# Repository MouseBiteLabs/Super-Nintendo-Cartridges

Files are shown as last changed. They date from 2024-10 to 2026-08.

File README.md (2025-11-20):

# Super Nintendo Game Cartridges

This is a repository listing all of my Super Nintendo Cartridge board variants. These *do not* include variants with special chips, such as SA-1 or the Super Game Boy boards. This repository is for the "standard" mapping types.

Use the following table (or navigate the above folders) for information on each specific baord type. <a href="https://github.com/MouseBiteLabs/Super-Nintendo-Cartridges/wiki">Please also review the wiki for more information.</a>

Note that the boards listed below are planned for development. No dates for upload are guaranteed.

## SNES Board Variants

| **Board Name** | **Board Number** | **Max ROM Size** | **Max RAM Size** | **Mappings Supported** | **Multicart Support?** | **Memory Family Used** |
|---|---|---|---|---|---|---|
| <a href="https://github.com/MouseBiteLabs/Super-Nintendo-Cartridges/tree/main/Advanced%20Flash">Advanced Flash</a> | SNES-8XJ4D-01A | 8 MB | 32 KB | LoROM, HiROM, ExLoROM, ExHiROM | Yes (2 games; 4MB ROM, 32KB RAM)  | Type A (M29F160) |
| <a href="https://github.com/MouseBiteLabs/Super-Nintendo-Cartridges/tree/main/LoROM%20Flash">LoROM Flash</a> | SNES-8XL8D-01A | 8 MB | 128 KB | LoROM, ExLoROM | Yes (2 games; 4MB ROM, 32KB RAM)  | Type A (M29F160) |
| <a href="https://github.com/MouseBiteLabs/Super-Nintendo-Cartridges/tree/main/HiROM%20Flash">HiROM Flash</a> | SNES-8XH8D-01A | 8 MB | 128 KB | HiROM, ExHiROM | Yes (2 games; 4MB ROM, 32KB RAM)  | Type A (M29F160) |
| <a href="https://github.com/MouseBiteLabs/Super-Nintendo-Cartridges/tree/main/Advanced%20UV">Advanced UV</a> | SNES-8XJ8D-01C | 8 MB | 128 KB | LoROM, HiROM, ExLoROM, ExHiROM | Yes (2 games; 4MB ROM, 32KB RAM)  | Type C (27C322) |
| <a href="https://github.com/MouseBiteLabs/Super-Nintendo-Cartridges/tree/main/Basic%20UV">Basic UV</a> | SNES-4NJ8D-01C | 4 MB | 128 KB | LoROM, HiROM | No | Type C (27C160) |
| <a href="https://github.com/MouseBiteLabs/Super-Nintendo-Cartridges/tree/main/SA-1">SA-1</a> | SNES-4SA8S-01C | 4 MB | 128 KB | N/A | No | Type C (27C322) |

## Naming Convention

| SNES | \- | 8 | X | J | 4 | D | \- | 01 | A |
| --- | -- | --- | --- | --- | --- | --- | -- | --- | --- |
| Super Nintendo Entertainment System | | Max ROM Size (MB) | Ex Mode Support | Mapper Type(s) | Max RAM Size | Multicart Support | | Revision | Memory Family |
| | | 1 | N = No | L = LoROM | 0 = None | S = Single game | | | A = New EEPROM (M29F160) |
| | | 2 | X = Yes | H = HiROM | 1 = 2 KB | D = Multicart (split max ROM space)  | | | B = NOS EEPROM (29F016, 29F032, 29F033) |
| | | 4 | | J = Both | 2 = 8 KB | M = Multicart (double max ROM space) | | | C = UV EPROMs (27C160, 27C322, etc) |
| | | 6 | SA = | SA1 | 4 = 32 KB | | | | |
| | | 8 | | | 8 = 128 KB | | | | |

## License

<br />This work is licensed under a <a rel="license" href="http://creativecommons.org/licenses/by-sa/4.0/">Creative Commons Attribution-ShareAlike 4.0 International License</a>. You are able to copy and redistribute the material in any medium or format, as well as remix, transform, or build upon the material for any purpose (even commercial) - but you **must** give appropriate credit, provide a link to the license, and indicate if any changes were made.

©MouseBiteLabs 2024

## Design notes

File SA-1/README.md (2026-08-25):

# Super Nintendo SA-1 Cartridge (SNES-4SA8S-01C)

# V1.1 IS UNTESTED

This is a SNES cartridge circuit board that houses the proprietary SA-1 processor that was used in a variety of more advanced SNES games. This board should be able to be used as a replacement for all released SA-1 games, as well as many (if not all) SA-1 homebrews or enhanced games. The ROM can be programmed to the popular 27C160 or 27C322 UV EPROM chips, or if you want to use more modern and new components, you can use <a href="https://github.com/MouseBiteLabs/ROM-Adapter-Boards/tree/main/29F160%20to%20UV%20EPROM">my 29F160 to UV EPROM adapter boards</a>. I have also included two options for battery management - a donor MM1026 chip from an original SA-1 cartridge (that has it), or if an MM1026 is not available to use you can use the modern TPS3613 battery management IC.

FRONT

BACK

The board can fit in SNES shells for games that used enhancement chips, as well as standard SNES games (with some minor cutting), and provides:
- Up to 4 MB of ROM space
- Up to 128 KB of RAM space

All gerbers and source files can be found in this repo, as again, this project is fully open source. Please read all instructions before attempting the project.

## V1.0 Error

If you have a v1.0 board, you can use this web applet by Bonzo to fix your ROM before programming it: https://eprom-pin-swapper.vercel.app/?preset=bmsa1

You will need to do this to any ROM going onto a v1.0 board before soldering in the chip.

## Important Things Before You Start

1) <a href="https://github.com/MouseBiteLabs/Super-Nintendo-Cartridges/wiki">Please review the wiki for more information about using the circuit boards, instructions for how to program them, and example builds.</a>
2) This project requires you remove the SA-1 chip from an original SA-1 SNES cartridge - <a href="https://en.wikipedia.org/wiki/List_of_Super_NES_enhancement_chips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">you can find a list of SA-1 games that you can use as a donor here (make sure you sort by chip type)</a>. This will require a hot air rework station or a hot plate. This will also require extensive soldering capabilities - do not attempt this project if you do not have sufficient soldering experience.
3) When soldering parts on, it's a good idea to put kapton tape or otherwise cover the bottom cartridge edge. You do not want to get solder on the cartridge contacts.
4) I am not responsible for any damage you do to your self or your property. Attempt this project at your own risk.
5) I do not guarantee design compatibility. You may encounter issues with certain games. There is also a chance I have made an error in the design or the BOM - if this is the case, I will do everything I can to address the problem as quickly as possible.
6) If you are using this board to make games other than for personal use, you must have permission from the originator to use and distribute any ROM images or other related material. You are responsible for making sure you adhere to any license requirements.

DO NOT use my circuit boards for profiting from stolen work - this especially includes homebrew content, ROM hacks, and using fan-made labels without permission from the originator. **Support ALL original creators!**

## Board Characteristics and Order Information

The zipped folder contains all the gerber files for this board. The following options **must** be chosen when ordering boards for yourself.

- Thickness: 1.2mm
- Surface Finish: ENIG
- Gold Fingers: Yes, 30° chamfer

You can use the zipped folder at any board fabricator you like (NOT YET AVAILABLE). You may also buy the board from PCBWay using this link (disclosure: I receive 10% of the sale value to go towards future PCB orders of my own):

<a href="https://www.pcbway.com/">PCB from PCBWay</a>

### Purchase from My Website

You can purchase this circuit board at my website, [https://mousebitelabs.store](https://mousebitelabs.store). Click the following image to be directed to the specific item listing:

<a href="https://mousebitelabs.store/products/super-nintendo-cartridge-circuit-board-sa-1">PCB from MouseBiteLabs</a>

### Purchase from Etsy

I also offer the board on Etsy, if you would rather purchase through there - click the banner to be redirected. (NOT YET LIVE)

<a href="https://mousebitelabs.etsy.com">PCB from Etsy</a> 

## Required Equipment

- You will need basic tools, like a soldering iron, hot plate, and/or hot air rework station.
- This board is **NOT** flashable with any cart flasher (until someone adds that capability) so you need a way to program the ROM chip(s) before soldering them on. There are a few ways I accomplish this:
  - Using the <a href="https://xgecu.myshopify.com/products/xgecu-new-t48-tl866-3gprogrammer-v12-01-support-28000-ics-for-spi-nor-nand-flash-emmc-bga153-162-169-100-221-tsop-sop-plcc">T48 programmer</a> with my <a href="https://github.com/MouseBiteLabs/27C322-TL866-Adapter">27C322 to TL866 Programming Adatper</a> board. The programming adapter is compatible with the T48, and it allows you to program the 42-pin EPROMs (27C160 and 27C322) with the 40-pin T48 programmer.
  OR
  - Using the <a href="https://www.mcumall.com/store/index.php?route=product/product&path=66&product_id=85">GQ4x4 programmer</a> with the ZIF adapter board that comes with it.
  OR
  - If you are using the 29F160 ROM adapter boards to place into the 27C322 footprint, you can program the 29F160 chips with the <a href="https://xgecu.myshopify.com/products/xgecu-new-t48-tl866-3gprogrammer-v12-01-support-28000-ics-for-spi-nor-nand-flash-emmc-bga153-162-169-100-221-tsop-sop-plcc">T48 programmer</a> and the <a href="https://xgecu.myshopify.com/products/100-original-xgecu-adp_f48_ex-1-tsop48-special-adapter-for-nor-flash-only-use-on-t48-tl866-3g-programmer">TSOP48 adapter</a>.
- You will need to do some shell cuts to get the board to fit if you're using a standard SNES cartridge shell (detailed later). I recommend using a file set - <a href="https://www.amazon.com/gp/product/B07R3R9461">I bought this one.</a> 

## How to Program

<a href="https://github.com/MouseBiteLabs/Super-Nintendo-Cartridges/wiki/Preparing-the-ROM">Please check out the wiki pages on how to prepare the ROM and program the cartridge.</a>

## Board Configurations

On this board, there are two sets of solder jumpers that need to be either bridged or not bridged. Furthermore, there are three two-way solder jumpers that are labeled SJx. Solder from the middle pad to the left or right pads as determined by the game you're making and parts you're using.

### JP1 - Internal RAM (IRAM) Configuration

This pad is bridged **by default**. If you wish to disconnect JP1, you must use a knife to cut the copper trace between the two pads of JP1. The only time this is applicable is for extremely specific SA-1 games that use the SA-1's internal RAM to save, instead of external RAM. There is only **one** instance of this that I was able to find - a Japan-only game called <a href="https://superfamicom.org/info/pachi-slot-monogatari-pal-kougyou-special">Pachi-Slot Monogatari: PAL Kougyou Special.</a> After severing JP1, you will need to connect a wire to the pad directly below JP1 to the battery bus (accessible on the positive pin of CB).



### JP2 - Battery Bypass Pads

If your game does not require the use of a backup battery because it doesn't save data, then you need to bridge the pads on JP2. You will notice that this is located underneath U4, which is the battery backup chip. Therefore you will not be able to bridge these pads if you are using U4. If you are instead using U5 for the battery management, then be sure **not** to bridge JP2.

### SJ1 - Region Selection

Solder the middle pad (SA-1 pin 127) to GND for NTSC or VCC for PAL. 

### SJ2 - SRAM Chip

If your game uses SRAM, and you are using the 6264 size of SRAM (like the AS6C6264), then solder to the left pad accordingly. If your game uses the 62256 or 1008 size SRAM, then solder to the right pad.

**NOTE:** If you are using a 6264 SRAM chip, you **must** populate R13 with a 10k ohm resistor (see BOM section below).

### SJ3 - UV EPROM Selection

This is pretty self explanatory. Solder according to the UV EPROM part number you are using (or faking with my ROM adapter board).

## Shell Cut Guide

The board shape takes into account both enhancement chip SNES games (like the ones that used the SA-1 chip) as well as the standard SNES shells for regular SNES games. The enhancement chip games add the two extra sets of 8 pins on either side of the cartridge edge, so if you're using a standard SNES shell, you'll need to cut spaces for those pins to stick through. <a href="https://github.com/MouseBiteLabs/Super-Game-Boy-Plus#standard-46-pin-snes-shell-cuts">Here are the example pictures from my Super Game Boy Plus guide on how to do this</a>. Simply mark with a sharpie on the shell where to cut, then use a file or some other tool to make those cuts to allow the extra pins to stick through.

370103546-1bbc2b1e-a284-4a2d-8b2a-e84a3a882a5d

370104005-20fd10d5-1b87-485e-89ae-0a075d0c2f13

## Extra Components

There are a handful of components on the board that never appear in any SA-1 game, and some that show up in a few but not all. A deeper analysis could provide more insight into the functions and rationale behind these added footprints, but that's not something I'm interested in performing myself. Generally, you should be ok to omit these parts. To indicate these, I bordered the components that are *usually* not required with a dashed line instead of solid lines. Those components are:

- R4, which is normally shorted on every cartridge (if you want to add a series resistor here, you must first cut the trace between the pads)
- FB1-FB8, which are ferrite beads for filtering high frequency noise, seen in a handful of cart types but likely not required (like R4, these are shorted by default)
- C13 and C14 *never* appear populated on any SA-1 board from what I can find on SNES Central

If you run into weird issues with your games, perhaps adding one/some of these components could aid in fixing them. Feel free to update me with any information you wish to share in this regard and I will update accordingly.

- C15, a 33pF capacitor, appears on boards released later in the life of the SNES, sometime around the end of 1996 as far as I can tell from board pictures on SNES Central. It is likely not *required* for operation, but perhaps it fixes some weird edge cases or graphical issues. In any case, I believe it's the same value as C12 (will confirm if I get the right board to measure it), so it doesn't hurt to include it in my opinion. But you technically shouldn't need it.

## Special Case Components

Two components have dashed boxes, but are required on the board only for specific scenarios:

- R12 will be populated *only if* you are making a game with RAM, **but not a back-up battery.** DO NOT populate R12 if you have either U4 or U5 populated.
- R13 will be populated *only if* you are using a 6264 SRAM chip, and if you are using anything larger this will remain unpopulated (this is a stand-in for some of the unmarked and masked off components near the battery on original boards).

## Extra Pads (Experimental Use)

I added a few pads to access unused pins if anyone wants to experiment with them.

- RA22 and RA23 go to SA-1 pins 80 and 81, respectively. These are extra ROM address pins. Using RA22 can increase the addressible ROM space to 8 MB, and RA23 can further expand it to 16 MB. This functionality is, as far as I know, theoretical. If someone knows of any homberew games that use this extra space, feel free to let me know.
- /ROMSEL is not used on this cartridge, but along with /WR, perhaps these could be wired up to a breakout board with ROM chips on them for programming through the cart edge using something like the <a href="https://github.com/sanni/cartreader">OSCR</a>. Again, this is theoretical and may not be possible - but the pads are there for whoever wants to experiment.
- The SRAM maxes out at 128KB, however one pin on the SA-1 (pin 104) that is unused has been reported to be an extra SRAM pin, which could theoretically expand the size of the SRAM to a maximum of 256KB. This extra address pin is connected to pin 1 on the SRAM package, which is an NC pin for 32-pin SRAM chips linked in the BOM section.

## Estimating Battery Life

To accurately estimate the battery life, measure the voltage across R1 using a multimeter in DC mV mode, touching the probes to the two test point pads on either side of R1 (on the back of the board). You should read something around 1 mV or less. If you are severely higher than 10 mV, like in the 100's of mV, then you have a problem on your board. (Did you *inappropriately* populate R12?)

Once you have a suitable voltage, find the milliamp-hour rating of your selected battery (preferrably from a datasheet). For example, a Renata CR2032 battery is rated for 225 mAh.

Now to estimate battery life, take the voltage measurement in mV and the battery rating in mAh, and plug it into this equation: 

Time (years) = Resistance of R1 (ohms) * Battery capacity (mAh) / Voltage (mV) / 8760

The factor of 8760 is for converting years to hours (24 hours in a day, 365 days in a year). The resistance of R1 is 1000 ohms. So for an example, if you measured 1 mV on R1 and are using a Renata CR2032, you would get 1000 * 225 / 1 / 8760 = **25.7 years.**

## Troubleshooting

<a href="https://github.com/MouseBiteLabs/Super-Nintendo-Cartridges/wiki/Troubleshooting-Tips">Please check out the wiki pages for troubleshooting tips.</a>

## Bill of Materials (BOM)

- Populate Group A for all carts. It will be the only group of components you need if you have no SRAM or battery on the board.
- Populate Group B to add battery back-up for save data retention.
- Populate Group C1 or C2 depending on the battery management IC you want to use. Only required if Group B is populated.
- Populate Group D to add RAM to the board (usually for save data retention).
- Populate Group E **ONLY IF** you have **NOT** populated Group B, Group C1, and Group C2 components.
- Populate Group F **ONLY IF** you are using 6264 SRAM from Group D - other SRAM types (62256 or 1008) **do not use** Group F components.

### Example Builds

Please see <a href="https://github.com/MouseBiteLabs/Super-Nintendo-Cartridges/wiki/SA%E2%80%901">the example page in the wiki</a> for a companion in keeping track of what parts are necessary for a given build. Equivalent PCB names from original SNES cartridges (SHVC-xxxx) are given when applicable.

### Group A - All Carts

| Reference | Value/Part Number | Package | Description | Source |
| --- | --- | --- | --- | --- |
| C1 | 22u | Radial 2.5mm spacing | Aluminum Electrolytic Capacitor | [https://mou.sr/4lzfiK1](https://mou.sr/4lzfiK1) |
| C2 | 0.01uF | 0603 | Capacitor (MLCC) | [https://mou.sr/3AsRwK1](https://mou.sr/3AsRwK1) |
| C4 | 0.01uF | 0603 | Capacitor (MLCC) | [https://mou.sr/3AsRwK1](https://mou.sr/3AsRwK1) |
| C6 | 0.1uF | 0603 | Capacitor (MLCC) | [https://mou.sr/3ENc15O](https://mou.sr/3ENc15O) |
| C7 | 0.01uF | 0603 | Capacitor (MLCC) | [https://mou.sr/3AsRwK1](https://mou.sr/3AsRwK1) |
| C8 | 0.01uF | 0603 | Capacitor (MLCC) | [https://mou.sr/3AsRwK1](https://mou.sr/3AsRwK1) |
| C9 | 0.01uF | 0603 | Capacitor (MLCC) | [https://mou.sr/3AsRwK1](https://mou.sr/3AsRwK1) |
| C10 | 0.01uF | 0603 | Capacitor (MLCC) | [https://mou.sr/3AsRwK1](https://mou.sr/3AsRwK1) |
| C12 | 33pF | 0603 | Capacitor (MLCC) | [https://mou.sr/4cYZLxw](https://mou.sr/4cYZLxw) |
| C15 | 33pF | 0603 | Capacitor (MLCC) | [https://mou.sr/4cYZLxw](https://mou.sr/4cYZLxw) |
| R2 | 510k | 0603 | Resistor | [https://mou.sr/3zi8ayj](https://mou.sr/3zi8ayj) |
| R3 | 1k | 0603 | Resistor | [https://mou.sr/3U0EvS4](https://mou.sr/3U0EvS4) |
| R5 | 1.5k | 0603 | Resistor | https://mou.sr/4aiZKUE |
| R6 | 220 | 0603 | Resistor | [https://mou.sr/3ARwrf3](https://mou.sr/3ARwrf3) |
| U1 | 27C322, 27C160 | DIP-42 | UV EPROM | AliExpress, eBay |
| U3 | SA-1 | QFP-128 | Co-processor | Donor cartridge |

### Group B - Adds Backup Battery

You will need to populate Group C1 or Group C2 in addition to Group B in order to add battery management to the board.

| Reference | Value/Part Number | Package | Description | Source |
| --- | --- | --- | --- | --- |
| B1 | CR2032 | CR2032 | Coin Cell Battery | [https://mou.sr/3Wj2m0G](https://mou.sr/3Wj2m0G) |
| R1 | 1k | 0603 | Resistor | [https://mou.sr/3U0EvS4](https://mou.sr/3U0EvS4) |

### Group C1 - Adds Battery Management IC (Donor Cart)

Use parts from Group C1 **OR** C2. Do not use both. Group C1 or C2 are required if a save battery is on the board.

| Reference | Value/Part Number | Package | Description | Source |
| --- | --- | --- | --- | --- |
| C11 | 0.01uF | 0603 | Capacitor (MLCC) | [https://mou.sr/3AsRwK1](https://mou.sr/3AsRwK1) |
| U4 | MM1026 | SOIC-8W | Battery Management | Donor cartridge |

### Group C2 - Adds Battery Management IC (New Parts)

Use parts from Group C1 **OR** C2. Do not use both. Group C1 or C2 are required if a save battery is on the board.

| Reference | Value/Part Number | Package | Description | Source |
| --- | --- | --- | --- | --- |
| C16 | 0.01uF | 0603 | Capacitor (MLCC) | [https://mou.sr/3AsRwK1](https://mou.sr/3AsRwK1) |
| R9 | 130k | 0603 | Resistor | [https://mou.sr/3MjXliy](https://mou.sr/3MjXliy) |
| R10 | 49.9k | 0603 | Resistor | [https://mou.sr/3BBcDgp](https://mou.sr/3BBcDgp) |
| U5 | TPS3613 | MSOP-10 | Battery Management | [https://mou.sr/45Ir2kh](https://mou.sr/45Ir2kh) |

### Group D - Adds SRAM

Select U2 according to the size of RAM your game requires - 6264 (8KB), 62256 (32KB), or 1008 (128KB).

| Reference | Value/Part Number | Package | Description | Source |
| --- | --- | --- | --- | --- |
| CB | 22u | Radial 2.5mm spacing | Aluminum Electrolytic Capacitor | [https://mou.sr/4lzfiK1](https://mou.sr/4lzfiK1) |
| C5 | 0.01uF | 0603 | Capacitor (MLCC) | [https://mou.sr/3AsRwK1](https://mou.sr/3AsRwK1) |
| U2 | AS6C6264/62256/1008 | SOP-28/SOP-32 | SRAM | https://mou.sr/4qIDtZh |

### Group E - For Using SRAM as Work RAM (no battery backup)

Only populate Group E **IF** your game does not have Group B or Group C components. **DO NOT POPULATE IF YOU HAVE A SAVE BATTERY ON THE BOARD.**

| Reference | Value/Part Number | Package | Description | Source |
| --- | --- | --- | --- | --- |
| R12 | 10k | 0603 | Resistor | [https://mou.sr/3riR7IH](https://mou.sr/3riR7IH) |

### Group F - Only If Using 6264 SRAM

Only populate Group F **IF** you are using 6264 series SRAM.

| Reference | Value/Part Number | Package | Description | Source |
| --- | --- | --- | --- | --- |
| R13 | 10k | 0603 | Resistor | [https://mou.sr/3riR7IH](https://mou.sr/3riR7IH) |

## Revision History

### v1.0 - Initial Release

## Acknowledgements

- Special thanks to Bonzo for providing an SA-1 board that I used for board scans and component measurements to develop the majority of this board!
- Huge, endless thanks to the following people for their hard work and resources:
  - <a href="https://problemkaputt.de/fullsnes.htm#snescartsa1games">nocash's SNES resources</a> were the single most helpful resource for this project.
  - <a href="https://github.com/VitorVilela7/SNES-SA-1-doc">VitorVilela's GitHub page</a> helped for filling out information about some of the pins, their connections, and component values.
  - <a href="https://snescentral.com/pcblisting.php">SNES Central's PCB archives</a> provided pictures of all the other major SA-1 game PCBs I did not have myself.
  - <a href="https://snescentral.com/pcblisting.php">This thread detailing Arthrimus/Markfrizb's SA-1 boards</a> helped for cross-referencing component values.
- Continual thanks to all in the nesdev community for their resources, design tips, and support throughout the past half-decade. This design was one of my original ones that was improved through their help and feedback when I was first starting out.

## License

<br />This work is licensed under a <a rel="license" href="http://creativecommons.org/licenses/by-sa/4.0/">Creative Commons Attribution-ShareAlike 4.0 International License</a>. You are able to copy and redistribute the material in any medium or format, as well as remix, transform, or build upon the material for any purpose (even commercial) - but you **must** give appropriate credit, provide a link to the license, and indicate if any changes were made.

©MouseBiteLabs 2025

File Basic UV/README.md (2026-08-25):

# Super Nintendo Basic UV Cartridge (SNES-4NJ8D-01C) 

# Order at your own risk -- v1.1 is untested

This is an updated design of my old <a href="https://mousebitelabs.com/2019/08/12/how-to-make-a-snes-reproduction-cartridge-quick-guide/">SNES Basic cartridge boards</a>, which can use the original mask ROM chips from SNES carts, or the older 27C160 UV EPROM chips. You can even use my <a href="https://github.com/MouseBiteLabs/ROM-Adapter-Boards/tree/main/29F160%20to%20UV%20EPROM">29F160 to 27C160 adapter boards</a>, which use brand new 29F160 flash chips if you don't want to deal with old parts. 

Functionally, this design is the same as the older one, but under the hood I have ported the project over from Eagle to KiCad, and heavily cleaned up the schematic and some of the trace routings. I also added support for the MAD-1 chip from a donor board, unlocking a lot of potential for replacing old or damaged games. This version is also fully open source.





This cartridge covers a large portion of the SNES library, capable of any standard cartridge **but not those with co-processors, such as SA-1 or SuperFX.** You can backup games onto it with the following settings:
- HiROM and LoROM memory maps
- Up to 4 MB of ROM space
- Up to 128 KB of RAM space

All gerbers and source files can be found in this repo, as again, this project is fully open source. Please read all instructions before attempting the project.

## Important Things Before You Start

1) <a href="https://github.com/MouseBiteLabs/Super-Nintendo-Cartridges/wiki">Please review the wiki for more information about using the circuit boards, instructions for how to program them, and example builds.</a>
2) When soldering parts on, it's a good idea to put kapton tape or otherwise cover the bottom cartridge edge. You do not want to get solder on the cartridge contacts.
3) I am not responsible for any damage you do to your self or your property. Attempt this project at your own risk.
4) I do not guarantee design compatibility. You may encounter issues with certain games. There is also a chance I have made an error in the design or the BOM - if this is the case, I will do everything I can to address the problem as quickly as possible.
5) If you are using this board to make games other than for personal use, you must have permission from the originator to use and distribute any ROM images or other related material. You are responsible for making sure you adhere to any license requirements.

DO NOT use my circuit boards for profiting from stolen work - this especially includes homebrew content, ROM hacks, and using fan-made labels without permission from the originator. **Support ALL original creators!**

## Board Characteristics and Order Information

The zipped folder contains all the gerber files for this board. The following options **must** be chosen when ordering boards for yourself.

- Thickness: 1.2mm
- Surface Finish: ENIG
- Gold Fingers: Yes, 30° chamfer

You can use the zipped folder at any board fabricator you like. You may also buy the board from PCBWay using this link (disclosure: I receive 10% of the sale value to go towards future PCB orders of my own):

<a href="https://www.pcbway.com/project/shareproject/Super_Nintendo_Basic_UV_Cartridge_9dc9d5f4.html">PCB from PCBWay</a>

### Purchase from My Website

You can purchase this circuit board at my website, [https://mousebitelabs.store](https://mousebitelabs.store). Click the following image to be directed to the specific item listing:

<a href="https://mousebitelabs.store/products/super-nintendo-cartridge-circuit-board-basic-uv">PCB from MouseBiteLabs</a>

### Purchase from Etsy

I also offer the board on Etsy, if you would rather purchase through there - click the banner to be redirected.

<a href="https://mousebitelabs.etsy.com/listing/785820265">PCB from Etsy</a> 

## Required Equipment

- You will need basic tools, like a soldering iron.
- If you are using this board with any OEM parts, like the CIC or MAD-1 or even a full replacement cartridge, you will... need that cartridge.
- If you are not using an original ROM chip, you need a way to program the new ROM chip. There are a few ways I have programmed them in the past:
  - You can use the <a href="https://xgecu.myshopify.com/products/xgecu-new-t48-tl866-3gprogrammer-v12-01-support-28000-ics-for-spi-nor-nand-flash-emmc-bga153-162-169-100-221-tsop-sop-plcc">T48 programmer</a> to program 27C801 or equivalent 1MB UV EPROMs for U3.
  - Using the T48 programmer with my <a href="https://github.com/MouseBiteLabs/27C322-TL866-Adapter">27C322 to TL866 Programming Adatper</a> board allows you to program 27C160 UV EPROMs.
  - The <a href="https://www.mcumall.com/store/index.php?route=product/product&path=66&product_id=85">GQ4x4 programmer</a> (and the ZIF adapter board that comes with it) can also be used to program UV EPROMs.
  - The T48 programmer with the <a href="https://xgecu.myshopify.com/products/100-original-xgecu-adp_f48_ex-1-tsop48-special-adapter-for-nor-flash-only-use-on-t48-tl866-3g-programmer">TSOP48 adapter</a> can be used to program 29F160 chips on my <a href="https://github.com/MouseBiteLabs/ROM-Adapter-Boards/tree/main/29F160%20to%20UV%20EPROM">29F160 to 27C160 adapter boards</a> placed in the U4 socket, or to program 29F016 chips on my <a href="https://github.com/MouseBiteLabs/ROM-Adapter-Boards/tree/main/SNES%20to%20TSOP">29F016 to SNES adapter boards</a> placed in the U3 socket.
  - If you are using the <a href="https://github.com/MouseBiteLabs/ROM-Adapter-Boards/tree/main/29F160%20to%20UV%20EPROM">29F160 to 27C160 adapter board</a>, and you install it into U4 along with the pin to connect /WE between the adapter and the cartridge, you can use the <a href="https://github.com/sanni/cartreader">OSCR</a> to load the game and save data onto the catridge, after the cartridge is assembled.
- This cartridge uses the PIC12F629 with the <a href="https://sd2snes.de/blog/cool-stuff/supercic">SuperCIC code</a> to fake out the lockout chip. You will need a way to program these PIC chips. I use the T48 to do so, but you can also use something like the <a href="https://www.microchip.com/en-us/development-tool/pg164130">PICkit 3.</a> Note that if you have region modded your SNES, you won't need the lockout chips in the cartridges.

## How to Program

<a href="https://github.com/MouseBiteLabs/Super-Nintendo-Cartridges/wiki/Preparing-the-ROM">Please check out the wiki pages on how to prepare the ROM and program the cartridge.</a>

### Important note for 27C801

If you are using a UV EPROM in the U3 socket (likely the 27C801), then the ROM file you load onto the chip must be swapbinned. This is covered in the wiki link above.

## Board Configurations

This board is highly customizable. You *do not* need every single part on this board to make a game. The game you want to make is mainly dependent on the memory mapping (LoROM/HiROM), the ROM size, and the RAM size. Depending on your needs, you only need to solder on certain components, which you can find below in the BOM section. You will also need to configure the game with the various solder jumpers on the back of the board.

<a href="https://github.com/MouseBiteLabs/Super-Nintendo-Cartridges/wiki/Basic-UV">**I highly recommend checking out the various examples of board configurations on the wiki.**</a>

### Components Required

I've split up the requisite parts into a few different "Groups" which you can find a comprehensive list for in the BOM section a few sections down from this one.

- **Every board needs Group A components.** You can make games that have no RAM and are up to 4 MB large with this configuration.
- If you need battery-backed RAM, **add Group B components.** This will add up to 128 KB of RAM space. You will then need to add either...
  - **Group C components** if you are using the 74HCT139 decoder chip (which does not require a donor cartridge),
 
  OR
  
  - **Group D components** if you are using the MAD-1 mapper (which requires a donor cartridge).

Along with these groups, please also follow the configurations detailed in the following sections.

### The Lockout Chip

There are two sockets and two capacitors labeled "U2" and "C2," respectively. Only populate ONE set of these. Do not populate both. The 16-pin socket is for the original CIC chip from a donor cartridge, and the 8-pin socket is for the SuperCIC clone chip using the PIC12F629 that you have to program yourself. If your SNES is modded to be region-unlocked, then you don't need either of these chips.



### Hi/Lo Socket Selection

If your game is the LoROM mapping type, solder U3 or U4 in the bottom set of sockets (labeled "LO" on the left side) and, if necessary, U6L or U8L. If your game is of the HiROM mapping type, solder U3 or U4 in the top set of sockets (labeled "HI" on the left side) and, if necessary, U6H or U8H.



### Mapper Bypass Solder Jumper

This is the only set of solder jumper pads on the front of the board. If your game does not use SRAM, then you must solder these pads together. **Do not solder these pads if your game uses SRAM.**



### LoRom/HiROM Solder Jumpers

For these 3-segment pads, use a solder bridge on the middle pad to either side depending on the option you need. There are a handful of them across the board, and not all of them are necessary for you to set - though, importantly, if you want to take the guesswork out of it, **you can configure all of them without any ill side effects** to make it simpler.

1) The one Lo/Hi jumper on the bottom left of the board, behind U3, only need to be set if you have a ROM in the U3 socket.
2) The two Lo/Hi jumpers on the right side, behind U6L and U6H (the MAD-1s), only need to be set if you are using U8L or U8L (the 74HCT139s)
3) The four Lo/Hi jumpers at the top of the board only need to be set if you are using SRAM on the board
4) The one Lo/Hi jumper in the middle of the board behind U4 only needs to be set if you are using the <a href="https://github.com/MouseBiteLabs/ROM-Adapter-Boards/tree/main/29F160%20to%20UV%20EPROM">29F160 to 27C160 adapter boards</a> in the U4 socket



### SRAM Size

The set of pads at the top left underneath the SRAM chip configure the size of the SRAM that the SNES will see. All pads must be configured if you are using SRAM, and each set of 2 should be soldered in the same direction. The example picture below shows a game configured for 256 Kbit of SRAM. **It is important to note these numbers represent the SRAM in BITS, not BYTES. To figure out the BYTES of SRAM, take the numbers here and divide by 8.**



### U4 Configuration Pads

These two sets of 3-way jumpers only need to be set if you have something populated in U4. Solder the middle pads to the left if you are using a 27C160 UV EPROM, or solder the middle pads to the right if you are using my <a href="https://github.com/MouseBiteLabs/ROM-Adapter-Boards/tree/main/29F160%20to%20UV%20EPROM">29F160 to 27C160 adapter boards</a>.

(Remember: the LoROM/HiROM pads to the right of these do not need to be set if you are using the 27C160.)



## Estimating Battery Life

To accurately estimate the battery life, measure the voltage across R1 using a multimeter in DC mV mode, touching the probes to the two test point pads on either side of R1. You should read something around 1 mV or less. If you are severely higher than 10 mV, like in the 100's of mV, then you have a problem on your board.

Once you have a suitable voltage, find the milliamp-hour rating of your selected battery (preferrably from a datasheet). For example, a Renata CR2032 battery is rated for 225 mAh.

Now to estimate battery life, take the voltage measurement in mV and the battery rating in mAh, and plug it into this equation: 

Time (years) = Resistance of R1 (ohms) * Battery capacity (mAh) / Voltage (mV) / 8760

The factor of 8760 is for converting years to hours (24 hours in a day, 365 days in a year). The resistance of R1 is 1000 ohms. So for an example, if you measured 1 mV on R1 and are using a Renata CR2032, you would get 1000 * 225 / 1 / 8760 = **25.7 years.**

## Troubleshooting

<a href="https://github.com/MouseBiteLabs/Super-Nintendo-Cartridges/wiki/Troubleshooting-Tips">Please check out the wiki pages for troubleshooting tips.</a>

## Bill of Materials (BOM)

The component groups required for the build you want to make are detailed above.

### Group A - Up to 4 MB ROM, No RAM

In the following table, choose **one** of the options for U2.

| Reference | Value/Part Number | Package | Description | Source |
| --- | --- | --- | --- | --- |
| C1 | 22u | Radial 2.5mm spacing | Aluminum Electrolytic Capacitor | [https://mou.sr/4lzfiK1](https://mou.sr/4lzfiK1) |
| C2 | 0.1u | Radial 2.5mm spacing | Ceramic Capacitor | [https://mou.sr/481ILov](https://mou.sr/481ILov) |
| U2 | CIC | DIP-16 | Region Lockout Chip | Donor cartridge |
| U2 | PIC12F629 | DIP-8 | PIC Microcontroller | [https://mou.sr/3XuEZzO](https://mou.sr/3XuEZzO) |
| U2 | PIC12F629 | SOIC-8 | PIC Microcontroller | [https://mou.sr/4dSUh90](https://mou.sr/4dSUh90) |

In the following table, choose **one** of the following options for U3 or U4. If you use a part in U3, then populate C3. If you use a part in U4, populate C4.

| Reference | Value/Part Number | Package | Description | Source |
| --- | --- | --- | --- | --- |
| C3 | 0.1u | Radial 2.5mm spacing | Ceramic Capacitor | [https://mou.sr/481ILov](https://mou.sr/481ILov) |
| C4 | 0.1u | Radial 2.5mm spacing | Ceramic Capacitor | [https://mou.sr/481ILov](https://mou.sr/481ILov) |
| U3 | Mask ROM | DIP-32/DIP-36 | Original SNES Mask ROM | Donor Cartridge |
| U3 | 27C801 | DIP-32 | UV EPROM | AliExpress, eBay |
| U3 | SNES-to-TSOP PCB | DIP-36 | Adapter board for 29F016 | [https://github.com/MouseBiteLabs/ROM-Adapter-Boards/tree/main/SNES%20to%20TSOP](https://github.com/MouseBiteLabs/ROM-Adapter-Boards/tree/main/SNES%20to%20TSOP) |
| U4 | 27C160 | DIP-42 | UV EPROM | AliExpress, eBay |
| U4 | 29F160 to UV EPROM PCB | DIP-42 | Adapter board for 29F160 | [https://github.com/MouseBiteLabs/ROM-Adapter-Boards/tree/main/29F160%20to%20UV%20EPROM](https://github.com/MouseBiteLabs/ROM-Adapter-Boards/tree/main/29F160%20to%20UV%20EPROM) |

### Group B - adds 32 KB of RAM

| Reference | Value/Part Number | Package | Description | Source |
| --- | --- | --- | --- | --- |
| B1 | CR2032 | CR2032 | Coin Cell Battery | [https://mou.sr/3Wj2m0G](https://mou.sr/3Wj2m0G) |
| CB | 22u | Radial 2.5mm spacing | Aluminum Electrolytic Capacitor | [https://mou.sr/4lzfiK1](https://mou.sr/4lzfiK1) |
| C5 | 0.1u | Radial 2.5mm spacing | Ceramic Capacitor | [https://mou.sr/481ILov](https://mou.sr/481ILov) |
| R1 | 1k | Axial | Resistor | [https://mou.sr/4hYkrZr](https://mou.sr/4hYkrZr) |
| U5 | AS6C62256 | DIP-28 | SRAM | [https://mou.sr/3HlZ0mh](https://mou.sr/3HlZ0mh) |

### Group B (Optional) - adds 128 KB of RAM (instead of 32 KB)

Replace U5 in Group B above with the part detailed here, and add the other three components. **I personally recommend sticking to the AS6C62256 SRAM chip unless you absolutely need more RAM space.**

| Reference | Value/Part Number | Package | Description | Source |
| --- | --- | --- | --- | --- |
| Q2 | 2N3904 | TO-92-3 | NPN BJT | [https://mou.sr/3HlkU91](https://mou.sr/3HlkU91) |
| R6 | 100k | Axial | Resistor | [https://mou.sr/3Ib4SgO](https://mou.sr/3Ib4SgO) |
| R7 | 10k | Axial | Resistor | [https://mou.sr/42AN0WU](https://mou.sr/42AN0WU) |
| U5 | AS6C1008 | DIP-32  | SRAM | [https://mou.sr/3hNkGxg](https://mou.sr/3hNkGxg) |

### Group C - adds supporting circuitry for battery backed RAM (no donor cart)

| Reference | Value/Part Number | Package | Description | Source |
| --- | --- | --- | --- | --- |
| C8 | 0.1u | Radial 2.5mm spacing | Ceramic Capacitor | [https://mou.sr/481ILov](https://mou.sr/481ILov) |
| D1 | BAT85 | DO-35-2 | Schottky Diode | [https://mou.sr/49GVT4m](https://mou.sr/49GVT4m) |
| D2 | BAT85 | DO-35-2 | Schottky Diode | [https://mou.sr/49GVT4m](https://mou.sr/49GVT4m) |
| D3 | BAT85 | DO-35-2 | Schottky Diode | [https://mou.sr/49GVT4m](https://mou.sr/49GVT4m) |
| Q1 | 2N3904 | TO-92-3 / SOT-23-3 | NPN BJT | THT: https://mou.sr/3HlkU91, SMT: https://mou.sr/3C8piaZ |
| R2 | 100k | Axial | Resistor | [https://mou.sr/3Ib4SgO](https://mou.sr/3Ib4SgO) |
| R3 | 10k | Axial | Resistor | [https://mou.sr/42AN0WU](https://mou.sr/42AN0WU) |
| R4 | 1k | Axial | Resistor | [https://mou.sr/4hYkrZr](https://mou.sr/4hYkrZr) |
| R5 | 10k | Axial | Resistor | [https://mou.sr/42AN0WU](https://mou.sr/42AN0WU) |
| U8 | 74HCT139 | DIP-16 | Decoder | [https://mou.sr/441VXuJ](https://mou.sr/441VXuJ) |

### Group D - adds supporting circuitry for battery backed RAM (donor cart)

| Reference | Value/Part Number | Package | Description | Source |
| --- | --- | --- | --- | --- |
| C6 | 0.1u | Radial 2.5mm spacing | Ceramic Capacitor | [https://mou.sr/481ILov](https://mou.sr/481ILov) |
| U6 | MAD-1 | DIP-16 | Memory Address Decoder | Donor Cartridge |

## Restrictions for v1.0

If you have a v1.0 board, you have the following restrictions:

- Only a replacement CIC chip with the PIC12F629 can be used
- MAD-1 is not supported (the wiring is wrong)
- If you are using a 27C160 EPROM in U4, you must bend up pin 32 and separately wire it to a GND point (like pin 31 on the EPROM)

## Revision History

### v1.1 - Release

- Fix OEM CIC wiring
- Fix MAD-1 wiring
- Add jumpers and extra pins for 29F160 Adapter board support

### v1.0 - Prototype

- Release of the KiCad-ported version of my original SNES Basic cart design
- Removed the "SRAM Enable" pads and made the SRAM always enabled
- Added MAD-1 support to the board

## Acknowledgements

- Continual thanks to all in the nesdev community for their resources, design tips, and support throughout the past half-decade. This design was one of my original ones that was improved through their help and feedback when I was first starting out.

## License

<br />This work is licensed under a <a rel="license" href="http://creativecommons.org/licenses/by-sa/4.0/">Creative Commons Attribution-ShareAlike 4.0 International License</a>. You are able to copy and redistribute the material in any medium or format, as well as remix, transform, or build upon the material for any purpose (even commercial) - but you **must** give appropriate credit, provide a link to the license, and indicate if any changes were made.

©MouseBiteLabs 2025

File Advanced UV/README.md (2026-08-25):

# Super Nintendo Advanced UV Cartridge (SNES-8XJ8D-01C)

This is an updated design of my old <a href="https://mousebitelabs.com/2020/07/08/multi-function-snes-reproduction-board-guide/">SNES Advanced cartridge boards</a>, which utilize older UV EPROM chips 27C160 and/or 27C322. Functionally, this design is the same as the older one, but under the hood I have ported the project over from Eagle to KiCad, and heavily cleaned up the schematic and some of the trace routings. This version is also fully open source.





This cartridge covers over 95% of the entire SNES library, capable of any standard cartridge **but not those with co-processors, such as SA-1 or SuperFX.** You can backup games onto it with the following settings:
- All memory maps supported: LoROM, HiROM, ExLoROM, and ExHiROM
- Can be programmed to operate as a multicart, changing games by pressing the SNES reset button
- Up to 8 MB of ROM space for a single game or 4 MB of ROM space for two games
- Up to 128 KB of RAM space for a single game or two separate banks of 64 KB RAM space for two games

All gerbers and source files can be found in this repo, as again, this project is fully open source. Please read all instructions before attempting the project.

## Tutorial Video

This video is older, but still applies to this board.

Video Tutorial (https://www.youtube.com/watch?v=PpTQDjmsrEo "How to Make a SNES Cartridge")

## Important Things Before You Start

1) <a href="https://github.com/MouseBiteLabs/Super-Nintendo-Cartridges/wiki">Please review the wiki for more information about using the circuit boards, instructions for how to program them, and example builds.</a>
2) When soldering parts on, it's a good idea to put kapton tape or otherwise cover the bottom cartridge edge. You do not want to get solder on the cartridge contacts.
3) I am not responsible for any damage you do to your self or your property. Attempt this project at your own risk.
4) I do not guarantee design compatibility. You may encounter issues with certain games. There is also a chance I have made an error in the design or the BOM - if this is the case, I will do everything I can to address the problem as quickly as possible.
5) If you are using this board to make games other than for personal use, you must have permission from the originator to use and distribute any ROM images or other related material. You are responsible for making sure you adhere to any license requirements.

DO NOT use my circuit boards for profiting from stolen work - this especially includes homebrew content, ROM hacks, and using fan-made labels without permission from the originator. **Support ALL original creators!**

## Board Characteristics and Order Information

The zipped folder contains all the gerber files for this board. The following options **must** be chosen when ordering boards for yourself.

- Thickness: 1.2mm
- Surface Finish: ENIG
- Gold Fingers: Yes, 30° chamfer

You can use the zipped folder at any board fabricator you like. You may also buy the board from PCBWay using this link (disclosure: I receive 10% of the sale value to go towards future PCB orders of my own):

<a href="https://www.pcbway.com/project/shareproject/Super_Nintendo_Advanced_UV_Cartridge_bbc4cabf.html">PCB from PCBWay</a>

### Purchase from My Website

You can purchase this circuit board at my website, [https://mousebitelabs.store](https://mousebitelabs.store). Click the following image to be directed to the specific item listing:

<a href="https://mousebitelabs.store/products/super-nintendo-cartridge-circuit-board-advanced-uv">PCB from MouseBiteLabs</a>

### Purchase from Etsy

I also offer the board on Etsy, if you would rather purchase through there - click the banner to be redirected.

<a href="https://mousebitelabs.etsy.com/listing/836162227">PCB from Etsy</a> 

## Required Equipment

- You will need basic tools, like a soldering iron.
- You need a way to program the ROM chip(s). There are two ways I have programmed them in the past:
  - Using the <a href="https://xgecu.myshopify.com/products/xgecu-new-t48-tl866-3gprogrammer-v12-01-support-28000-ics-for-spi-nor-nand-flash-emmc-bga153-162-169-100-221-tsop-sop-plcc">T48 programmer</a> with my <a href="https://github.com/MouseBiteLabs/27C322-TL866-Adapter">27C322 to TL866 Programming Adatper</a> board. The programming adapter is compatible with the T48, and it allows you to program the 42-pin EPROMs (27C160 and 27C322) with the 40-pin T48 programmer.
  OR
  - Using the <a href="https://www.mcumall.com/store/index.php?route=product/product&path=66&product_id=85">GQ4x4 programmer</a> with the ZIF adapter board that comes with it.
- This cartridge uses the PIC12F629 with the <a href="https://sd2snes.de/blog/cool-stuff/supercic">SuperCIC code</a> to fake out the lockout chip. You will need a way to program these PIC chips. I use the T48 to do so, but you can also use something like the <a href="https://www.microchip.com/en-us/development-tool/pg164130">PICkit 3.</a> Note that if you have region modded your SNES, you won't need the lockout chips in the cartridges.

## How to Program

<a href="https://github.com/MouseBiteLabs/Super-Nintendo-Cartridges/wiki/Preparing-the-ROM">Please check out the wiki pages on how to prepare the ROM and program the cartridge.</a>

## Board Configurations

This board is highly customizable. You *do not* need every single part on this board to make a game. The game you want to make is mainly dependent on the memory mapping (LoROM, HiROM, etc), the ROM size, and the RAM size. Depending on your needs, you only need to solder on certain components, which you can find below in the BOM section. You will also need to configure the game with the various solder jumpers on the back of the board.

<a href="https://github.com/MouseBiteLabs/Super-Nintendo-Cartridges/wiki/Advanced-UV">**I highly recommend checking out the various examples of board configurations on the wiki.**</a>

### Components Required

I've split up the requisite parts into a few different "Groups" which you can find a comprehensive list for in the BOM section a few sections down from this one.

- **Every board needs Group A components.** You can make LoRom or HiROM games that have no RAM and are up to 4 MB large with this configuration.
- If you need RAM space, **add Group B components.** This will add up to 128 KB of RAM space.
- If your game is larger than 4 MB, it will use the ExLoROM or ExHiROM memory mapping. **Add Group C components for this.**
- For multicarts, you can make a board with two games on it up to 4 MB each. You will need Group C components, **as well as Group D components.**

#### Socket Configurations

If your game is the LoROM or ExLoROM mapping type, solder U3 (and U4 if necessary) in the bottom set of sockets (labeled "LO" on the left side). If your game is of the HiROM or ExHiROM mapping type, solder U3 (and U4 if necessary) in the top set of sockets (labeled "HI" on the left side). Furthermore, if you are making a LoROM or ExLoROM game that has SRAM, then populate the U8L socket. If you are making a HiROM or ExHiROM game that has SRAM, then populate the U8H socket. Note that you can populate both U8L and U8H without issue, if you want.

If you are making a multicart, both games must be of the *same* mapping type. You cannot make one HiROM and one LoROM game in a multicart.

Keep in mind that the 27C160 can hold up to 2 MB of ROM data, and the 27C322 can hold up to 4 MB. You can use either of those chips in ROM slots 1 and 2, but if you are going to make an ExLoROM or ExHiROM game, ROM1 needs to be a 27C322. ROM2 in this case *can* be a 27C160, but only if the ROM is 6 MB total in size.

### Solder Jumpers

There are two types of solder jumper pads on the board - the 2-segment and 3-segment. For the 2-segment pads, if they need to be connected, simply bridge the two with solder. For the 3-segment pads, use a solder bridge on the middle pad to either side depending on the option you need.

#### U8 Bypass

This is the only set of pads on the front of the board. If your game does not use SRAM, then you must solder these pads together. **Do not solder these pads if your game uses SRAM.**

#### U3/U4 Configuration

On the reverse side of U3 and U4 are three sets of pads used to set what kind of EPROM you are using, and in the case of the 27C322, what mapping type you are using.



Keep in mind that if you are using both ROM1 and ROM2, both EPROMs *must* be in the same mapping type sockets - either both LoROM or both HiROM. You cannot mix the two mapping types between EPROMs. You can however use one 27C322 in ROM1 and a 27C160 in ROM2 for EX-mode games, or 27C160 in ROM1 as well if making a multicart.

#### LoROM/HiROM

These are all 3-segment pads. They only need to be configured on the back if you are making a game that contains SRAM.

#### Single/Multi

The pads on the bottom right of the back of the board are mandatory for every game. Solder the middle pad to the top for single game configuration, or to the bottom for multicart configuration. The pads on the top middle of the back of the board only need to be configured if your cartridge uses SRAM.

#### SRAM Size

The set of pads at the top left underneath the SRAM chip configure the size of the SRAM that the SNES will see. All pads must be configured if you are using SRAM, and each set of 2 should be soldered in the same direction. The example picture below shows a game configured for 256 Kbit of SRAM. **It is important to note these numbers represent the SRAM in BITS, not BYTES. To figure out the BYTES of SRAM, take the numbers here and divide by 8.**



Note: If you want to set the RAM size to zero, but still have a RAM chip installed, then simply unsolder the right-most HIROM/LOROM solder pads on the backside of the board.



### Multicart Configuration

If you are setting you cartridge up for a multicart, you must bend out pin 2 (AS6C1008) or pin 1 (AS6C62256) on the SRAM chip and solder it to the outside hole.



## Estimating Battery Life

To accurately estimate the battery life, measure the voltage across R1 using a multimeter in DC mV mode, touching the probes to the two test point pads on either side of R1. You should read something around 1 mV or less. If you are severely higher than 10 mV, like in the 100's of mV, then you have a problem on your board.

Once you have a suitable voltage, find the milliamp-hour rating of your selected battery (preferrably from a datasheet). For example, a Renata CR2032 battery is rated for 225 mAh.

Now to estimate battery life, take the voltage measurement in mV and the battery rating in mAh, and plug it into this equation: 

Time (years) = Resistance of R1 (ohms) * Battery capacity (mAh) / Voltage (mV) / 8760

The factor of 8760 is for converting years to hours (24 hours in a day, 365 days in a year). The resistance of R1 is 1000 ohms. So for an example, if you measured 1 mV on R1 and are using a Renata CR2032, you would get 1000 * 225 / 1 / 8760 = **25.7 years.**

## Troubleshooting

<a href="https://github.com/MouseBiteLabs/Super-Nintendo-Cartridges/wiki/Troubleshooting-Tips">Please check out the wiki pages for troubleshooting tips.</a>

## Bill of Materials (BOM)

The component groups required for the build you want to make are detailed above.

### Mouser Shopping Cart

The following cart has *the maximum amount* of parts you would potentially need on a single board (essentially, a multicart), plus a few extras of the passive components due to price breaks. Importantly, though, this does not include the UV EPROM chips (27C160 and 27C322) because those are only available as old stock from places like AliExpress and/or eBay.

https://www.mouser.com/ProjectManager/ProjectDetail.aspx?AccessID=686eaad9eb

### Group A - 4 MB ROM, No RAM

| Reference | Value/Part Number | Package | Description | Source |
| --- | --- | --- | --- | --- |
| C1 | 22u | Radial 2.5mm spacing | Aluminum Electrolytic Capacitor | [https://mou.sr/4lzfiK1](https://mou.sr/4lzfiK1) |
| C2 | 0.1u | Radial 2.5mm spacing | Ceramic Capacitor | [https://mou.sr/481ILov](https://mou.sr/481ILov) |
| C3 | 0.1u | Radial 2.5mm spacing | Ceramic Capacitor | [https://mou.sr/481ILov](https://mou.sr/481ILov) |
| C6 | 0.1u | Radial 2.5mm spacing | Ceramic Capacitor | [https://mou.sr/481ILov](https://mou.sr/481ILov) |
| C7 | 0.1u | Radial 2.5mm spacing | Ceramic Capacitor | [https://mou.sr/481ILov](https://mou.sr/481ILov) |
| C9 | 0.1u | Radial 2.5mm spacing | Ceramic Capacitor | [https://mou.sr/481ILov](https://mou.sr/481ILov) |
| U2A | PIC12F629 | DIP-8 | PIC Microcontroller | [https://mou.sr/3XuEZzO](https://mou.sr/3XuEZzO) |
| U2B | PIC12F629 | SOIC-8 | PIC Microcontroller | [https://mou.sr/4dSUh90](https://mou.sr/4dSUh90) |
| U3 | 27C322, 27C160 | DIP-42 | UV EPROM | AliExpress, eBay |
| U6 | 74HCT257 | DIP-16 | Multiplexer | [https://mou.sr/3EvChVI](https://mou.sr/3EvChVI) |
| U7 | 74HCT257 | DIP-16 | Multiplexer | [https://mou.sr/3EvChVI](https://mou.sr/3EvChVI) |
| U9 | 74HCT139 | DIP-16 | Decoder | [https://mou.sr/441VXuJ](https://mou.sr/441VXuJ) |

### Group B - adds 32 KB of RAM

| Reference | Value/Part Number | Package | Description | Source |
| --- | --- | --- | --- | --- |
| B1 | CR2032 | CR2032 | Coin Cell Battery | [https://mou.sr/3Wj2m0G](https://mou.sr/3Wj2m0G) |
| CB | 22u | Radial 2.5mm spacing | Aluminum Electrolytic Capacitor | [https://mou.sr/4lzfiK1](https://mou.sr/4lzfiK1) |
| C5 | 0.1u | Radial 2.5mm spacing | Ceramic Capacitor | [https://mou.sr/481ILov](https://mou.sr/481ILov) |
| C8 | 0.1u | Radial 2.5mm spacing | Ceramic Capacitor | [https://mou.sr/481ILov](https://mou.sr/481ILov) |
| D1 | BAT85 | DO-35-2 | Schottky Diode | [https://mou.sr/49GVT4m](https://mou.sr/49GVT4m) |
| D2 | BAT85 | DO-35-2 | Schottky Diode | [https://mou.sr/49GVT4m](https://mou.sr/49GVT4m) |
| D3 | BAT85 | DO-35-2 | Schottky Diode | [https://mou.sr/49GVT4m](https://mou.sr/49GVT4m) |
| Q1 | 2N3904 | TO-92-3 / SOT-23-3 | NPN BJT | THT: [https://mou.sr/3HlkU91](https://mou.sr/3HlkU91), SMT: [https://mou.sr/3C8piaZ](https://mou.sr/3C8piaZ) |
| R1 | 1k | Axial | Resistor | [https://mou.sr/4hYkrZr](https://mou.sr/4hYkrZr) |
| R2 | 100k | Axial | Resistor | [https://mou.sr/3Ib4SgO](https://mou.sr/3Ib4SgO) |
| R3 | 10k | Axial | Resistor | [https://mou.sr/42AN0WU](https://mou.sr/42AN0WU) |
| R4 | 1k | Axial | Resistor | [https://mou.sr/4hYkrZr](https://mou.sr/4hYkrZr) |
| R5 | 10k | Axial | Resistor | [https://mou.sr/42AN0WU](https://mou.sr/42AN0WU) |
| U5 | AS6C62256 | DIP-28 | SRAM | [https://mou.sr/3HlZ0mh](https://mou.sr/3HlZ0mh) |
| U8 | 74HCT139 | DIP-16 | Decoder | [https://mou.sr/441VXuJ](https://mou.sr/441VXuJ) |

### Group B (Optional) - adds 128 KB of RAM (instead of 32 KB)

Replace U5 in Group B above with the part detailed here, and add the other three components. **I personally recommend sticking to the AS6C62256 SRAM chip unless you absolutely need more RAM space.**

| Reference | Value/Part Number | Package | Description | Source |
| --- | --- | --- | --- | --- |
| Q2 | 2N3904 | TO-92-3 | NPN BJT | [https://mou.sr/3HlkU91](https://mou.sr/3HlkU91) |
| R6 | 100k | Axial | Resistor | [https://mou.sr/3Ib4SgO](https://mou.sr/3Ib4SgO) |
| R7 | 10k | Axial | Resistor | [https://mou.sr/42AN0WU](https://mou.sr/42AN0WU) |
| U5 | AS6C1008 | DIP-32  | SRAM | [https://mou.sr/3hNkGxg](https://mou.sr/3hNkGxg) |

### Group C - Adds 4 MB ROM for ExLoROM/ExHiROM or multicarts

| Reference | Value/Part Number | Package | Description | Source |
| --- | --- | --- | --- | --- |
| C4 | 0.1u | Radial 2.5mm spacing | Ceramic Capacitor | [https://mou.sr/481ILov](https://mou.sr/481ILov) |
| U4 | 27C322, 27C160 | DIP-42 | UV EPROM | AliExpress, eBay |

### Group D - Enables multicart mode

| Reference | Value/Part Number | Package | Description | Source |
| --- | --- | --- | --- | --- |
| C10 | 0.1u | Radial 2.5mm spacing | Ceramic Capacitor | [https://mou.sr/481ILov](https://mou.sr/481ILov) |
| U10 | 74HCT74 | DIP-14 | Flip-flop | [https://mou.sr/3YEiVo8](https://mou.sr/3YEiVo8) |

## Revision History

### v1.0 - Re-release

- Release of the KiCad-ported version of my original SNES Advanced cart design
- Removed the "SRAM Enable" pads and made the SRAM always enabled
- HOTFIX: changed QR code, added open source hardware logo

## Acknowledgements

- Continual thanks to all in the nesdev community for their resources, design tips, and support throughout the past half-decade. This design was one of my original ones that was improved through their help and feedback when I was first starting out.

## License

<br />This work is licensed under a <a rel="license" href="http://creativecommons.org/licenses/by-sa/4.0/">Creative Commons Attribution-ShareAlike 4.0 International License</a>. You are able to copy and redistribute the material in any medium or format, as well as remix, transform, or build upon the material for any purpose (even commercial) - but you **must** give appropriate credit, provide a link to the license, and indicate if any changes were made.

©MouseBiteLabs 2025

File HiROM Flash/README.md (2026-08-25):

# Super Nintendo Advanced Flash Cartridge - HiROM (SHVC-8XH8D-01A)

# Order at your own risk -- v1.2 is untested, but likely works (v1.1 tests are complete)

This is a new and improved Super Nintendo cartridge circuit board design that is capable of being flashed via the <a href="https://github.com/sanni/cartreader">Open Source Cart Reader (OSCR) by sanni</a>. Alternatively, you can also flash the ROM chips before soldering them to the board through the use of a programmer like the <a href="https://xgecu.myshopify.com/products/xgecu-new-t48-tl866-3gprogrammer-v12-01-support-28000-ics-for-spi-nor-nand-flash-emmc-bga153-162-169-100-221-tsop-sop-plcc">T48 programmer</a> with the <a href="https://xgecu.myshopify.com/products/100-original-xgecu-adp_f48_ex-1-tsop48-special-adapter-for-nor-flash-only-use-on-t48-tl866-3g-programmer">TSOP48 adapter</a>. This cartridge is made entirely from **brand new off the shelf components.** No donors are required, and you don't need to rely on AliExpress or eBay for parts!

This is the **HiROM-only variant** of the <a href="https://github.com/MouseBiteLabs/Super-Nintendo-Cartridges">Advanced Flash cartridge</a>.



This cartridge is capable of any standard cartridge with the HiROM or ExHiROM mapping **but not those with co-processors, such as SA-1 or SuperFX.** You can backup games onto it with the following settings:
- Can be programmed to operate as a multicart, changing games by pressing the SNES reset button (this includes the ability to make two games of the same memory map, or one of each)
- Up to 8 MB of ROM space for a single game or 4 MB of ROM space for two games
- Up to 128 KB of RAM space for a single game or two separate banks of 32 KB RAM space for two games
- All these settings can be changed via DIP switch for easy on-the-fly modifications without soldering

All gerbers and source files can be found in this repo, as this project is fully open source. Please read all instructions before attempting the project.

## Important Things Before You Start

1) <a href="https://github.com/MouseBiteLabs/Super-Nintendo-Cartridges/wiki">Please review the wiki for more information about using the circuit boards, instructions for how to program them, and example builds.</a>
2) When soldering parts on, it's a good idea to put kapton tape or otherwise cover the bottom cartridge edge. You do not want to get solder on the cartridge contacts.
3) I am not responsible for any damage you do to your self or your property. Attempt this project at your own risk.
4) I do not guarantee design compatibility. You may encounter issues with certain games. There is also a chance I have made an error in the design or the BOM - if this is the case, I will do everything I can to address the problem as quickly as possible.
5) If you are using this board to make games other than for personal use, you must have permission from the originator to use and distribute any ROM images or other related material. You are responsible for making sure you adhere to any license requirements.

DO NOT use my circuit boards for profiting from stolen work - this especially includes homebrew content, ROM hacks, and using fan-made labels without permission from the originator. **Support ALL original creators!**

## Board Characteristics and Order Information

The zipped folder contains all the gerber files for this board. The following options **must** be chosen when ordering boards for yourself.

- Thickness: 1.2mm
- Surface Finish: ENIG
- Gold Fingers: Yes, 30° chamfer

You can use the zipped folder at any board fabricator you like. You may also buy the board from PCBWay using this link (disclosure: I receive 10% of the sale value to go towards future PCB orders of my own):

<a href="https://www.pcbway.com/project/shareproject/Super_Nintendo_Advanced_Flash_Cartridge_HiROM_9ef7e81f.html">PCB from PCBWay</a>

### Purchase from My Website

You can purchase this circuit board at my website, [https://mousebitelabs.store](https://mousebitelabs.store). Click the following image to be directed to the specific item listing:

<a href="https://mousebitelabs.store/products/super-nintendo-cartridge-circuit-board-advanced-flash">PCB from MouseBiteLabs</a>

### Purchase from Etsy

I also offer the board on Etsy, if you would rather purchase through there - click the banner to be redirected.

<a href="https://mousebitelabs.etsy.com/listing/1799456140">PCB from Etsy</a> 

### Purchase from insideGadgets

And finally, insideGadgets sells these boards fully populated!



## Required Equipment

- You will need basic tools, like a soldering iron, hot plate, and/or hot air rework station.
- You need a way to program the ROM chip(s).
  - This can be done with the <a href="https://github.com/sanni/cartreader">OSCR</a> to load the game and save data onto the catridge, after the cartridge is assembled.
  - Another option is to use insideGadgets' <a href="https://shop.insidegadgets.com/product/snesxflasher/">SNES programmer</a> made specifically for my cartridges. <a href="https://shop.insidegadgets.com/product/snes-advanced-flash-cartridge/">You can even purchase assembled boards from them!</a>
  - Alternatively, the <a href="https://xgecu.myshopify.com/products/xgecu-new-t48-tl866-3gprogrammer-v12-01-support-28000-ics-for-spi-nor-nand-flash-emmc-bga153-162-169-100-221-tsop-sop-plcc">T48 programmer</a> with the <a href="https://xgecu.myshopify.com/products/100-original-xgecu-adp_f48_ex-1-tsop48-special-adapter-for-nor-flash-only-use-on-t48-tl866-3g-programmer">TSOP48 adapter</a> can program the ROM chip(s). The downside to this is that if you screw up the programming, you'll have to desolder the chips and program them again.
- This cartridge uses the PIC12F629 with the <a href="https://sd2snes.de/blog/cool-stuff/supercic">SuperCIC code</a> to fake out the lockout chip. You will need a way to program these PIC chips. I use the T48 to do so, but you can also use something like the <a href="https://www.microchip.com/en-us/development-tool/pg164130">PICkit 3.</a> Note that if you have region modded your SNES, you won't need the lockout chips in the cartridges.

## How to Program

<a href="https://github.com/MouseBiteLabs/Super-Nintendo-Cartridges/wiki/Preparing-the-ROM">Please check out the wiki pages on how to prepare the ROM and program the cartridge.</a>

## Board Configurations

You *do not* need every single part on this board to make a game. The game you want to make is mainly dependent on the ROM size and the RAM size. Depending on your needs, you only need to solder on certain components, which you can find below in the BOM section.

- **Every board needs Group A components.** You can make HiROM games that have no RAM and are up to 4 MB large with this configuration. (If your game is only 2 MB, you do not need to include U9 and C9)
- If you need RAM space, **add Group B components.** This will add 32 KB of RAM space. (Multicarts will need the AS6C1008 chip for the RAM)
- If your game is larger than 4 MB, it will use the ExHiROM memory mapping. **Add Group C components for this.**
- For multicarts, you can make a board with two games on it up to 4 MB each. You will need Group C components, **as well as Group D components.** (If one of the two games you want to program is only 2 MB, you do not need to include U9 and C9 for Game 1, and/or U12 and C12 for Game 2.)
- Finally, if you *really* need the extra RAM space for the odd game that uses 128 KB of RAM, solder **Group E components**.

## Switches

For SW2 through SW6, you can either use the DIP switch as indicated in the BOM below (in the "Optional" sections), or you can jumper the pads underneath the switch to turn the switch "ON". In this example, positions 1 and 2 are "ON"; 3 and 4 are "OFF":



### Switch 2 - SRAM Size

This sets the RAM size for the game, assuming you have the RAM chip installed. The maximum addressable space for single cartridges is 128 KB (necessitates SW6 if you need more than 32 KB), and for multicarts it's 32 KB per game. You *will* need the 128 KB chip (AS6C1008) for multicarts (but not SW6). Some games will care that you have the correct RAM size, or else they will activate piracy protection, so you should try to match the settings your game calls for. Note that DIP positions 1/2, and 3/4 should be changed together simultaneously:

- For 2 KB of RAM, set all switches OFF.
- For 8 KB of RAM, set positions 1 and 2 ON, and 3 and 4 OFF.
- For 32 KB of RAM, set all positions ON.

*Note: If you have a v1.0 board, please read the section below, as the instructions are slightly different to set the RAM size correctly.*

### Switch 6 - SRAM Size (for single games with RAM larger than 32 KB)

SW6 is pretty self-explanatory, and only usable for non-multicarts. It's only required if you want to switch between games with more than 32 KB of RAM and ones that don't. The number of games that use RAM larger than 32 KB is pretty small so you probably won't need this part.

### Switch 3 - Ex Mode

Switch this ON for the ExHiROM mapping, or OFF for regular HiROM. (The ExHiROM mode on this board includes both the "true" ExHiROM mapping as well as HiROM games that just have more than 4 MB of ROM space.)

### Switch 4 and 5 - Multicart Configurations

These two sets of switches control the multicart features on the board. Here is how to use the switches to program the two games:

- Put SW4A (MULTICART) to "YES"
- Set SW4B (MULTI MODE) to "PRG" (for programming)
- Program the first game by putting SW5 in "GAME 1" position; program the second by putting SW5 in "GAME 2" position
- After both games are programmed, set SW4B to "PLAY"

Note that if you put SW4A to "NO", you will keep the game in a single-game mode, and the game that boots up will be determined by the position of SW5.

## Fix for v1.0

There's a minor issue with v1.0 of the board. **This does not affect versions after v1.0.** 

For setting the SRAM size using SW2, you must do the following:

- For 2 KB of RAM, set all switches OFF.
- For 8 KB of RAM, set positions 1 and 2 ON, and 3 and 4 OFF. **REMOVE R8 AND R9 FROM THE BOARD.**
- For 32 KB of RAM, set all positions ON. **REMOVE R8, R9, R10, AND R11 FROM THE BOARD.**

SW6 cannot be used on this board, so games are restricted to 32 KB of RAM maximum.

If you *do not* remove the resistors as defined above, your save battery life will be severely impacted.

### Multicarts for v1.0

You *cannot* make multicarts on v1.0.

## Fix for v1.1

You only need to do this if you are planning to use multicart mode. All you have to do is solder a wire from the top of R5 to the top of SW5.



## Estimating Battery Life

To accurately estimate the battery life, you must first solder the battery in, and then either program your game in the OSCR or power it on in a Super Nintendo.

After that, measure the voltage across R1 using a multimeter in DC mV mode, touching the probes to the two test point pads on either side of R1 (or, the + and - pads on the back of the board below my smiling face). You should read something around 10 mV or less. If you are severely higher than 10 mV, like in the 100's of mV, then you have a problem on your board.



Once you have a suitable voltage, find the milliamp-hour rating of your selected battery (preferrably from a datasheet). For example, a Renata CR2032 battery is rated for 225 mAh.

Now to estimate battery life, take the voltage measurement in mV and the battery rating in mAh, and plug it into this equation: 

Time (years) = Resistance of R1 (ohms) * Battery capacity (mAh) / Voltage (mV) / 8760

The factor of 8760 is for converting years to hours (24 hours in a day, 365 days in a year). The resistance of R1 is 10000 ohms. So for an example, if you measured 10 mV on R1 and are using a Renata CR2032, you would get 10000 * 225 / 10 / 8760 = **25.7 years.**

## Troubleshooting

<a href="https://github.com/MouseBiteLabs/Super-Nintendo-Cartridges/wiki/Troubleshooting-Tips">Please check out the wiki pages for troubleshooting tips.</a>

## Bill of Materials (BOM)

The component groups required for the build you want to make are detailed above. Note that the "optional" groups mostly only contain the switches, as you can manually set the switch position with a 0-ohm resistor (or, lack of a resistor). Remember, shorting the pads means the switch is ON, and keeping the pads depopulated means the switch is OFF.

### Mouser Shopping Cart

The following cart has *the maximum amount* of parts you would potentially need on a single board (essentially, a multicart), plus a few extras of the passive components due to price breaks. This also includes **four M29F160 chips and both the AS6C62256 and AS6C1008.** You can remove the chips you don't need from the shopping cart before ordering, according to the component group assignments below.

https://www.mouser.com/ProjectManager/ProjectDetail.aspx?AccessID=b7de252bab

### Group A - 4 MB ROM, No RAM

Note: If your game is only 2 MB, you do not need U9 and C9.

| Reference | Value/Part Number | Package | Description | Source |
| --- | --- | --- | --- | --- |
| C1 | 0.1u | 0603 | Capacitor (MLCC) | [https://mou.sr/3ENc15O](https://mou.sr/3ENc15O) |
| C7 | 0.1u | 0603 | Capacitor (MLCC) | [https://mou.sr/3ENc15O](https://mou.sr/3ENc15O) |
| C8 | 0.1u | 0603 | Capacitor (MLCC) | [https://mou.sr/3ENc15O](https://mou.sr/3ENc15O) |
| C9 | 0.1u | 0603 | Capacitor (MLCC) | [https://mou.sr/3ENc15O](https://mou.sr/3ENc15O) |
| CC | 22u | 1206 | Capacitor (MLCC) | [https://mou.sr/4e4zShm](https://mou.sr/4e4zShm) |
| R4 | 100k | 0603 | Resistor | [https://mou.sr/49bgMnu](https://mou.sr/49bgMnu) |
| R5 | 100k | 0603 | Resistor | [https://mou.sr/49bgMnu](https://mou.sr/49bgMnu) |
| U1 | PIC12F629 | DIP-8, SOIC-8 | Lockout Chip | [https://mou.sr/3XuEZzO](https://mou.sr/3XuEZzO) |
| U7 | 74HCT139 | TSSOP-16 | Decoder | [https://mou.sr/4eqzppn](https://mou.sr/4eqzppn) |
| U8 | M29F160 | TSOP-48 | Flash EEPROM | [https://mou.sr/3MNWQ0b](https://mou.sr/3MNWQ0b) |
| U9 | M29F160 | TSOP-48 | Flash EEPROM | [https://mou.sr/3MNWQ0b](https://mou.sr/3MNWQ0b) |

### Group A (Optional) - Programming header

Note: J1 is a space that allows you to program the PIC using the standard ISP pinout while the chip is on-board. It is not a required component. If you wish to use it, you will need to pick out a component yourself to use here, as there are different ways to go about using it.

| Reference | Value/Part Number | Package | Description | Source |
| --- | --- | --- | --- | --- |
| J1 | \-- | 2x3 pins, 2.54mm spacing | Header (see note)  | N/A |

### Group B - adds 32 KB of RAM

Note 1: If you are making a multicart, you must use the AS6C1008 for U10. 

Note 2: If you are using an AS6C62256, you can omit R14 and R15.

| Reference | Value/Part Number | Package | Description | Source |
| --- | --- | --- | --- | --- |
| B1 | CR2032 | CR2032 | Coin Cell Battery  | [https://mou.sr/3Wj2m0G](https://mou.sr/3Wj2m0G) |
| C5 | 0.1u | 0603 | Capacitor (MLCC) | [https://mou.sr/3ENc15O](https://mou.sr/3ENc15O) |
| C10 | 0.1u | 0603 | Capacitor (MLCC) | [https://mou.sr/3ENc15O](https://mou.sr/3ENc15O) |
| C11 | 0.1u | 0603 | Capacitor (MLCC) | [https://mou.sr/3ENc15O](https://mou.sr/3ENc15O) |
| CB | 22u | 1206 | Capacitor (MLCC) | [https://mou.sr/4e4zShm](https://mou.sr/4e4zShm) |
| Q1 | 2N7002 | SOT-23 | N-channel MOSFET | [https://mou.sr/3rgfh6J](https://mou.sr/3rgfh6J) |
| R1 | 10k | 0603 | Resistor | [https://mou.sr/3riR7IH](https://mou.sr/3riR7IH) |
| R6 | 130k | 0603 | Resistor | [https://mou.sr/3MjXliy](https://mou.sr/3MjXliy) |
| R7 | 49.9k | 0603 | Resistor | [https://mou.sr/3BBcDgp](https://mou.sr/3BBcDgp) |
| R8 | 100k | 0603 | Resistor | [https://mou.sr/49bgMnu](https://mou.sr/49bgMnu) |
| R9 | 100k | 0603 | Resistor | [https://mou.sr/49bgMnu](https://mou.sr/49bgMnu) |
| R10 | 100k | 0603 | Resistor | [https://mou.sr/49bgMnu](https://mou.sr/49bgMnu) |
| R11 | 100k | 0603 | Resistor | [https://mou.sr/49bgMnu](https://mou.sr/49bgMnu) |
| R14 | 100k | 0603 | Resistor | [https://mou.sr/49bgMnu](https://mou.sr/49bgMnu) |
| R15 | 100k | 0603 | Resistor | [https://mou.sr/49bgMnu](https://mou.sr/49bgMnu) |
| U5 | 74HCT139 | TSSOP-16 | Decoder | [https://mou.sr/4eqzppn](https://mou.sr/4eqzppn) |
| U10 | AS6C62256, AS6C1008 | SOP-28, SOP-32 | SRAM | [https://mou.sr/3ZxG6jd](https://mou.sr/3ZxG6jd) |
| U11 | TPS3613 | MSOP-10 | Battery Management | [https://mou.sr/45Ir2kh](https://mou.sr/45Ir2kh) |

### Group B (Optional) - RAM size switch/jumpers

| Reference | Value/Part Number | Package | Description | Source |
| --- | --- | --- | --- | --- |
| RS2A | 0 ohm | 0603 | Resistor (Jumper)  | [https://mou.sr/4e1ABQg](https://mou.sr/4e1ABQg) |
| RS2B | 0 ohm | 0603 | Resistor (Jumper)  | [https://mou.sr/4e1ABQg](https://mou.sr/4e1ABQg) |
| RS2C | 0 ohm | 0603 | Resistor (Jumper)  | [https://mou.sr/4e1ABQg](https://mou.sr/4e1ABQg) |
| RS2D | 0 ohm | 0603 | Resistor (Jumper)  | [https://mou.sr/4e1ABQg](https://mou.sr/4e1ABQg) |
| SW2 | DS04-254-2-04BK-SMT | 4-position DIP | DIP Switch (4-pos) | [https://mou.sr/3MPsI4o](https://mou.sr/3MPsI4o) |

### Group C - Adds 4 MB ROM for ExHiROM

Note: If your Ex-mode game is 6 MB large, you don't need U13 and C13.

| Reference | Value/Part Number | Package | Description | Source |
| --- | --- | --- | --- | --- |
| C12 | 0.1u | 0603 | Capacitor (MLCC) | [https://mou.sr/3ENc15O](https://mou.sr/3ENc15O) |
| C13 | 0.1u | 0603 | Capacitor (MLCC) | [https://mou.sr/3ENc15O](https://mou.sr/3ENc15O) |
| U12 | M29F160 | TSOP-48 | Flash EEPROM | [https://mou.sr/3MNWQ0b](https://mou.sr/3MNWQ0b) |
| U13 | M29F160 | TSOP-48 | Flash EEPROM | [https://mou.sr/3MNWQ0b](https://mou.sr/3MNWQ0b) |

### Group C (Optional) - Ex Mode switch/jumper

| Reference | Value/Part Number | Package | Description | Source |
| --- | --- | --- | --- | --- |
| RS3 | 0 ohm | 0603 | Resistor (Jumper)  | [https://mou.sr/4e1ABQg](https://mou.sr/4e1ABQg) |
| SW3 | DS04-254-2-01BK-SMT | 1-position DIP | DIP Switch (1-pos) | [https://mou.sr/3MK4Lvz](https://mou.sr/3MK4Lvz) |

### Group D - Enables multicart mode

Note: If your game(s) are 2 MB, you do not need U9 and C9 (for Game 1) and/or U12 and C12 (for Game 2).

| Reference | Value/Part Number | Package | Description | Source |
| --- | --- | --- | --- | --- |
| C14 | 0.1u | 0603 | Capacitor (MLCC) | [https://mou.sr/3ENc15O](https://mou.sr/3ENc15O) |
| R13 | 10k | 0603 | Resistor | [https://mou.sr/3riR7IH](https://mou.sr/3riR7IH) |
| U14 | 74HCT74 | TSSOP-14  | Flip-Flop | [https://mou.sr/4eroZpu](https://mou.sr/4eroZpu) |

### Group D (Optional) - Multicart mode switches/jumpers

| Reference | Value/Part Number | Package | Description | Source |
| --- | --- | --- | --- | --- |
| RS4A | 0 ohm | 0603 | Resistor (Jumper)  | [https://mou.sr/4e1ABQg](https://mou.sr/4e1ABQg) |
| RS4B | 0 ohm | 0603 | Resistor (Jumper)  | [https://mou.sr/4e1ABQg](https://mou.sr/4e1ABQg) |
| RS5 | 0 ohm | 0603 | Resistor (Jumper)  | [https://mou.sr/4e1ABQg](https://mou.sr/4e1ABQg) |
| SW4 | DS04-254-2-02BK-SMT | 2-position DIP | DIP Switch (2-pos) | [https://mou.sr/3B7BqZr](https://mou.sr/3B7BqZr) |
| SW5 | DS04-254-2-01BK-SMT | 1-position DIP | DIP Switch (1-pos) | [https://mou.sr/3MK4Lvz](https://mou.sr/3MK4Lvz) |

### Group E (Optional) - Increases RAM to 128 KB

| Reference | Value/Part Number | Package | Description | Source |
| --- | --- | --- | --- | --- |
| RS6A | 0 ohm | 0603 | Resistor (Jumper)  | [https://mou.sr/4e1ABQg](https://mou.sr/4e1ABQg) |
| RS6B | 0 ohm | 0603 | Resistor (Jumper)  | [https://mou.sr/4e1ABQg](https://mou.sr/4e1ABQg) |
| SW6 | DS04-254-2-02BK-SMT | 2-position DIP | DIP Switch (2-pos) | [https://mou.sr/3B7BqZr](https://mou.sr/3B7BqZr) |

## Revision History

### v1.2 - Release

- Fix board number on top right corner
- Fix multicart net to ROM selection
- Remove "1" from single DIP switches for clarity

### v1.1 - Beta

- Fixed C9 and C12 positions on PCB
- Added resistors under all switches as alternative
- Changed R8 through R11 and R14 to pull-down resistors
- Added Q1 to ensure RAM start-up at correct time
- Simplified multicart circuit to reduce battery current draw, lower the BOM count/cost and simplify the design
- Change board outline to differentiate board from other similar boards

### v1.0 - Alpha

- Prototype version

## Acknowledgements

- Extremely huge thanks to sanni for firstly creating the OSCR, and secondly for adding programming support for the cartridges.
- Continual thanks to all in the nesdev community for their resources, design tips, and support throughout the past half-decade.

## License

<br />This work is licensed under a <a rel="license" href="http://creativecommons.org/licenses/by-sa/4.0/">Creative Commons Attribution-ShareAlike 4.0 International License</a>. You are able to copy and redistribute the material in any medium or format, as well as remix, transform, or build upon the material for any purpose (even commercial) - but you **must** give appropriate credit, provide a link to the license, and indicate if any changes were made.

©MouseBiteLabs 2024

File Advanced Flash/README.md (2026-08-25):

# Super Nintendo Advanced Flash Cartridge (SNES-8XJ4D-01A)

# Order at your own risk -- v1.2 is technically untested, but previous version is fully tested

This is a new and improved Super Nintendo cartridge circuit board design that is capable of being flashed via the <a href="https://github.com/sanni/cartreader">Open Source Cart Reader (OSCR) by sanni</a>. Alternatively, you can also flash the ROM chips before soldering them to the board through the use of a programmer like the <a href="https://xgecu.myshopify.com/products/xgecu-new-t48-tl866-3gprogrammer-v12-01-support-28000-ics-for-spi-nor-nand-flash-emmc-bga153-162-169-100-221-tsop-sop-plcc">T48 programmer</a> with the <a href="https://xgecu.myshopify.com/products/100-original-xgecu-adp_f48_ex-1-tsop48-special-adapter-for-nor-flash-only-use-on-t48-tl866-3g-programmer">TSOP48 adapter</a>. This cartridge is made entirely from **brand new off the shelf components.** No donors are required, and you don't need to rely on AliExpress or eBay for parts!



This cartridge covers over 95% of the entire SNES library, capable of any standard cartridge **but not those with co-processors, such as SA-1 or SuperFX.** You can backup games onto it with the following settings:
- All memory maps supported: LoROM, HiROM, ExLoROM, and ExHiROM
- Can be programmed to operate as a multicart, changing games by pressing the SNES reset button (this includes the ability to make two games of the same memory map, or one of each)
- Up to 8 MB of ROM space for a single game or 4 MB of ROM space for two games
- Up to 32 KB of RAM space for a single game or two separate banks of 32 KB RAM space for two games
- All these settings can be changed via DIP switch for easy on-the-fly modifications without soldering

All gerbers and source files can be found in this repo, as this project is fully open source. Please read all instructions before attempting the project.

## Important Things Before You Start

1) <a href="https://github.com/MouseBiteLabs/Super-Nintendo-Cartridges/wiki">Please review the wiki for more information about using the circuit boards, instructions for how to program them, and example builds.</a>
2) When soldering parts on, it's a good idea to put kapton tape or otherwise cover the bottom cartridge edge. You do not want to get solder on the cartridge contacts.
3) I am not responsible for any damage you do to your self or your property. Attempt this project at your own risk.
4) I do not guarantee design compatibility. You may encounter issues with certain games. There is also a chance I have made an error in the design or the BOM - if this is the case, I will do everything I can to address the problem as quickly as possible.
5) If you are using this board to make games other than for personal use, you must have permission from the originator to use and distribute any ROM images or other related material. You are responsible for making sure you adhere to any license requirements.

DO NOT use my circuit boards for profiting from stolen work - this especially includes homebrew content, ROM hacks, and using fan-made labels without permission from the originator. **Support ALL original creators!**

## Board Characteristics and Order Information

The zipped folder contains all the gerber files for this board. The following options **must** be chosen when ordering boards for yourself.

- Thickness: 1.2mm
- Surface Finish: ENIG
- Gold Fingers: Yes, 30° chamfer

You can use the zipped folder at any board fabricator you like. You may also buy the board from PCBWay using this link (disclosure: I receive 10% of the sale value to go towards future PCB orders of my own):

<a href="https://www.pcbway.com/project/shareproject/Super_Nintendo_Advanced_Flash_Cartridge_7757ec59.html">PCB from PCBWay</a>

### Purchase from My Website

You can purchase this circuit board at my website, [https://mousebitelabs.store](https://mousebitelabs.store). Click the following image to be directed to the specific item listing:

<a href="https://mousebitelabs.store/products/super-nintendo-cartridge-circuit-board-advanced-flash">PCB from MouseBiteLabs</a>

### Purchase from Etsy

I also offer the board on Etsy, if you would rather purchase through there - click the banner to be redirected.

<a href="https://mousebitelabs.etsy.com/listing/1799456140">PCB from Etsy</a> 

### Purchase from insideGadgets

And finally, insideGadgets sells these boards fully populated!



## Required Equipment

- You will need basic tools, like a soldering iron, hot plate, and/or hot air rework station.
- You need a way to program the ROM chip(s).
  - This can be done with the <a href="https://github.com/sanni/cartreader">OSCR</a> to load the game and save data onto the catridge, after the cartridge is assembled.
  - Another option is to use insideGadgets' <a href="https://shop.insidegadgets.com/product/snesxflasher/">SNES programmer</a> made specifically for my cartridges. <a href="https://shop.insidegadgets.com/product/snes-advanced-flash-cartridge/">You can even purchase assembled boards from them!</a>
  - Alternatively, the <a href="https://xgecu.myshopify.com/products/xgecu-new-t48-tl866-3gprogrammer-v12-01-support-28000-ics-for-spi-nor-nand-flash-emmc-bga153-162-169-100-221-tsop-sop-plcc">T48 programmer</a> with the <a href="https://xgecu.myshopify.com/products/100-original-xgecu-adp_f48_ex-1-tsop48-special-adapter-for-nor-flash-only-use-on-t48-tl866-3g-programmer">TSOP48 adapter</a> can program the ROM chip(s). The downside to this is that if you screw up the programming, you'll have to desolder the chips and program them again.
- This cartridge uses the PIC12F629 with the <a href="https://sd2snes.de/blog/cool-stuff/supercic">SuperCIC code</a> to fake out the lockout chip. You will need a way to program these PIC chips. I use the T48 to do so, but you can also use something like the <a href="https://www.microchip.com/en-us/development-tool/pg164130">PICkit 3.</a> Note that if you have region modded your SNES, you won't need the lockout chips in the cartridges.

## How to Program

<a href="https://github.com/MouseBiteLabs/Super-Nintendo-Cartridges/wiki/Preparing-the-ROM">Please check out the wiki pages on how to prepare the ROM and program the cartridge.</a>

## Board Configurations

You *do not* need every single part on this board to make a game. The game you want to make is mainly dependent on the memory mapping (LoROM, HiROM, etc), the ROM size, and the RAM size. Depending on your needs, you only need to solder on certain components, which you can find below in the BOM section.

- **Every board needs Group A components.** You can make LoRom or HiROM games that have no RAM and are up to 4 MB large with this configuration. (If your game is only 2 MB, you do not need to include U9 and C9)
- If you need RAM space, **add Group B components.** This will add 32 KB of RAM space. (Multicarts will need the AS6C1008 chip for the RAM)
- If your game is larger than 4 MB, it will use the ExLoROM or ExHiROM memory mapping. **Add Group C components for this.**
- For multicarts, you can make a board with two games on it up to 4 MB each. You will need Group C components, **as well as Group D components.** (If one of the two games you want to program is only 2 MB, you do not need to include U9 and C9 for Game 1, and/or U12 and C12 for Game 2.)

## Switches

For SW1 through SW5, you can either use the DIP switch as indicated in the BOM below (in the "Optional" sections), or you can jumper the pads underneath the switch to turn the switch "ON". In this example, positions 1 and 2 are "ON"; 3 and 4 are "OFF":



### Switch 1 - Memory Mapping

This is the LoROM/HiROM switch. Turn it on to enter LoROM mode, or turn it off for HiROM mode, depending on the game you program.

### Switch 2 - SRAM Size

This sets the RAM size for the game, assuming you have the RAM chip installed. The maximum allocated RAM space *per game* on this board is only 32 KB, even if you put a 128 KB RAM chip (you will need the 128 KB chip for multicarts). Some games will care that you have the correct RAM size, or else they will activate piracy protection, so you should try to match the settings your game calls for. Note that DIP positions 1/2, and 3/4 should be changed together simultaneously:

- For 2 KB of RAM, set all switches OFF.
- For 8 KB of RAM, set positions 1 and 2 ON, and 3 and 4 OFF.
- For 32 KB of RAM, set all positions ON.

*Note: If you have a v1.1 board, please read the section below, as the instructions are slightly different to set the RAM size correctly.*

### Switch 3 - Ex Mode

Switch this ON to change the setting on SW1 to ExLoROM/ExHiROM. Switch it OFF to keep SW1 as a LoROM/HiROM switch.

### Switch 4 and 5 - Multicart Configurations

These two sets of switches control the multicart features on the board. You can make two LoROM games, two HiROM games, or one LoROM game and one HiROM game if you set the "Map Swap" switch to "YES". Here is how to use the switches to program the two games:

- Set SW4B (MULTI MODE) to "PRG" (for programming)
- Put SW4A (MAP SWAP) in the mode you want to use:
  - YES = Game 1 is LoROM, Game 2 is HiROM
  - NO = Game 1 and Game 2 are both LoROM or HiROM depending on SW1 position
  - If you are programming two of the same memory map types, put SW1 into the desired memory map mode (SW1 position does not matter if you are using the map swap feature)
- Program the first game by putting SW5 in "GAME 1" position; program the second by putting SW5 in "GAME 2" position
  - If you are going to use the map swap feature, make sure game 1 is the LoROM game and game 2 is the HiROM game!
- After both games are programmed, set SW4B to "PLAY"

Note that if you keep SW4B in "PRG" mode, the game that boots up will be determined by the position of SW5.

## Fix for v1.1

There's a minor issue with v1.1 of the board. **This does not affect versions after v1.1.** 

For setting the SRAM size using SW2, you must do the following:

- For 2 KB of RAM, set all switches OFF.
- For 8 KB of RAM, set positions 1 and 2 ON, and 3 and 4 OFF. **REMOVE R8 AND R9 FROM THE BOARD.**
- For 32 KB of RAM, set all positions ON. **REMOVE R8, R9, R10, AND R11 FROM THE BOARD.**

If you *do not* remove the resistors as defined above, your save battery life will be severely impacted. 

### Multicarts for v1.1

You *cannot* make multicarts on v1.1.

## Estimating Battery Life

To accurately estimate the battery life, you must first solder the battery in, and then either program your game in the OSCR or power it on in a Super Nintendo.

After that, measure the voltage across R1 using a multimeter in DC mV mode, touching the probes to the two test point pads on either side of R1 (or, the + and - pads on the back of the board below my smiling face). You should read something around 10 mV or less. If you are severely higher than 10 mV, like in the 100's of mV, then you have a problem on your board.



Once you have a suitable voltage, find the milliamp-hour rating of your selected battery (preferrably from a datasheet). For example, a Renata CR2032 battery is rated for 225 mAh.

Now to estimate battery life, take the voltage measurement in mV and the battery rating in mAh, and plug it into this equation: 

Time (years) = Resistance of R1 (ohms) * Battery capacity (mAh) / Voltage (mV) / 8760

The factor of 8760 is for converting years to hours (24 hours in a day, 365 days in a year). The resistance of R1 is 10000 ohms. So for an example, if you measured 10 mV on R1 and are using a Renata CR2032, you would get 10000 * 225 / 10 / 8760 = **25.7 years.**

## Troubleshooting

<a href="https://github.com/MouseBiteLabs/Super-Nintendo-Cartridges/wiki/Troubleshooting-Tips">Please check out the wiki pages for troubleshooting tips.</a>

## Bill of Materials (BOM)

The component groups required for the build you want to make are detailed above. Note that the "optional" groups mostly only contain the switches, as you can manually set the switch position with a 0-ohm resistor (or, lack of a resistor). Remember, shorting the pads means the switch is ON, and keeping the pads depopulated means the switch is OFF.

### Mouser Shopping Cart

The following cart has *the maximum amount* of parts you would potentially need on a single board (essentially, a multicart), plus a few extras of the passive components due to price breaks. This also includes **four M29F160 chips and both the AS6C62256 and AS6C1008.** You can remove the chips you don't need from the shopping cart before ordering, according to the component group assignments below.

https://www.mouser.com/ProjectManager/ProjectDetail.aspx?AccessID=1bc68cfc83

### Group A - 4 MB ROM, No RAM

Note: If your game is only 2 MB, you do not need U9 and C9.

| Reference | Value/Part Number | Package | Description | Source |
| --- | --- | --- | --- | --- |
| C1 | 0.1u | 0603 | Capacitor (MLCC) | [https://mou.sr/3ENc15O](https://mou.sr/3ENc15O) |
| C2 | 0.1u | 0603 | Capacitor (MLCC) | [https://mou.sr/3ENc15O](https://mou.sr/3ENc15O) |
| C3 | 0.1u | 0603 | Capacitor (MLCC) | [https://mou.sr/3ENc15O](https://mou.sr/3ENc15O) |
| C4 | 0.1u | 0603 | Capacitor (MLCC) | [https://mou.sr/3ENc15O](https://mou.sr/3ENc15O) |
| C7 | 0.1u | 0603 | Capacitor (MLCC) | [https://mou.sr/3ENc15O](https://mou.sr/3ENc15O) |
| C8 | 0.1u | 0603 | Capacitor (MLCC) | [https://mou.sr/3ENc15O](https://mou.sr/3ENc15O) |
| C9 | 0.1u | 0603 | Capacitor (MLCC) | [https://mou.sr/3ENc15O](https://mou.sr/3ENc15O) |
| CC | 22u | 1206 | Capacitor (MLCC) | [https://mou.sr/4e4zShm](https://mou.sr/4e4zShm) |
| R2 | 100k | 0603 | Resistor | [https://mou.sr/49bgMnu](https://mou.sr/49bgMnu) |
| R3 | 10k | 0603 | Resistor | [https://mou.sr/3riR7IH](https://mou.sr/3riR7IH) |
| R4 | 100k | 0603 | Resistor | [https://mou.sr/49bgMnu](https://mou.sr/49bgMnu) |
| R5 | 10k | 0603 | Resistor | [https://mou.sr/3riR7IH](https://mou.sr/3riR7IH) |
| U1 | PIC12F629 | DIP-8, SOIC-8 | Lockout Chip | [https://mou.sr/3XuEZzO](https://mou.sr/3XuEZzO) |
| U2 | SN74CBT3257CPWR | TSSOP-16 | Multiplexer | [https://mou.sr/3MKJwd1](https://mou.sr/3MKJwd1) |
| U3 | SN74CBT3257CPWR | TSSOP-16 | Multiplexer | [https://mou.sr/3MKJwd1](https://mou.sr/3MKJwd1) |
| U4 | SN74CBT3257CPWR | TSSOP-16 | Multiplexer | [https://mou.sr/3MKJwd1](https://mou.sr/3MKJwd1) |
| U7 | 74HCT139 | TSSOP-16 | Decoder | [https://mou.sr/4eqzppn](https://mou.sr/4eqzppn) |
| U8 | M29F160 | TSOP-48 | Flash EEPROM | [https://mou.sr/3MNWQ0b](https://mou.sr/3MNWQ0b) |
| U9 | M29F160 | TSOP-48 | Flash EEPROM | [https://mou.sr/3MNWQ0b](https://mou.sr/3MNWQ0b) |

### Group A (Optional) - Programming header, Lo/Hi switch/jumper

Note: J1 is a space that allows you to program the PIC using the standard ISP pinout while the chip is on-board. It is not a required component. If you wish to use it, you will need to pick out a component yourself to use here, as there are different ways to go about using it.

| Reference | Value/Part Number | Package | Description | Source |
| --- | --- | --- | --- | --- |
| J1 | \-- | 2x3 pins, 2.54mm spacing | Header (see note)  | N/A |
| RS1 | 0 ohm | 0603 | Resistor (Jumper)  | [https://mou.sr/4e1ABQg](https://mou.sr/4e1ABQg) |
| SW1 | DS04-254-2-01BK-SMT | 1-position DIP | DIP Switch (1-pos) | [https://mou.sr/3MK4Lvz](https://mou.sr/3MK4Lvz) |

### Group B - adds 32 KB of RAM

Note: If you are making a multicart, you must use the AS6C1008 for U10.

| Reference | Value/Part Number | Package | Description | Source |
| --- | --- | --- | --- | --- |
| B1 | CR2032 | CR2032 | Coin Cell Battery  | [https://mou.sr/3Wj2m0G](https://mou.sr/3Wj2m0G) |
| C5 | 0.1u | 0603 | Capacitor (MLCC) | [https://mou.sr/3ENc15O](https://mou.sr/3ENc15O) |
| C6 | 0.1u | 0603 | Capacitor (MLCC) | [https://mou.sr/3ENc15O](https://mou.sr/3ENc15O) |
| C10 | 0.1u | 0603 | Capacitor (MLCC) | [https://mou.sr/3ENc15O](https://mou.sr/3ENc15O) |
| C11 | 0.1u | 0603 | Capacitor (MLCC) | [https://mou.sr/3ENc15O](https://mou.sr/3ENc15O) |
| CB | 22u | 1206 | Capacitor (MLCC) | [https://mou.sr/4e4zShm](https://mou.sr/4e4zShm) |
| Q1 | 2N7002 | SOT-23 | N-channel MOSFET | [https://mou.sr/3rgfh6J](https://mou.sr/3rgfh6J) |
| R1 | 10k | 0603 | Resistor | [https://mou.sr/3riR7IH](https://mou.sr/3riR7IH) |
| R6 | 130k | 0603 | Resistor | [https://mou.sr/3MjXliy](https://mou.sr/3MjXliy) |
| R7 | 49.9k | 0603 | Resistor | [https://mou.sr/3BBcDgp](https://mou.sr/3BBcDgp) |
| R8 | 100k | 0603 | Resistor | [https://mou.sr/49bgMnu](https://mou.sr/49bgMnu) |
| R9 | 100k | 0603 | Resistor | [https://mou.sr/49bgMnu](https://mou.sr/49bgMnu) |
| R10 | 100k | 0603 | Resistor | [https://mou.sr/49bgMnu](https://mou.sr/49bgMnu) |
| R11 | 100k | 0603 | Resistor | [https://mou.sr/49bgMnu](https://mou.sr/49bgMnu) |
| U5 | 74HCT139 | TSSOP-16 | Decoder | [https://mou.sr/4eqzppn](https://mou.sr/4eqzppn) |
| U6 | 74HCT139 | TSSOP-16 | Decoder | [https://mou.sr/4eqzppn](https://mou.sr/4eqzppn) |
| U10 | AS6C62256, AS6C1008 | SOP-28, SOP-32 | SRAM | [https://mou.sr/3ZxG6jd](https://mou.sr/3ZxG6jd) |
| U11 | TPS3613 | MSOP-10 | Battery Management | [https://mou.sr/45Ir2kh](https://mou.sr/45Ir2kh) |

### Group B (Optional) - RAM size switch/jumpers

| Reference | Value/Part Number | Package | Description | Source |
| --- | --- | --- | --- | --- |
| RS2A | 0 ohm | 0603 | Resistor (Jumper)  | [https://mou.sr/4e1ABQg](https://mou.sr/4e1ABQg) |
| RS2B | 0 ohm | 0603 | Resistor (Jumper)  | [https://mou.sr/4e1ABQg](https://mou.sr/4e1ABQg) |
| RS2C | 0 ohm | 0603 | Resistor (Jumper)  | [https://mou.sr/4e1ABQg](https://mou.sr/4e1ABQg) |
| RS2D | 0 ohm | 0603 | Resistor (Jumper)  | [https://mou.sr/4e1ABQg](https://mou.sr/4e1ABQg) |
| SW2 | DS04-254-2-04BK-SMT | 4-position DIP | DIP Switch (4-pos) | [https://mou.sr/3MPsI4o](https://mou.sr/3MPsI4o) |

### Group C - Adds 4 MB ROM for ExLoROM and ExHiROM

Note: If your Ex-mode game is 6 MB large, you don't need U13 and C13.

| Reference | Value/Part Number | Package | Description | Source |
| --- | --- | --- | --- | --- |
| C12 | 0.1u | 0603 | Capacitor (MLCC) | [https://mou.sr/3ENc15O](https://mou.sr/3ENc15O) |
| C13 | 0.1u | 0603 | Capacitor (MLCC) | [https://mou.sr/3ENc15O](https://mou.sr/3ENc15O) |
| U12 | M29F160 | TSOP-48 | Flash EEPROM | [https://mou.sr/3MNWQ0b](https://mou.sr/3MNWQ0b) |
| U13 | M29F160 | TSOP-48 | Flash EEPROM | [https://mou.sr/3MNWQ0b](https://mou.sr/3MNWQ0b) |

### Group C (Optional) - Ex Mode switch/jumper

| Reference | Value/Part Number | Package | Description | Source |
| --- | --- | --- | --- | --- |
| RS3 | 0 ohm | 0603 | Resistor (Jumper)  | [https://mou.sr/4e1ABQg](https://mou.sr/4e1ABQg) |
| SW3 | DS04-254-2-01BK-SMT | 1-position DIP | DIP Switch (1-pos) | [https://mou.sr/3MK4Lvz](https://mou.sr/3MK4Lvz) |

### Group D - Enables multicart mode

Note: If your game(s) are 2 MB, you do not need U9 and C9 (for Game 1) and/or U12 and C12 (for Game 2).

| Reference | Value/Part Number | Package | Description | Source |
| --- | --- | --- | --- | --- |
| C14 | 0.1u | 0603 | Capacitor (MLCC) | [https://mou.sr/3ENc15O](https://mou.sr/3ENc15O) |
| R13 | 1k | 0603 | Resistor | [https://mou.sr/3U0EvS4](https://mou.sr/3U0EvS4) |
| U14 | 74HCT74 | TSSOP-14  | Flip-Flop | [https://mou.sr/4eroZpu](https://mou.sr/4eroZpu) |

### Group D (Optional) - Multicart mode switches/jumpers

| Reference | Value/Part Number | Package | Description | Source |
| --- | --- | --- | --- | --- |
| RS4A | 0 ohm | 0603 | Resistor (Jumper)  | [https://mou.sr/4e1ABQg](https://mou.sr/4e1ABQg) |
| RS4B | 0 ohm | 0603 | Resistor (Jumper)  | [https://mou.sr/4e1ABQg](https://mou.sr/4e1ABQg) |
| RS5 | 0 ohm | 0603 | Resistor (Jumper)  | [https://mou.sr/4e1ABQg](https://mou.sr/4e1ABQg) |
| SW4 | DS04-254-2-02BK-SMT | 2-position DIP | DIP Switch (2-pos) | [https://mou.sr/3B7BqZr](https://mou.sr/3B7BqZr) |
| SW5 | DS04-254-2-01BK-SMT | 1-position DIP | DIP Switch (1-pos) | [https://mou.sr/3MK4Lvz](https://mou.sr/3MK4Lvz) |

## Revision History

### v1.2 - Release

- Fixed C9 and C12 positions on PCB
- Added resistors under all switches as alternative
- Changed R8 through R11 to pull-down resistors
- Added Q1 to ensure RAM start-up at correct time
- Simplified multicart circuit to reduce battery current draw, lower the BOM count/cost and simplify the design
- Remove "1" from single DIP switches for clarity

### v1.1 - Beta

- Change reference designators CC1 to CC, CB1 to CB
- Make silkscreen thicker, pin 1 indicators bigger, add boxes around passives
- Round the cart edge for easier insertion, add cart edge pin numbers
- Add pin 1 indicators to switches and U1; move U2-U7 reference designators
- Change Prog/Play to more descriptive language
- Add pads for resistors instead of switches

### v1.0 - Alpha

- Prototype version

## Acknowledgements

- Extremely huge thanks to sanni for firstly creating the OSCR, and secondly for adding programming support for the cartridges.
- Continual thanks to all in the nesdev community for their resources, design tips, and support throughout the past half-decade.

## License

<br />This work is licensed under a <a rel="license" href="http://creativecommons.org/licenses/by-sa/4.0/">Creative Commons Attribution-ShareAlike 4.0 International License</a>. You are able to copy and redistribute the material in any medium or format, as well as remix, transform, or build upon the material for any purpose (even commercial) - but you **must** give appropriate credit, provide a link to the license, and indicate if any changes were made.

©MouseBiteLabs 2024

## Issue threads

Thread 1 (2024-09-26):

Voltage range for 74CBTLV3257

gnaghi, 2024-09-26:
The datasheet of the 74CBTLV3257 defines the working voltage range from 2.3 V to 3.6 V.
But the SNES outputs +5V to the cartridge bus.
Would level shifter be useful ?

MouseBiteLabs, 2024-09-26:
I specify the 5V tolerant parts in the BOM, where do you see the LV version?

https://www.mouser.com/ProductDetail/595-SN74CBT3257CPWR

Also I forgot I uploaded files last week - I've found an issue and I need to rev the board, so if you downloaded the files that were there up until just now, I would recommend waiting until the new ones are uploaded :)

MouseBiteLabs, 2024-09-26:
I have a bad habit of picking symbols without looking at the exact part numbers, and saving that part for when I'm putting together the BOM. Usually people don't check the schematic for the part numbers. But I guess I should be consistent - I'll fix this for when I upload the new version. Thanks!

Closed 2024-09-26.

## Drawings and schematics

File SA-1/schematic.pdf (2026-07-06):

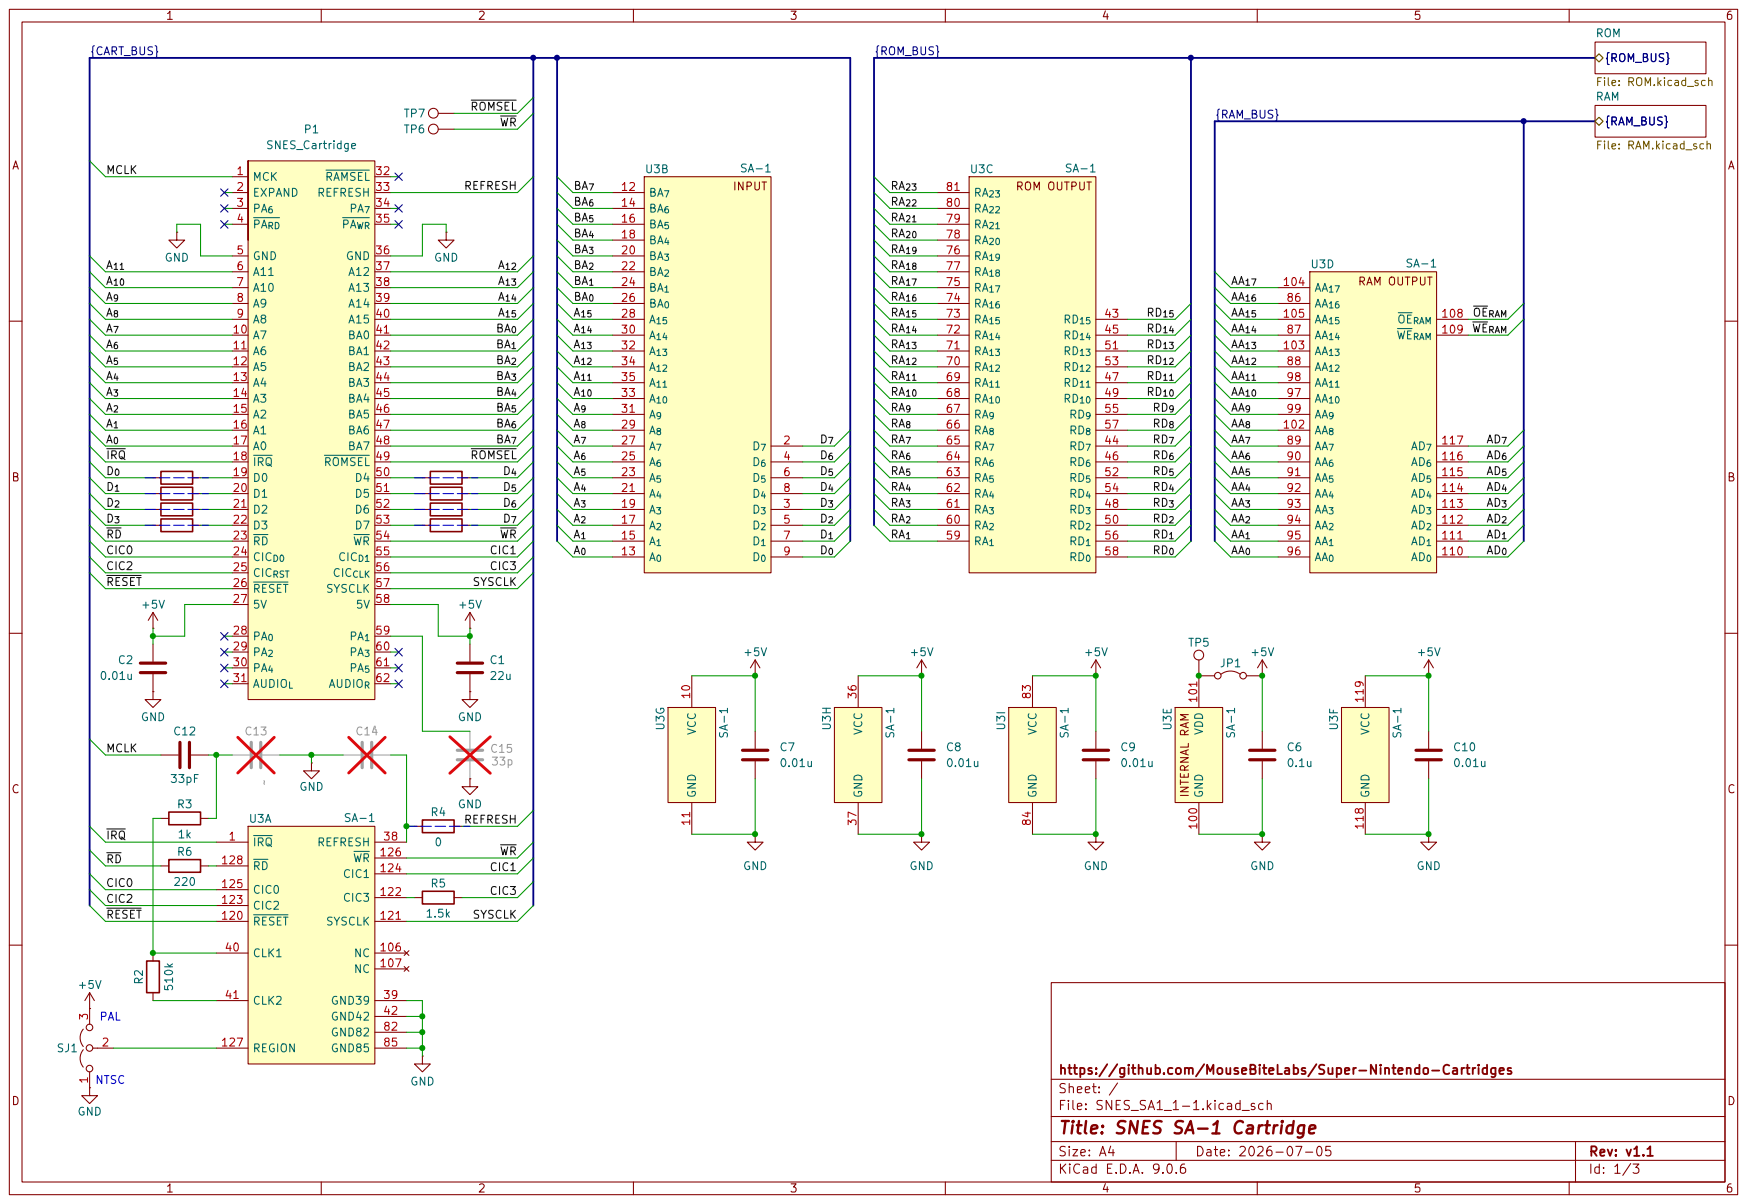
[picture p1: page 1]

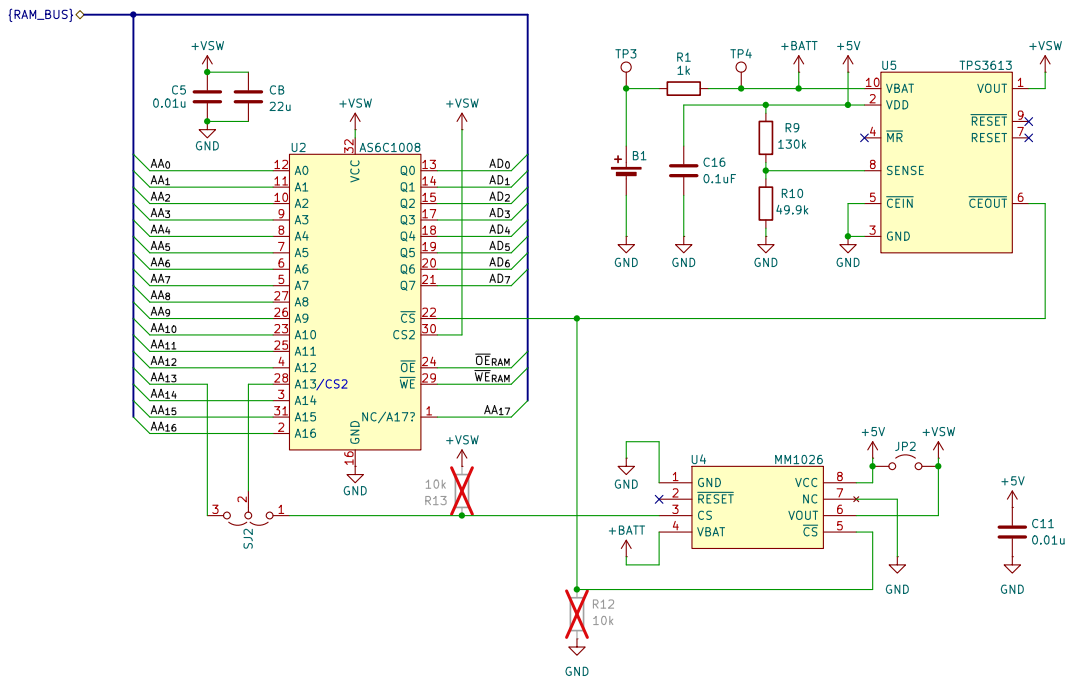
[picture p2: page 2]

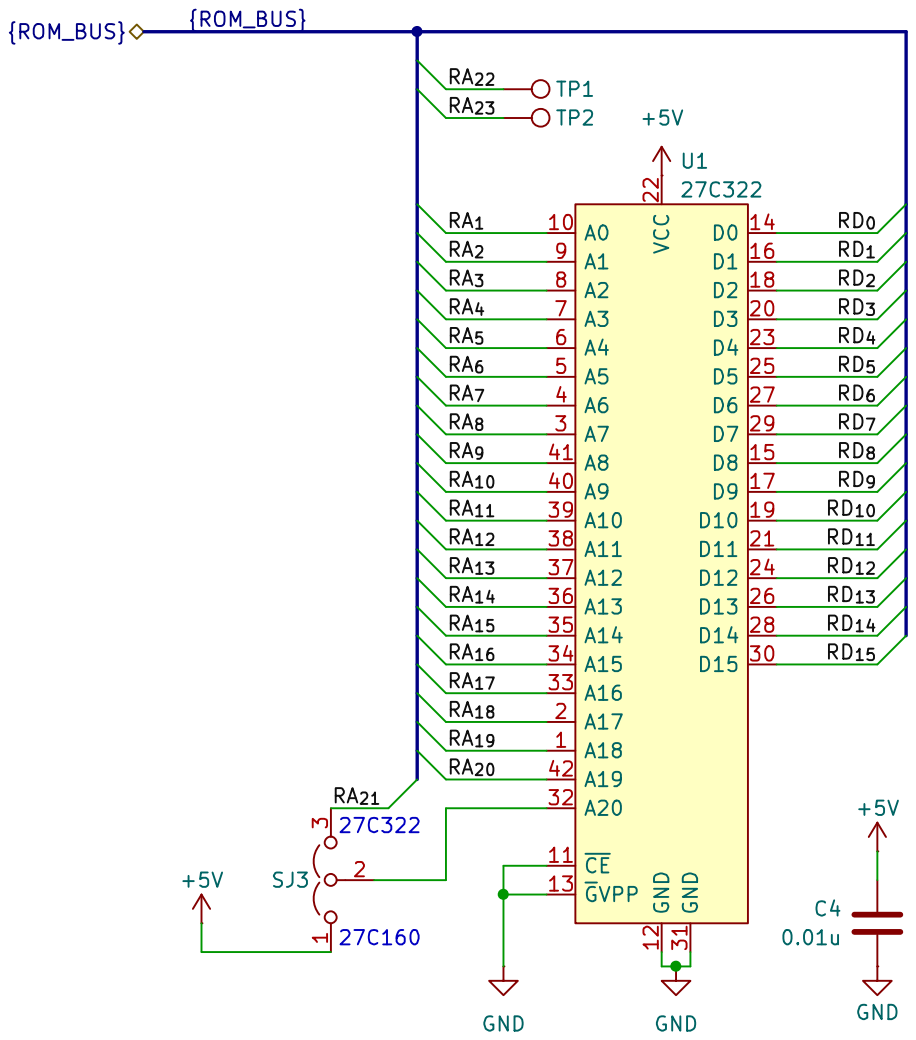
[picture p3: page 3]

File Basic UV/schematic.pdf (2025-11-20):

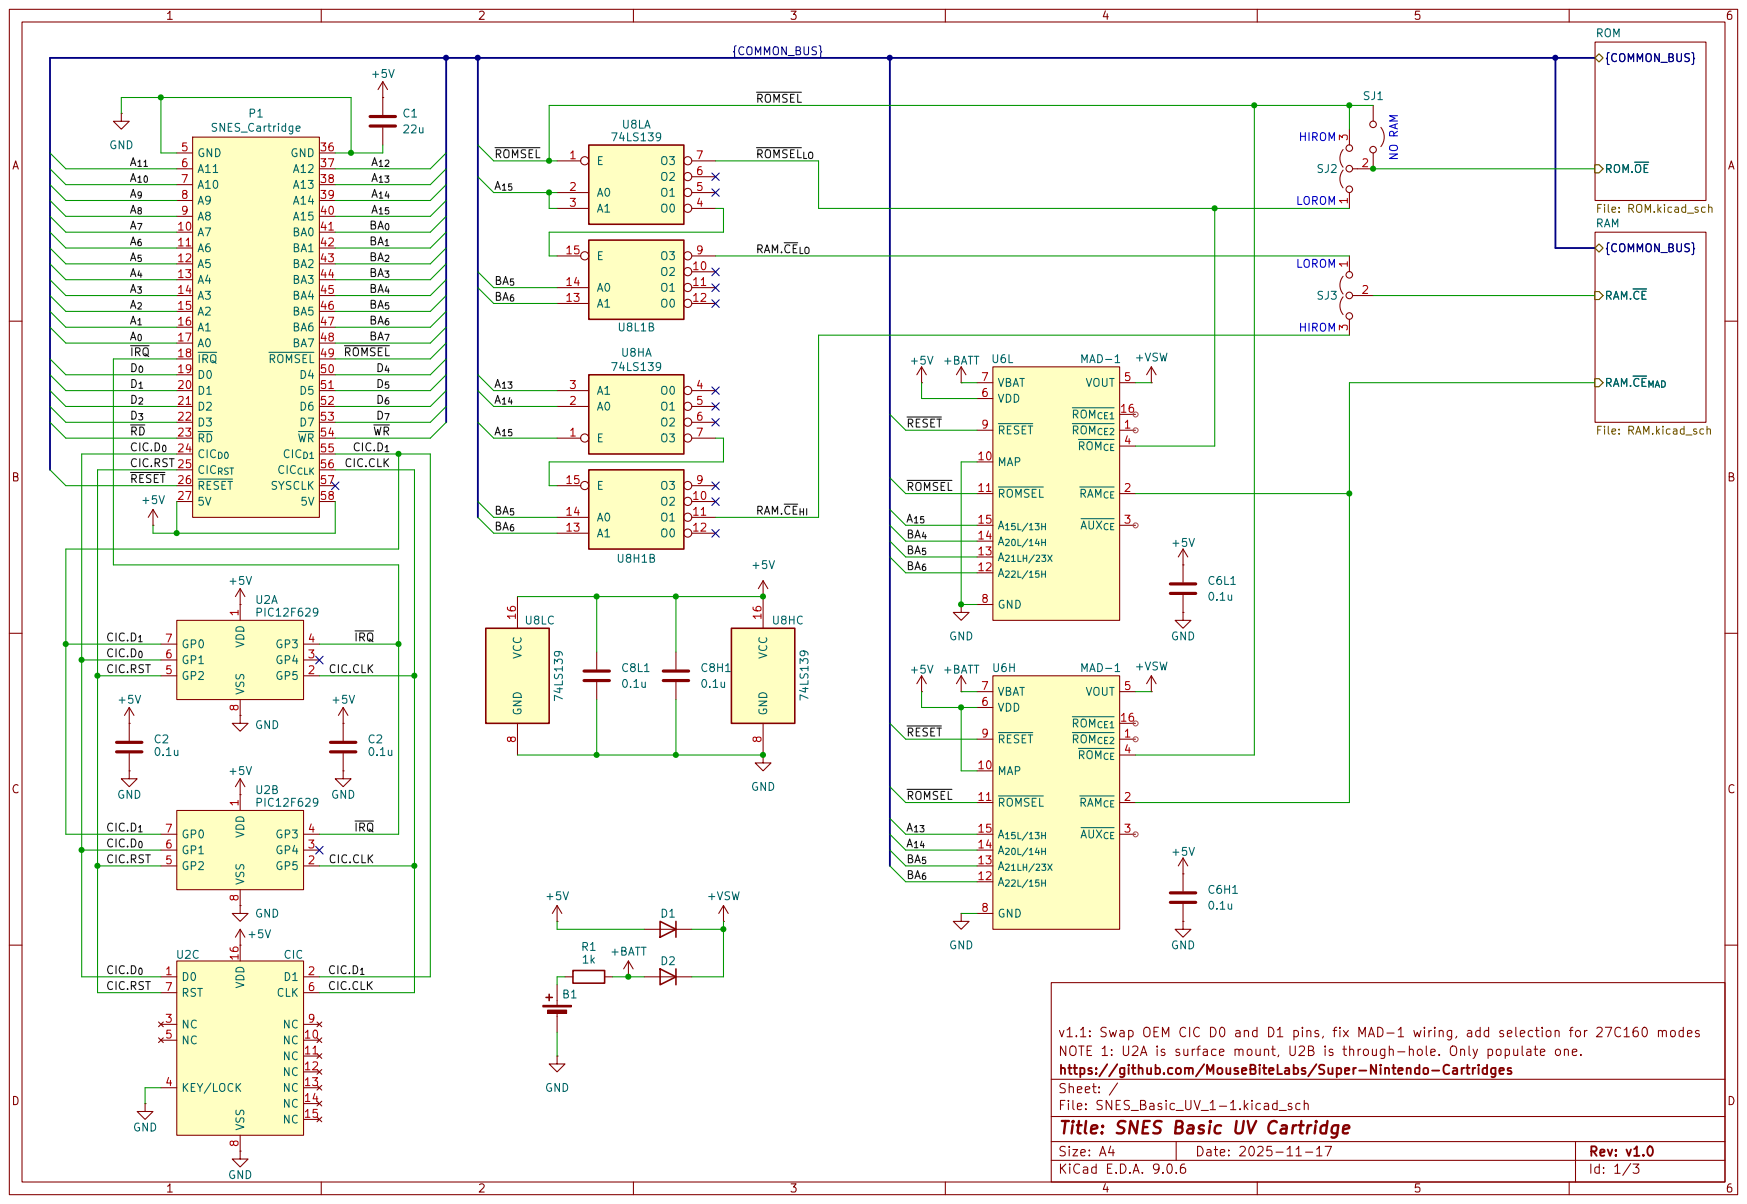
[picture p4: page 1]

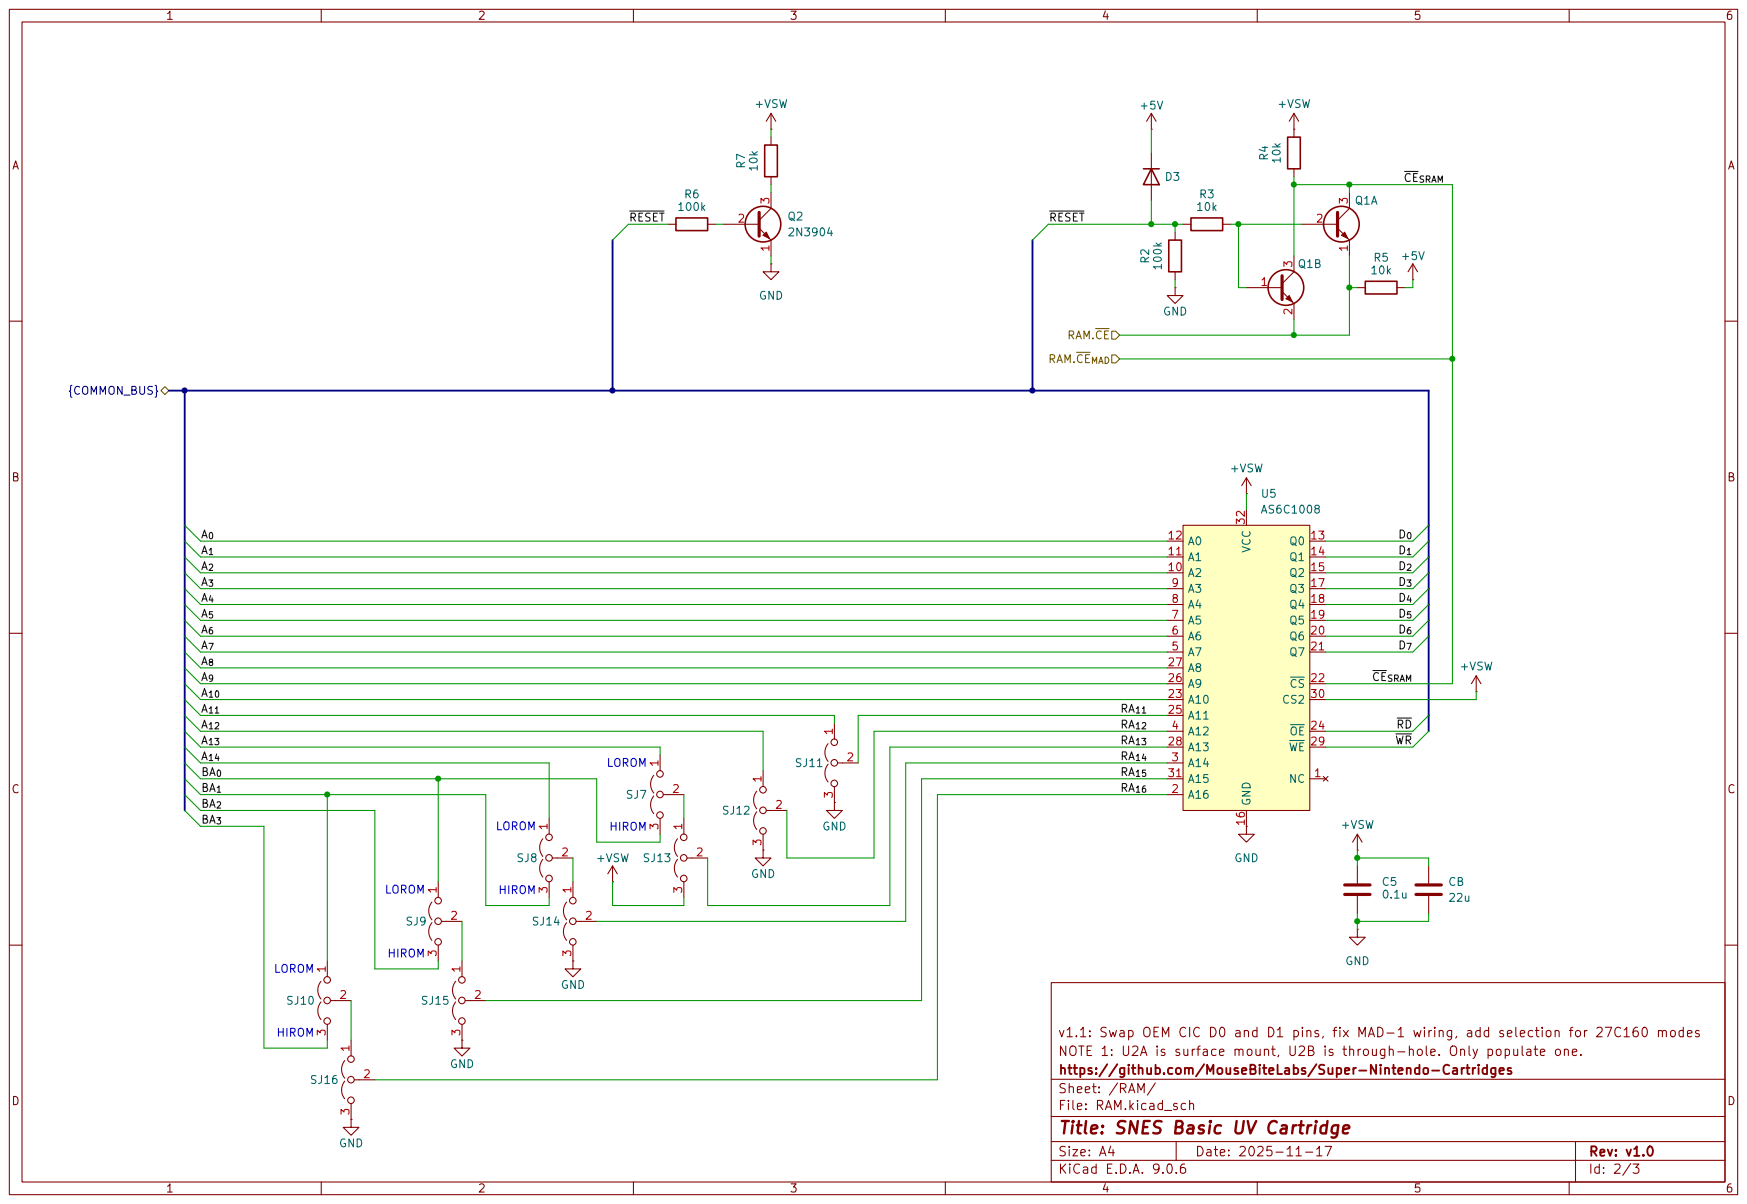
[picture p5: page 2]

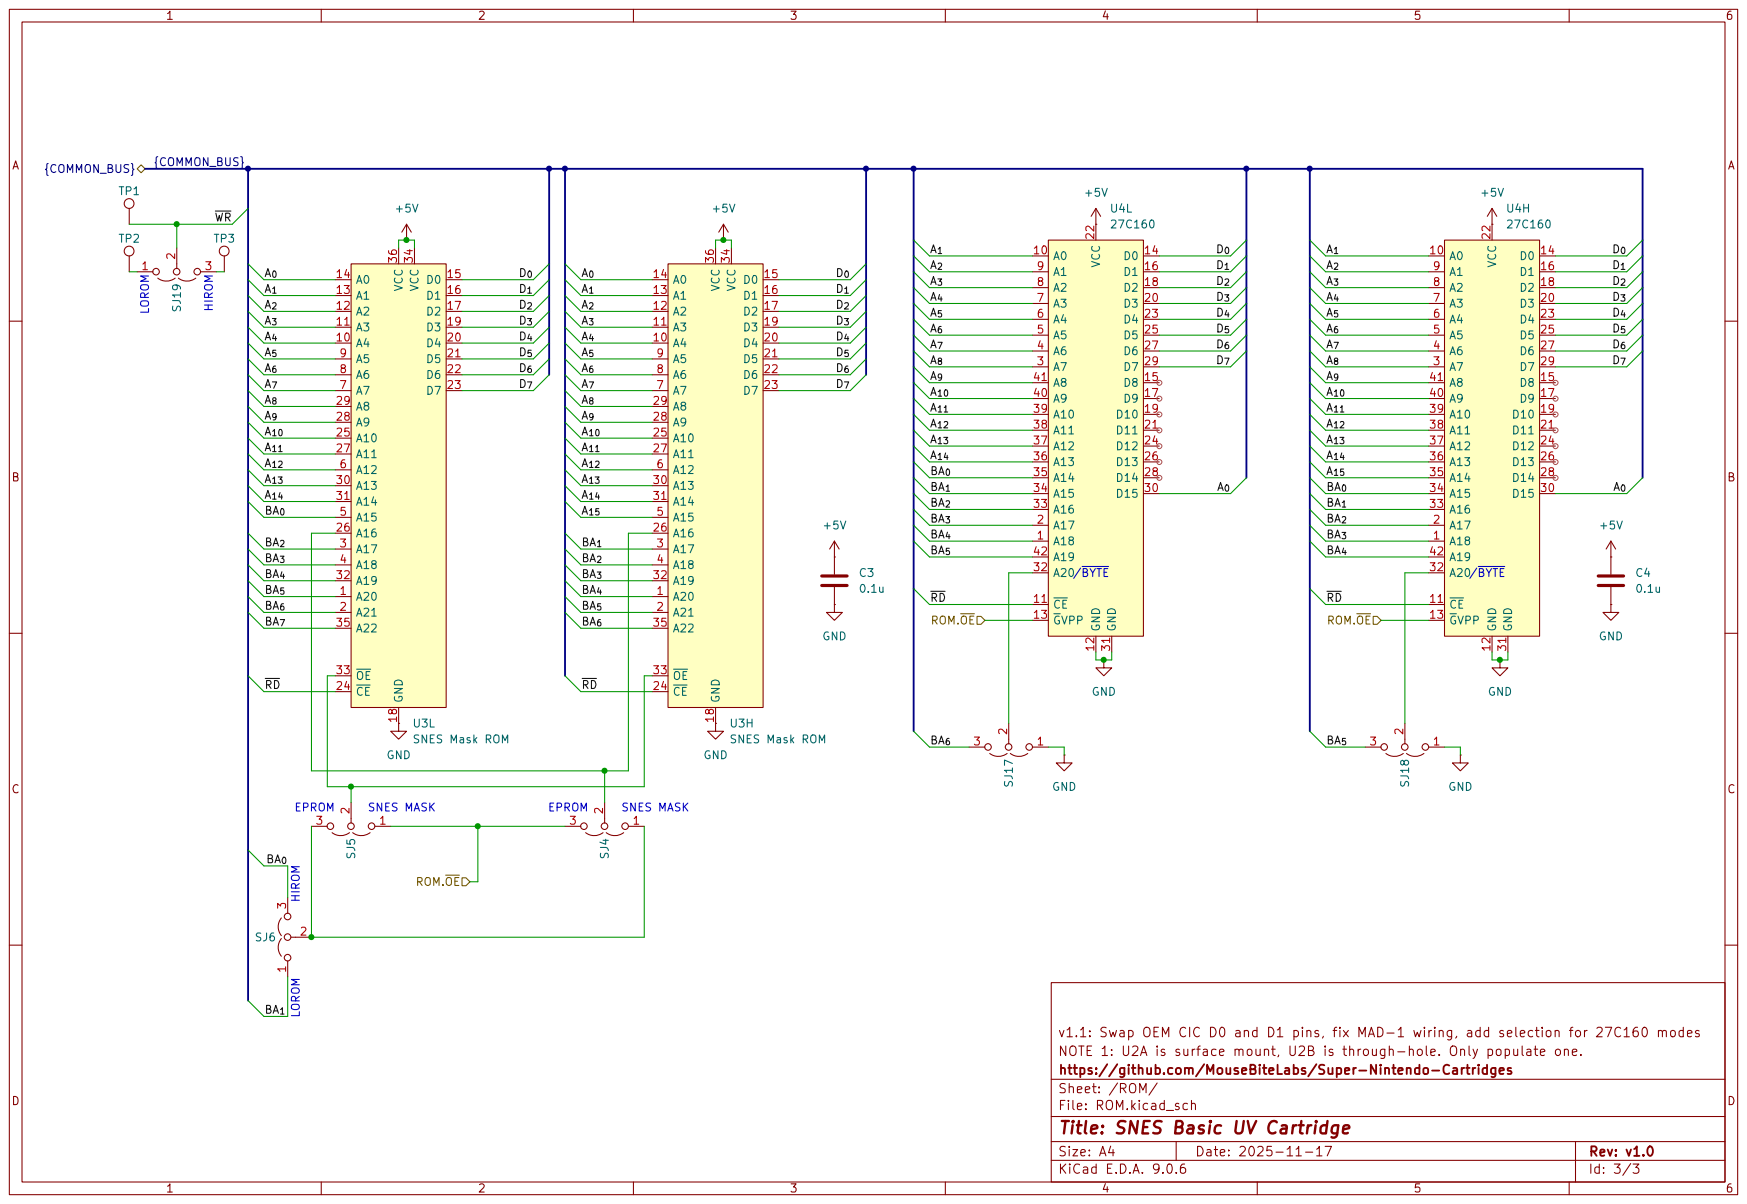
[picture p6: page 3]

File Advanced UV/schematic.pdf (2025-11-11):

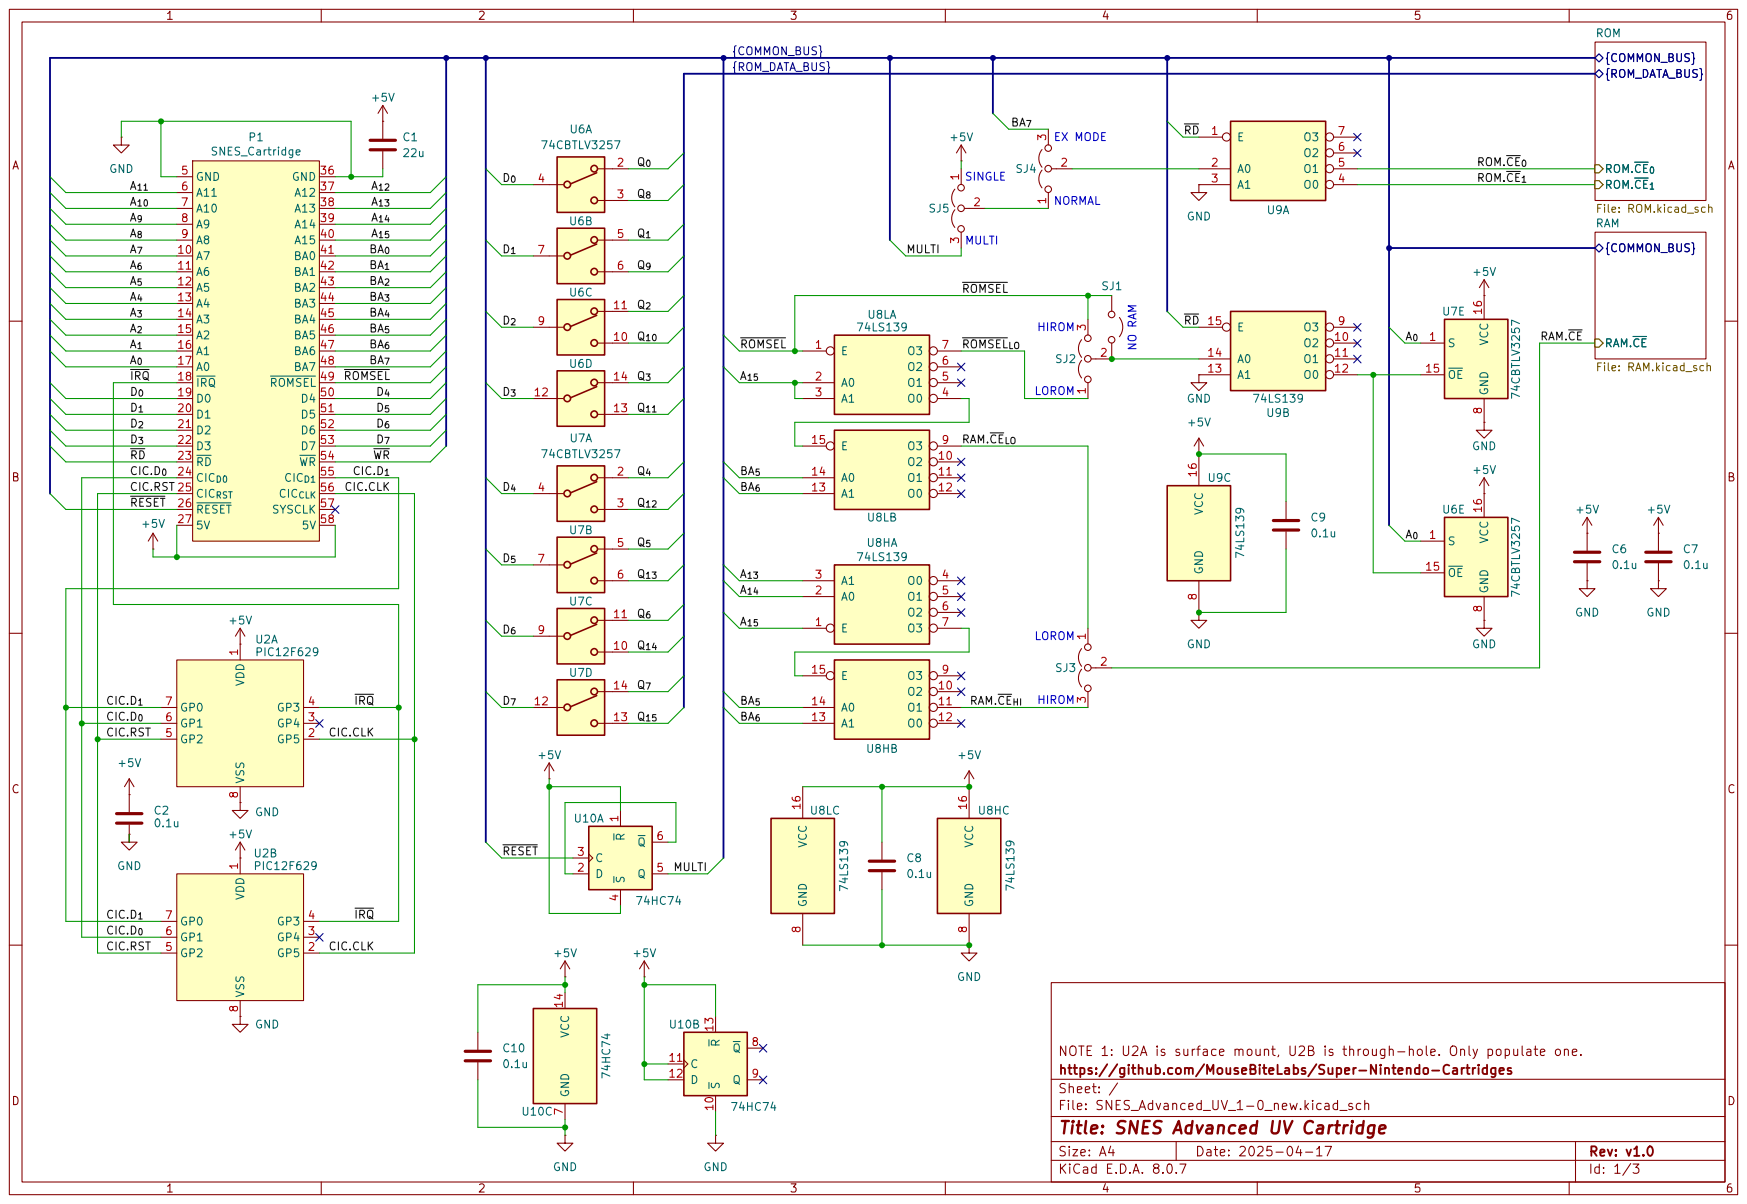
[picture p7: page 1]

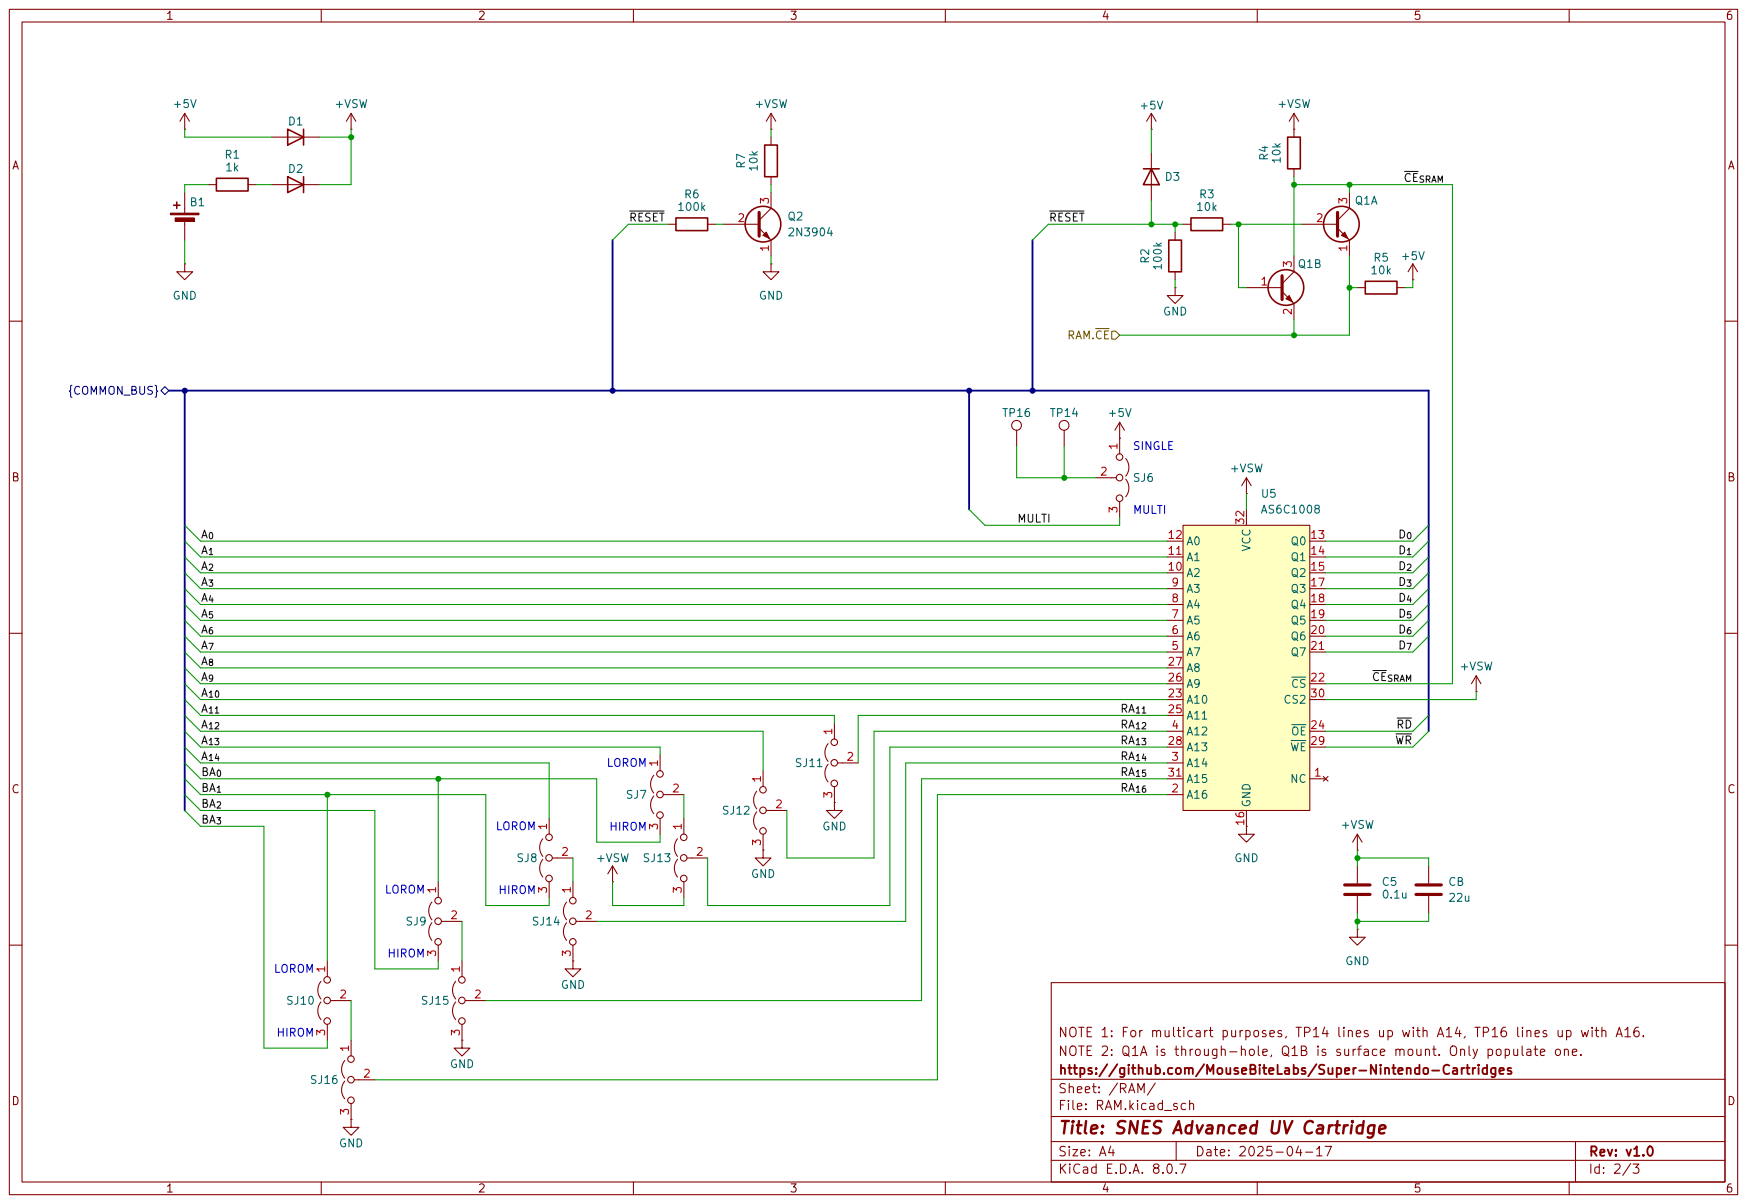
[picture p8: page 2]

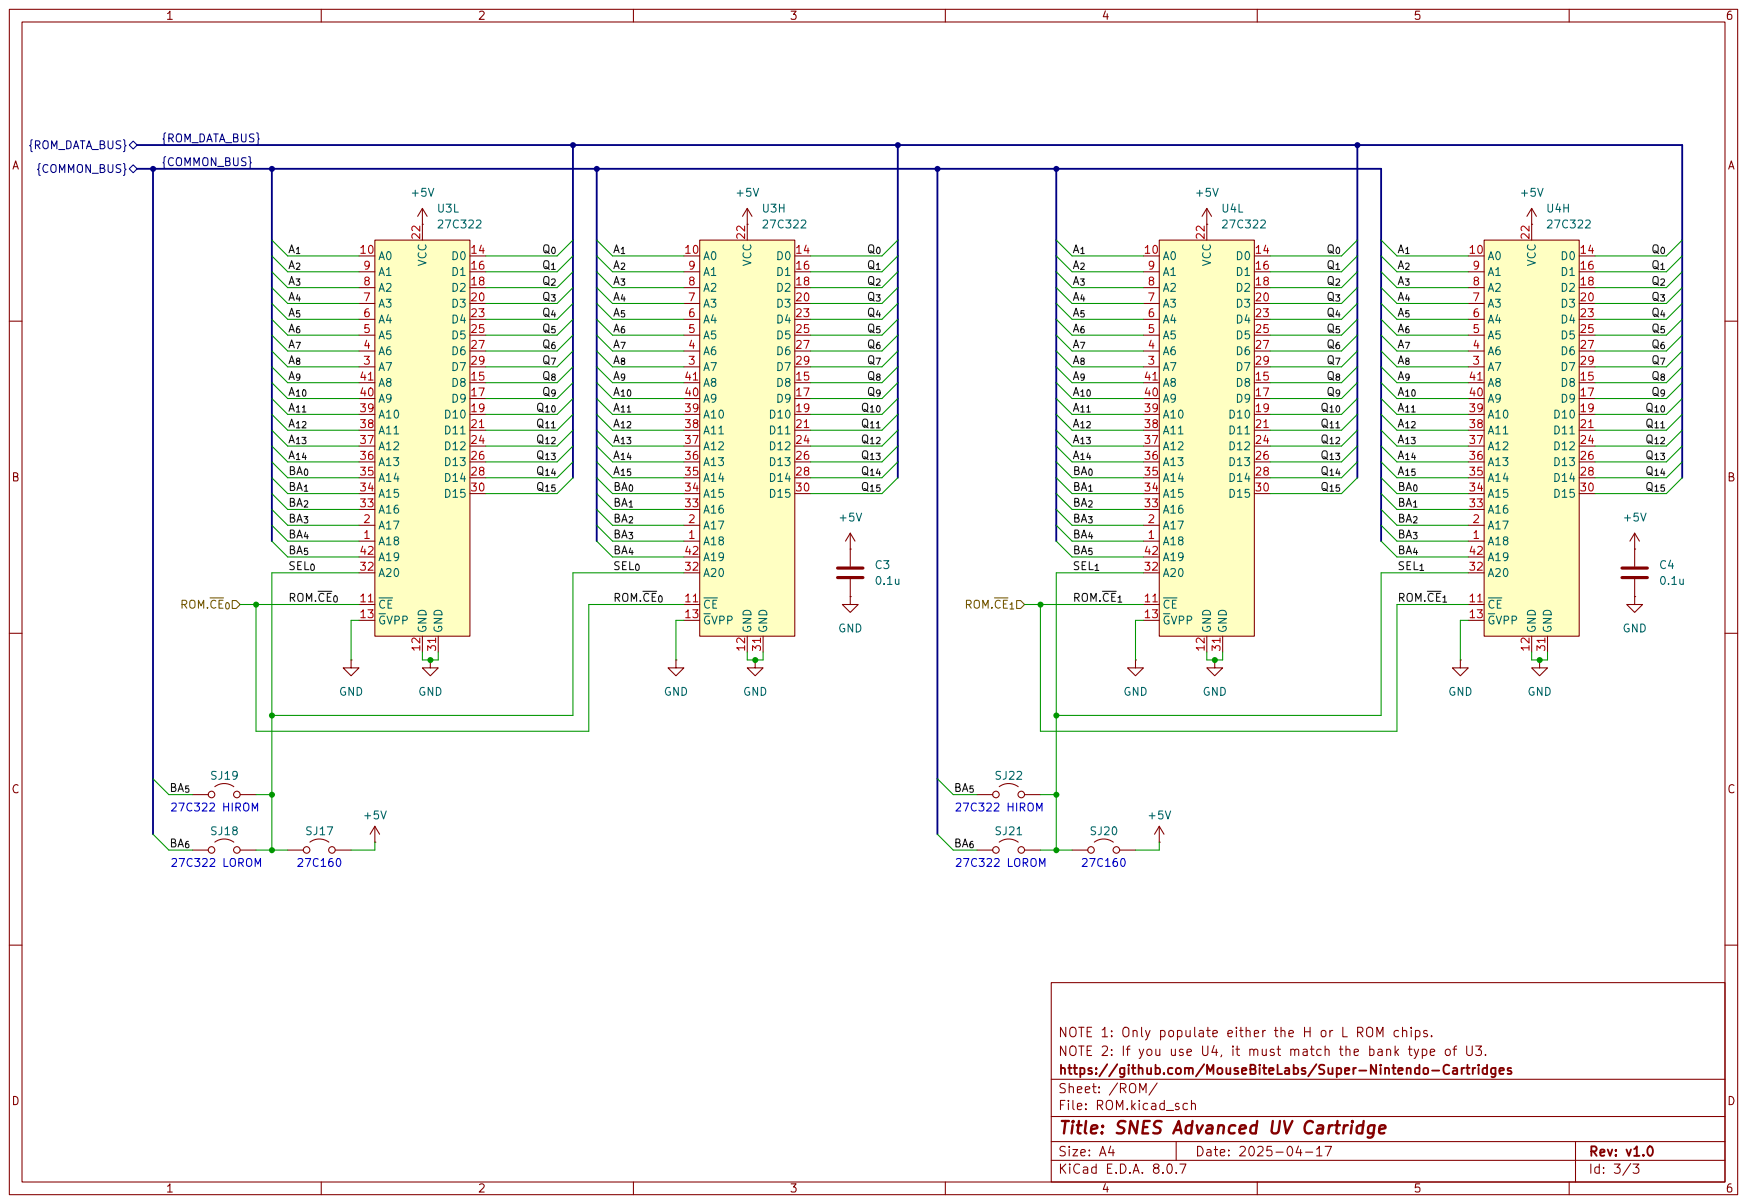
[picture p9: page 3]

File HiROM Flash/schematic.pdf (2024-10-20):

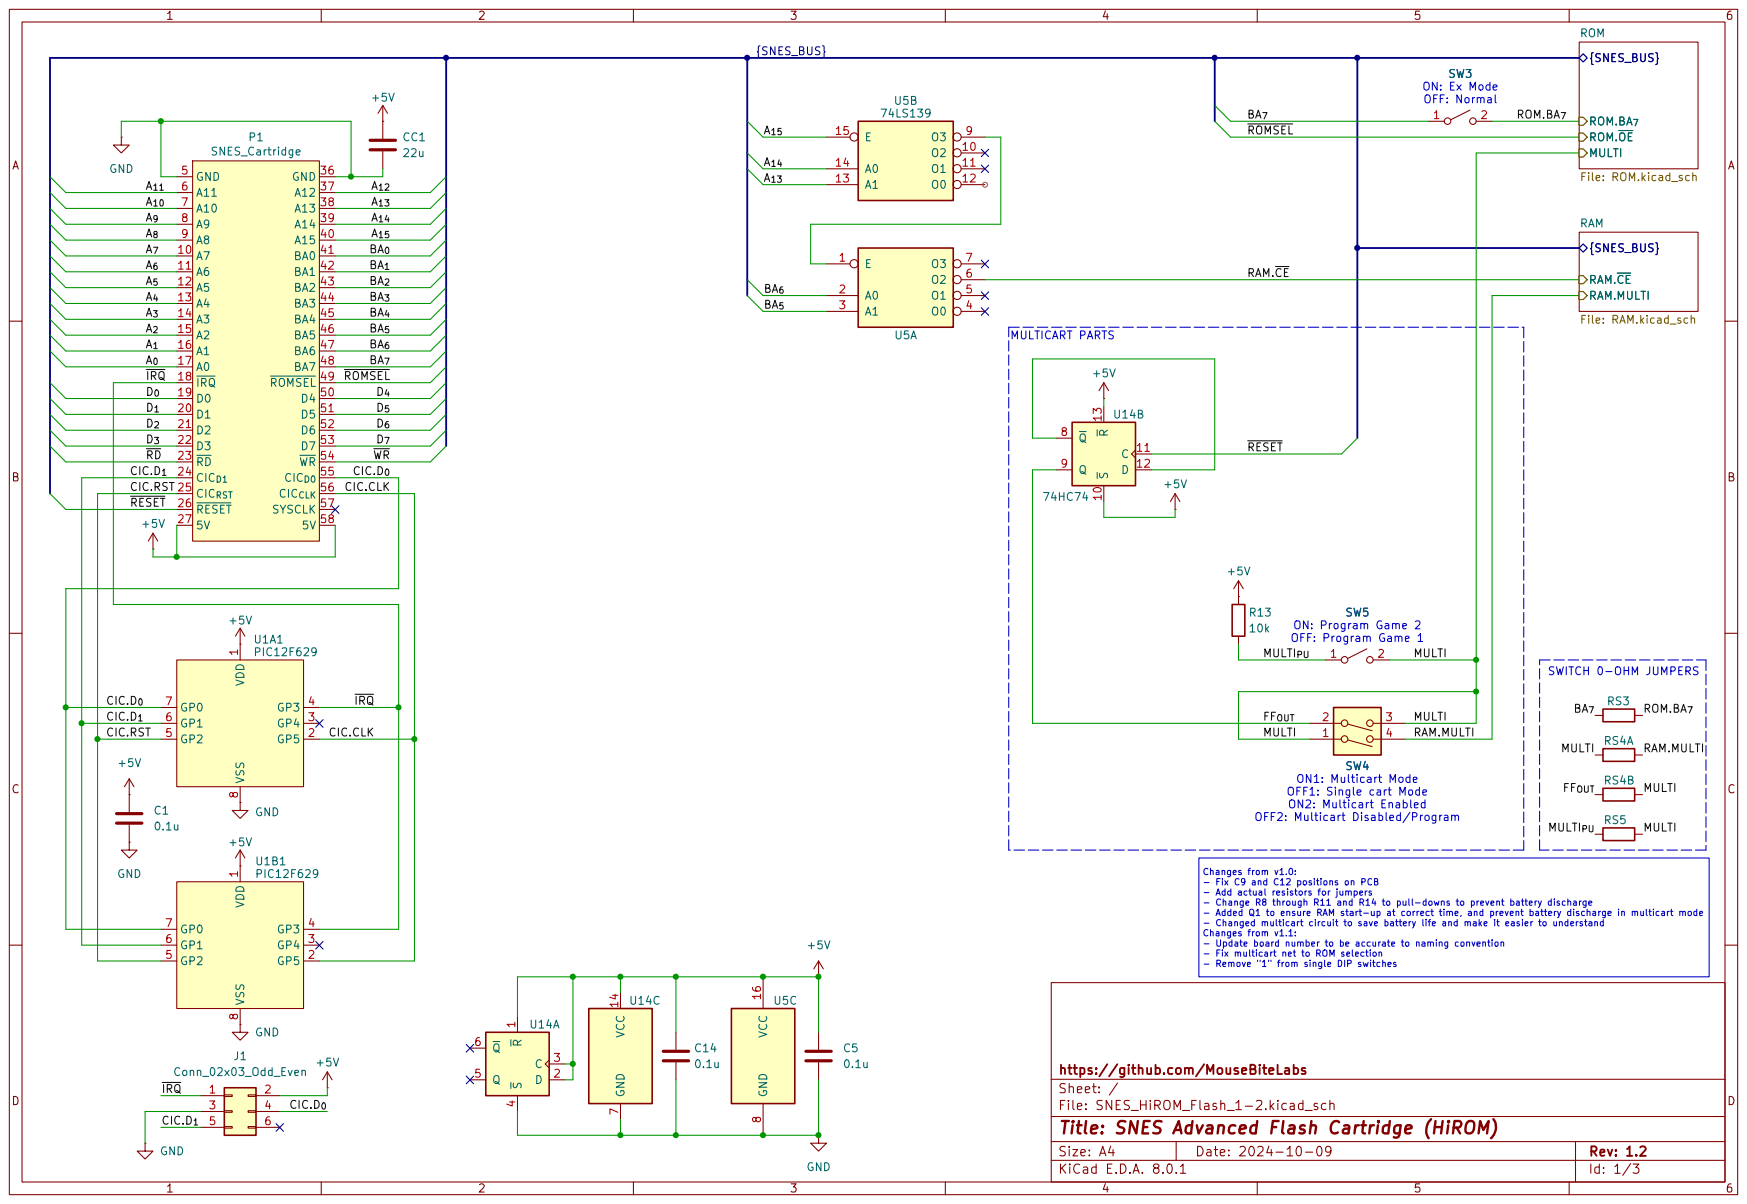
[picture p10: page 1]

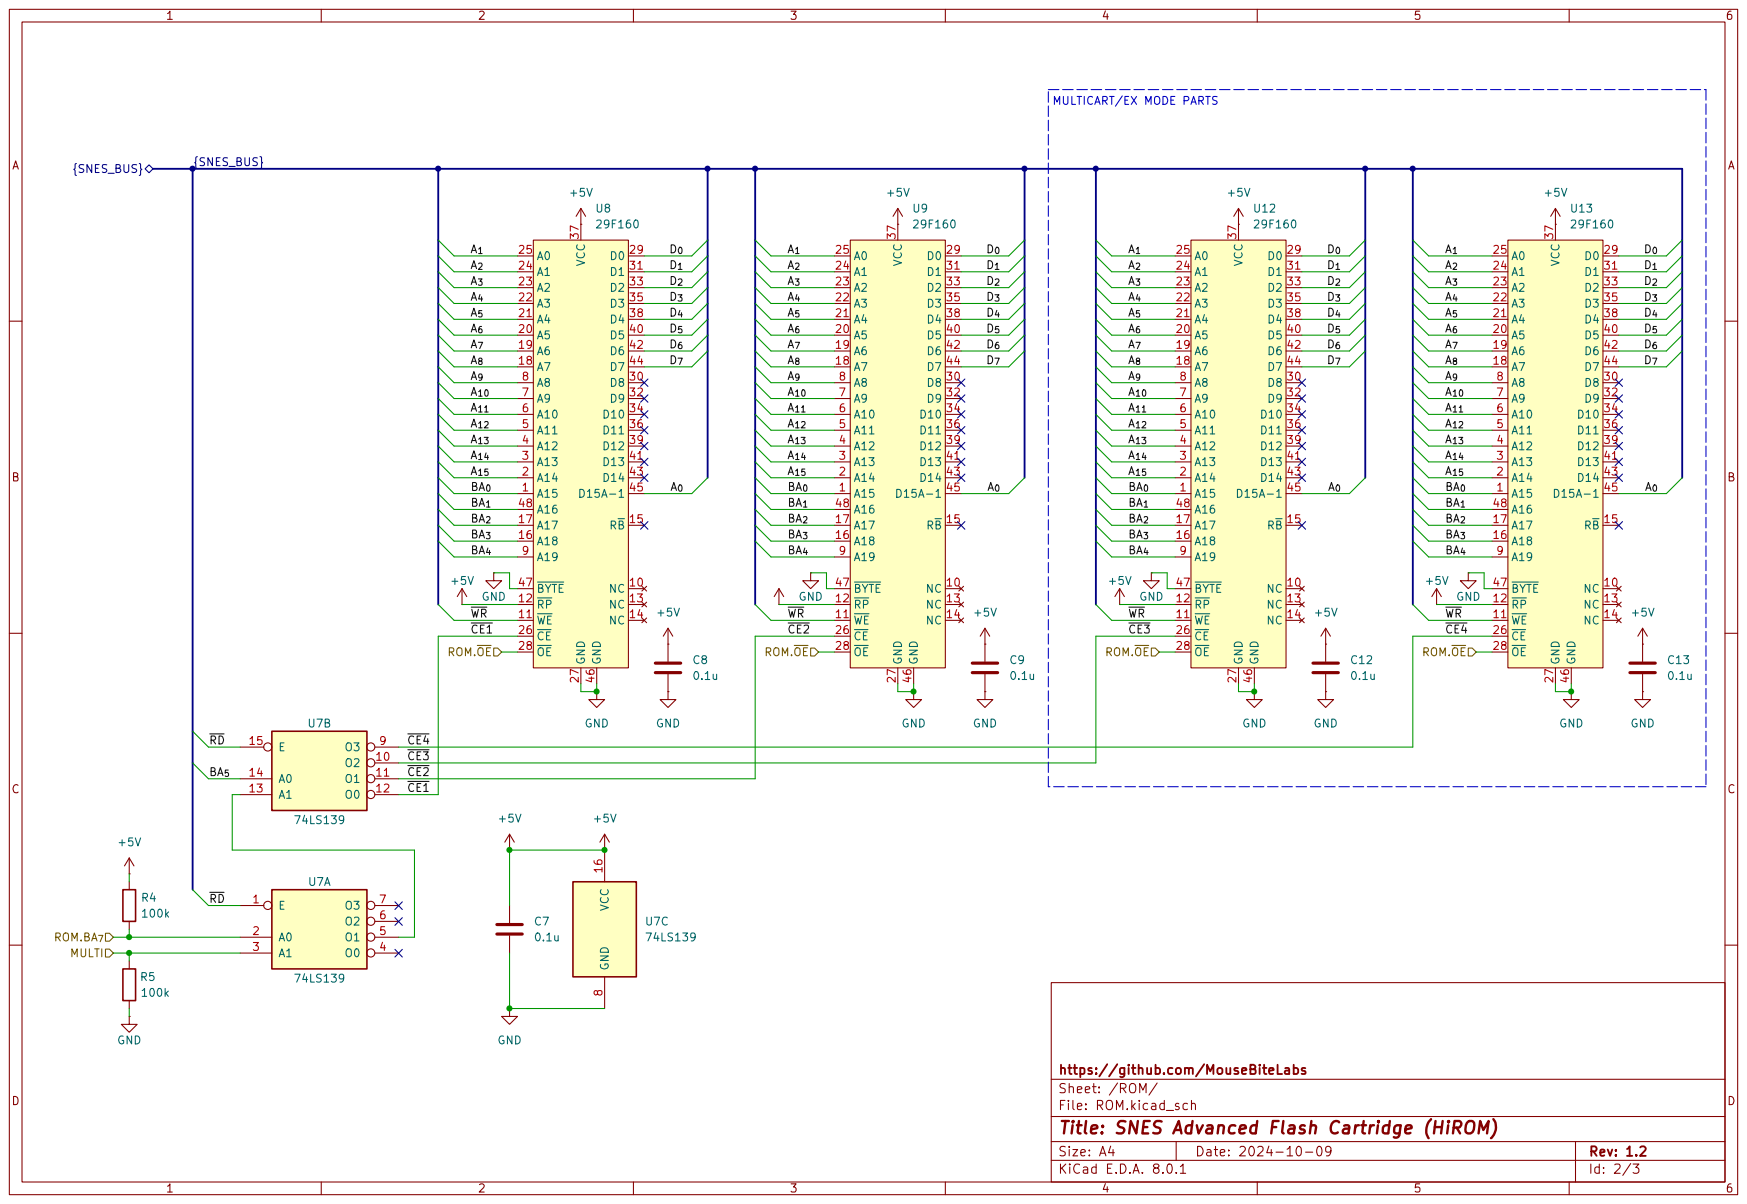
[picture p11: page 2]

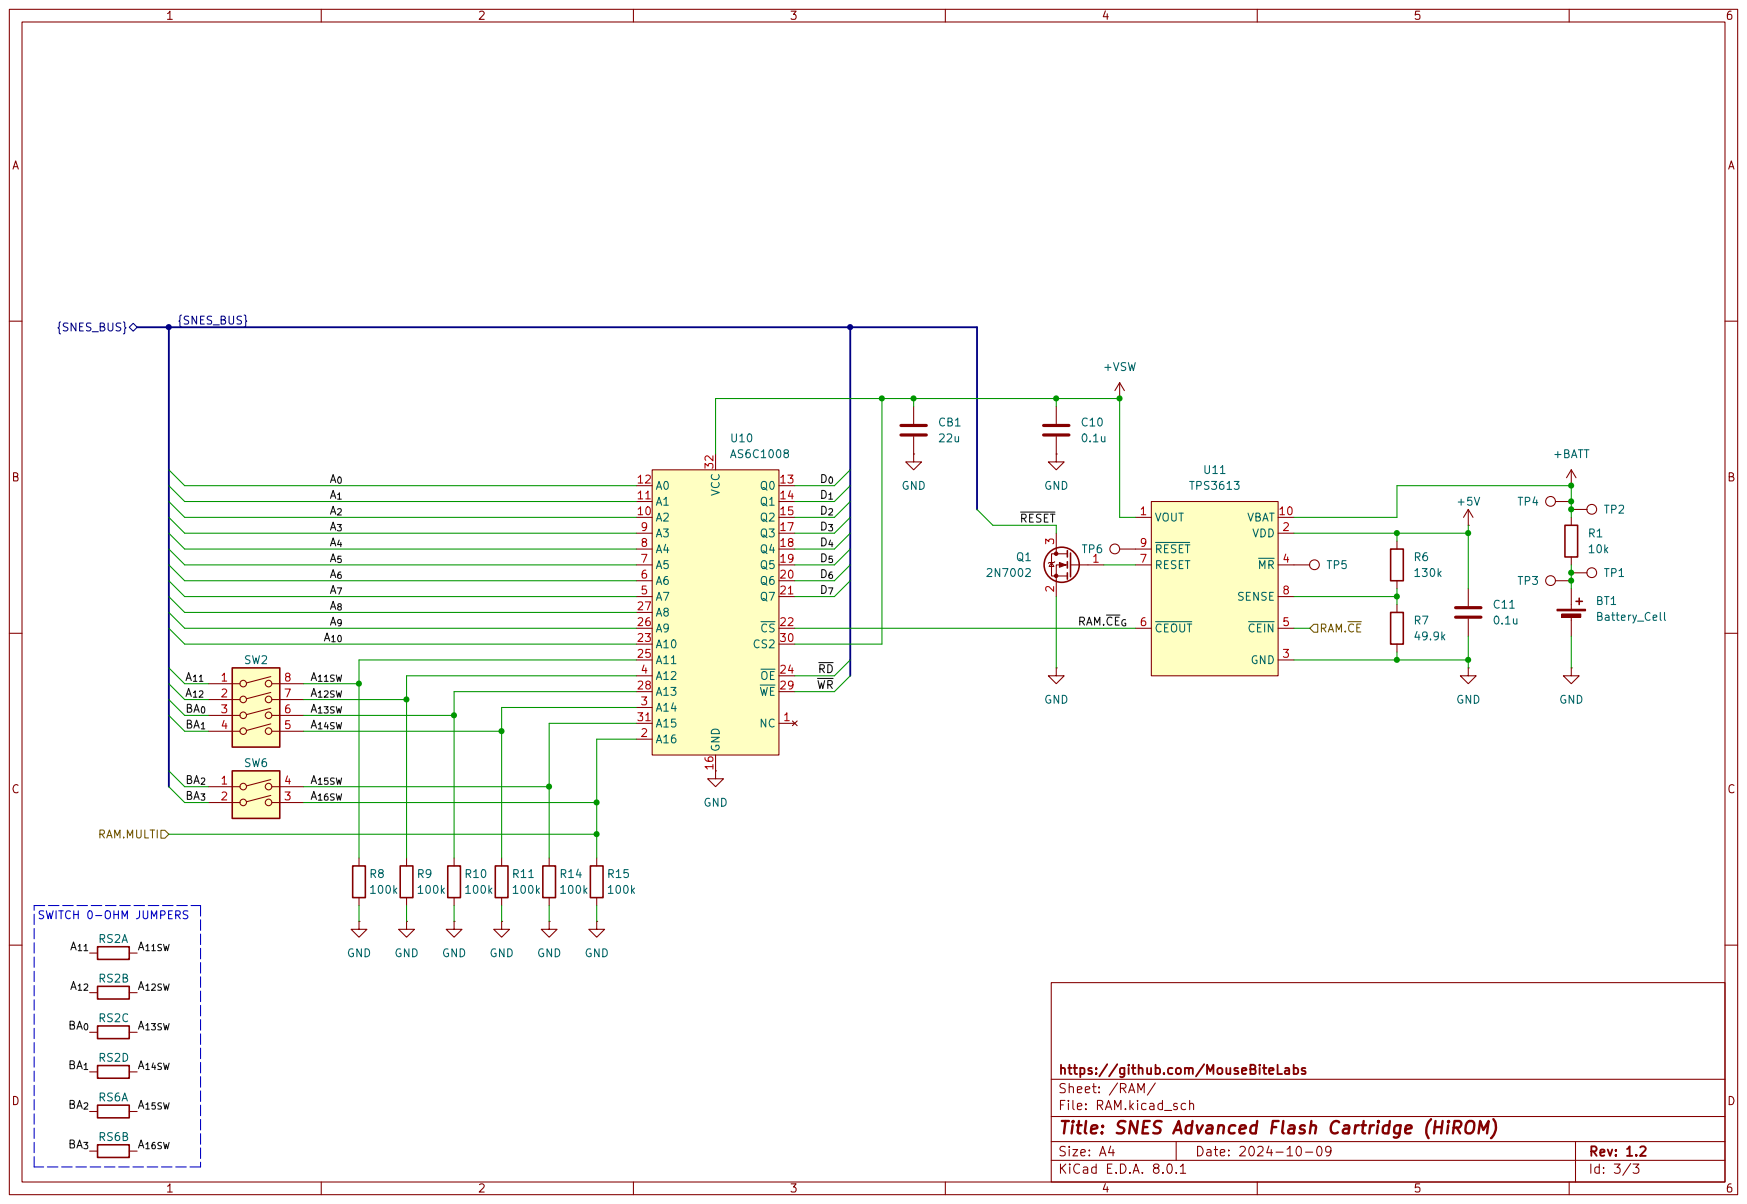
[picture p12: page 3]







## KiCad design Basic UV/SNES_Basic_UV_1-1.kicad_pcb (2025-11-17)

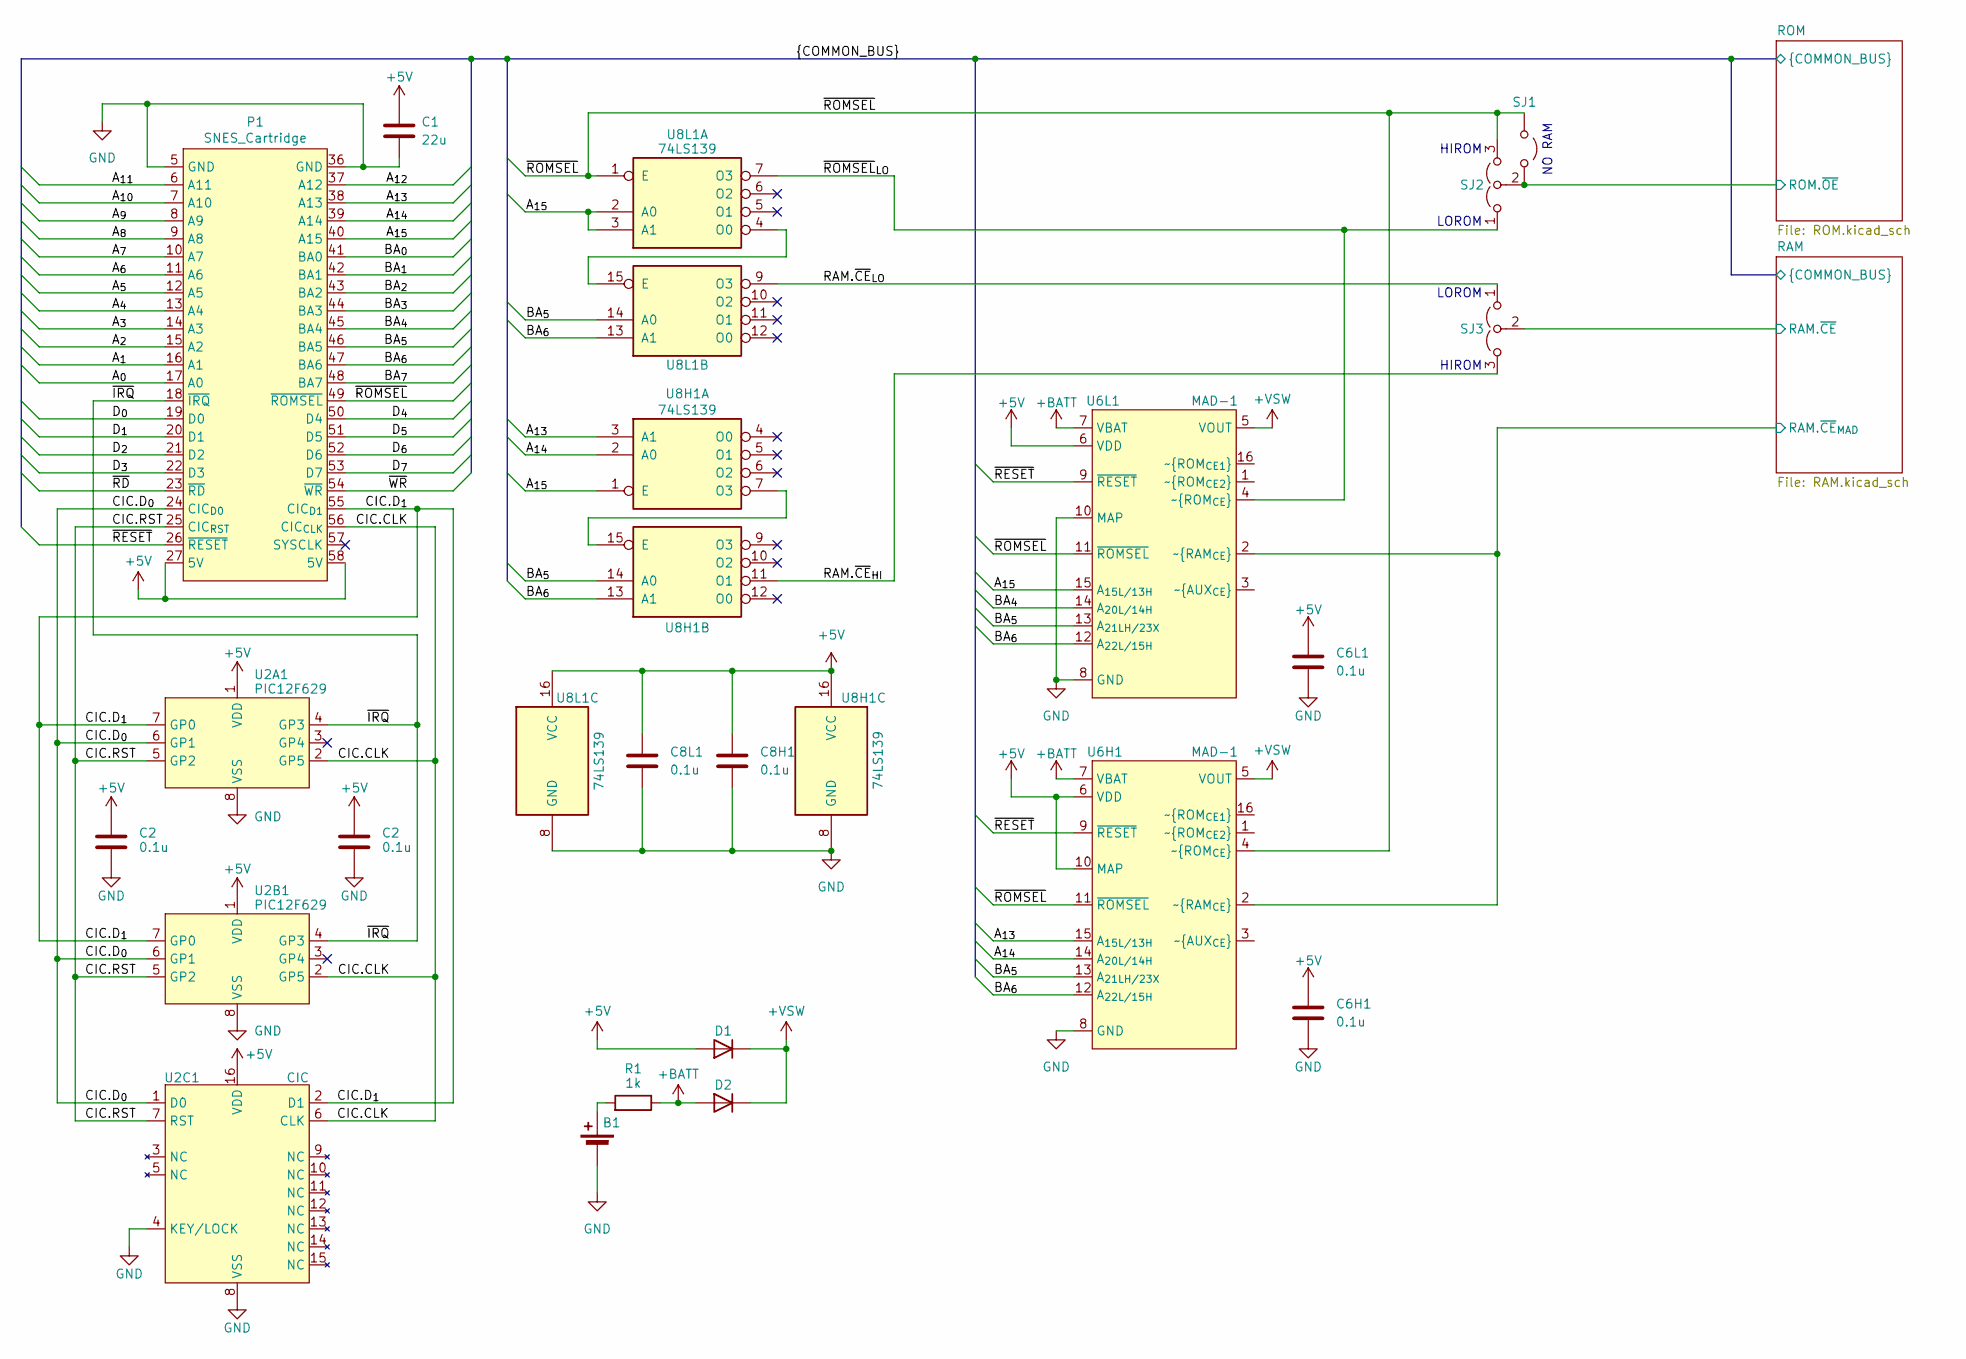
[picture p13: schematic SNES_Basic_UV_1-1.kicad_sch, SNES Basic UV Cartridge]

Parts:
B1: CR2025; COIN_CELL
C1: 22u; CP_Radial_D5.0mm_P2.50mm
C2, C6H1, C6L1, C8H1, C8L1: 0.1u; C_THT
D1, D2: D; DIODE_THT_SMT
P1: SNES_Cartridge; Cart_Edge_SNES_Standard
R1: 1k; THT_SMT_0803
SJ1: Jumper_2_Open; SJ
SJ2, SJ3: Jumper_3_Open; SJ_2
U2A1: PIC12F629; SOIC-8_3.9x4.9mm_P1.27mm
U2B1: PIC12F629; DIP-8_W7.62mm
U2C1: CIC; DIP-16_W7.62mm
U6H1, U6L1: MAD-1; DIP-16_W7.62mm
U8H1, U8L1: 74LS139; DIP-16_W7.62mm

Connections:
+5V: C1.1, C2.1, C6H1.1, C6L1.1, C8H1.1, C8L1.1, D1.2 (A), P1.27 (5V), P1.58 (5V), U2A1.1 (VDD), U2B1.1 (VDD), U2C1.16 (VDD), U6H1.6 (VDD), U6H1.10 (MAP), U6L1.6 (VDD), U8H1.16 (VCC), U8L1.16 (VCC); also elsewhere on the board
+BATT: D2.2 (A), R1.1, U6H1.7 (VBAT), U6L1.7 (VBAT)
+VSW: D1.1 (K), D2.1 (K), U6H1.5 (VOUT), U6L1.5 (VOUT); also elsewhere on the board
/A_{0}: P1.17 (A0); also elsewhere on the board
/A_{1}: P1.16 (A1); also elsewhere on the board
/A_{2}: P1.15 (A2); also elsewhere on the board
/A_{3}: P1.14 (A3); also elsewhere on the board
/A_{4}: P1.13 (A4); also elsewhere on the board
/A_{5}: P1.12 (A5); also elsewhere on the board
/A_{6}: P1.11 (A6); also elsewhere on the board
/A_{7}: P1.10 (A7); also elsewhere on the board
/A_{8}: P1.9 (A8); also elsewhere on the board
/A_{9}: P1.8 (A9); also elsewhere on the board
/A_{10}: P1.7 (A10); also elsewhere on the board
/A_{11}: P1.6 (A11); also elsewhere on the board
/A_{12}: P1.37 (A12); also elsewhere on the board
/A_{13}: P1.38 (A13), U6H1.15 (A_{15L/13H}), U8H1.3 (A1); also elsewhere on the board
/A_{14}: P1.39 (A14), U6H1.14 (A_{20L/14H}), U8H1.2 (A0); also elsewhere on the board
/A_{15}: P1.40 (A15), U6L1.15 (A_{15L/13H}), U8H1.1 (E), U8L1.2 (A0), U8L1.3 (A1); also elsewhere on the board
/BA_{0}: P1.41 (BA0); also elsewhere on the board
/BA_{1}: P1.42 (BA1); also elsewhere on the board
/BA_{2}: P1.43 (BA2); also elsewhere on the board
/BA_{3}: P1.44 (BA3); also elsewhere on the board
/BA_{4}: P1.45 (BA4), U6L1.14 (A_{20L/14H}); also elsewhere on the board
/BA_{5}: P1.46 (BA5), U6H1.13 (A_{21LH/23X}), U6L1.13 (A_{21LH/23X}), U8H1.14 (A0), U8L1.14 (A0); also elsewhere on the board
/BA_{6}: P1.47 (BA6), U6H1.12 (A_{22L/15H}), U6L1.12 (A_{22L/15H}), U8H1.13 (A1), U8L1.13 (A1); also elsewhere on the board
/BA_{7}: P1.48 (BA7); also elsewhere on the board
/CIC.CLK: P1.56 (CIC_{CLK}), U2A1.2 (GP5), U2B1.2 (GP5), U2C1.6 (CLK)
/CIC.D_{0}: P1.24 (CIC_{D0}), U2A1.6 (GP1), U2B1.6 (GP1), U2C1.1 (D0)
/CIC.D_{1}: P1.55 (CIC_{D1}), U2A1.7 (GP0), U2B1.7 (GP0), U2C1.2 (D1)
/CIC.RST: P1.25 (CIC_{RST}), U2A1.5 (GP2), U2B1.5 (GP2), U2C1.7 (RST)
/D_{0}: P1.19 (D0); also elsewhere on the board
/D_{1}: P1.20 (D1); also elsewhere on the board
/D_{2}: P1.21 (D2); also elsewhere on the board
/D_{3}: P1.22 (D3); also elsewhere on the board
/D_{4}: P1.50 (D4); also elsewhere on the board
/D_{5}: P1.51 (D5); also elsewhere on the board
/D_{6}: P1.52 (D6); also elsewhere on the board
/D_{7}: P1.53 (D7); also elsewhere on the board
/RAM.~CE_{HI}: SJ3.3 (B), U8H1.11 (O1)
/RAM.~CE_{LO}: SJ3.1 (A), U8L1.9 (O3)
/RAM/RAM.~CE: SJ3.2 (C); also elsewhere on the board
/RAM/~CE_{SRAM}: U6H1.2 (~RAM_{CE}), U6L1.2 (~RAM_{CE}); also elsewhere on the board
/ROM/ROM.~OE: SJ1.1 (A), SJ2.2 (C); also elsewhere on the board
/~IRQ: P1.18 (~IRQ), U2A1.4 (GP3), U2B1.4 (GP3)
/~RD: P1.23 (~RD); also elsewhere on the board
/~RESET: P1.26 (~RESET), U6H1.9 (~RESET), U6L1.9 (~RESET); also elsewhere on the board
/~ROMSEL: P1.49 (~ROMSEL), SJ1.2 (B), SJ2.3 (B), U6H1.4 (~ROM_{CE}), U6H1.11 (~ROMSEL), U6L1.11 (~ROMSEL), U8L1.1 (E)
/~ROMSEL_{LO}: SJ2.1 (A), U6L1.4 (~ROM_{CE}), U8L1.7 (O3)
/~WR: P1.54 (~WR); also elsewhere on the board
GND: B1.2 (-), C1.2, C2.2, C6H1.2, C6L1.2, C8H1.2, C8L1.2, P1.5 (GND), P1.36 (GND), U2A1.8 (VSS), U2B1.8 (VSS), U2C1.4 (KEY/LOCK), U2C1.8 (VSS), U6H1.8 (GND), U6L1.8 (GND), U6L1.10 (MAP), U8H1.8 (GND), U8L1.8 (GND); also elsewhere on the board
unnamed: B1.1 (+), R1.2
unnamed: U8H1.7 (O3), U8H1.15 (E)
unnamed: U8L1.4 (O0), U8L1.15 (E)

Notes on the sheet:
HIROM LOROM
NO RAM
LOROM HIROM

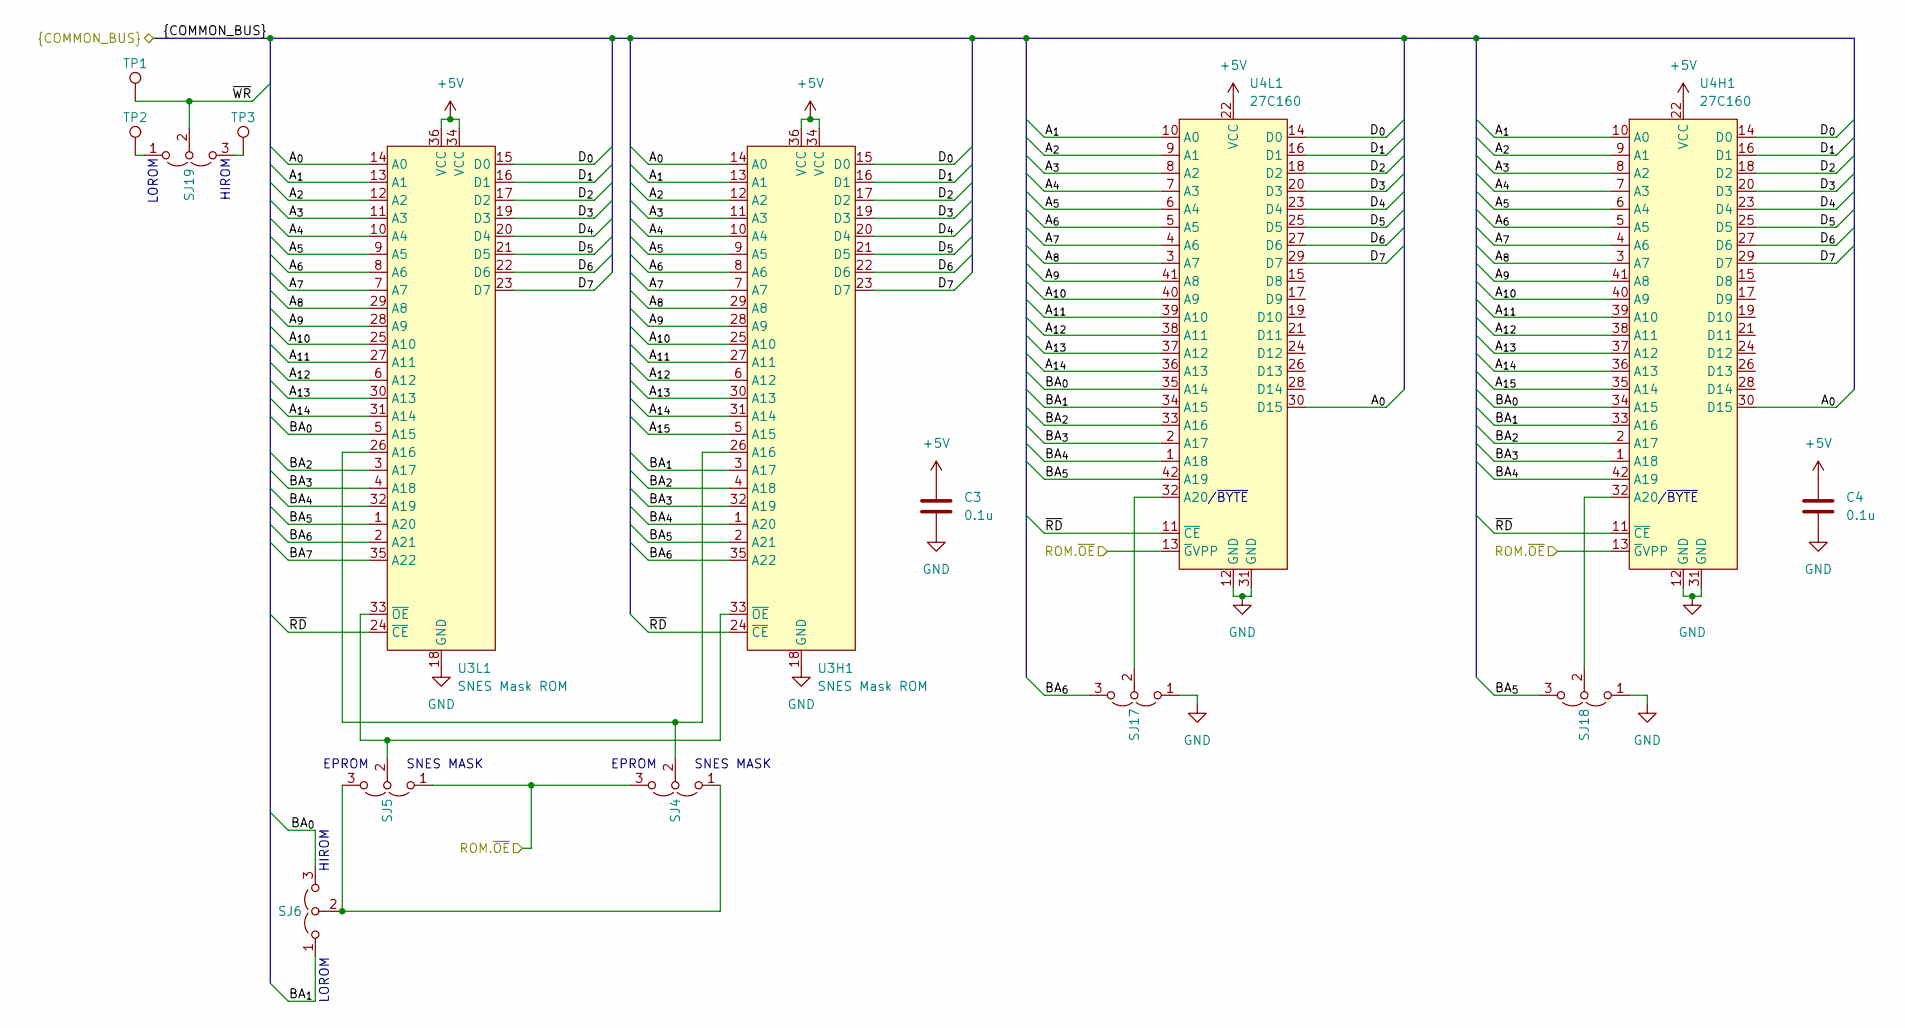
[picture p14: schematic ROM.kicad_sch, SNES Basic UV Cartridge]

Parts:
C3, C4: 0.1u; C_THT
SJ4, SJ5, SJ6, SJ17, SJ18, SJ19: Jumper_3_Open; SJ_2
TP1, TP2, TP3: TPB1,27; TestPoint_THTPad_D1.5mm_Drill0.7mm
U3H1, U3L1: SNES Mask ROM; 36-PDIP_SLIM
U4H1, U4L1: 27C160; DIP-42_W15.24mm

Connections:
+5V: C3.1, C4.1, U3H1.34 (VCC), U3H1.36 (VCC), U3L1.34 (VCC), U3L1.36 (VCC), U4H1.22 (VCC), U4L1.22 (VCC); also elsewhere on the board
/A_{0}: U3H1.14 (A0), U3L1.14 (A0), U4H1.30 (D15), U4L1.30 (D15); also elsewhere on the board
/A_{1}: U3H1.13 (A1), U3L1.13 (A1), U4H1.10 (A0), U4L1.10 (A0); also elsewhere on the board
/A_{2}: U3H1.12 (A2), U3L1.12 (A2), U4H1.9 (A1), U4L1.9 (A1); also elsewhere on the board
/A_{3}: U3H1.11 (A3), U3L1.11 (A3), U4H1.8 (A2), U4L1.8 (A2); also elsewhere on the board
/A_{4}: U3H1.10 (A4), U3L1.10 (A4), U4H1.7 (A3), U4L1.7 (A3); also elsewhere on the board
/A_{5}: U3H1.9 (A5), U3L1.9 (A5), U4H1.6 (A4), U4L1.6 (A4); also elsewhere on the board
/A_{6}: U3H1.8 (A6), U3L1.8 (A6), U4H1.5 (A5), U4L1.5 (A5); also elsewhere on the board
/A_{7}: U3H1.7 (A7), U3L1.7 (A7), U4H1.4 (A6), U4L1.4 (A6); also elsewhere on the board
/A_{8}: U3H1.29 (A8), U3L1.29 (A8), U4H1.3 (A7), U4L1.3 (A7); also elsewhere on the board
/A_{9}: U3H1.28 (A9), U3L1.28 (A9), U4H1.41 (A8), U4L1.41 (A8); also elsewhere on the board
/A_{10}: U3H1.25 (A10), U3L1.25 (A10), U4H1.40 (A9), U4L1.40 (A9); also elsewhere on the board
/A_{11}: U3H1.27 (A11), U3L1.27 (A11), U4H1.39 (A10), U4L1.39 (A10); also elsewhere on the board
/A_{12}: U3H1.6 (A12), U3L1.6 (A12), U4H1.38 (A11), U4L1.38 (A11); also elsewhere on the board
/A_{13}: U3H1.30 (A13), U3L1.30 (A13), U4H1.37 (A12), U4L1.37 (A12); also elsewhere on the board
/A_{14}: U3H1.31 (A14), U3L1.31 (A14), U4H1.36 (A13), U4L1.36 (A13); also elsewhere on the board
/A_{15}: U3H1.5 (A15), U4H1.35 (A14); also elsewhere on the board
/BA_{0}: SJ6.3 (B), U3L1.5 (A15), U4H1.34 (A15), U4L1.35 (A14); also elsewhere on the board
/BA_{1}: SJ6.1 (A), U3H1.3 (A17), U4H1.33 (A16), U4L1.34 (A15); also elsewhere on the board
/BA_{2}: U3H1.4 (A18), U3L1.3 (A17), U4H1.2 (A17), U4L1.33 (A16); also elsewhere on the board
/BA_{3}: U3H1.32 (A19), U3L1.4 (A18), U4H1.1 (A18), U4L1.2 (A17); also elsewhere on the board
/BA_{4}: U3H1.1 (A20), U3L1.32 (A19), U4H1.42 (A19), U4L1.1 (A18); also elsewhere on the board
/BA_{5}: SJ18.3 (B), U3H1.2 (A21), U3L1.1 (A20), U4L1.42 (A19); also elsewhere on the board
/BA_{6}: SJ17.3 (B), U3H1.35 (A22), U3L1.2 (A21); also elsewhere on the board
/BA_{7}: U3L1.35 (A22); also elsewhere on the board
/D_{0}: U3H1.15 (D0), U3L1.15 (D0), U4H1.14 (D0), U4L1.14 (D0); also elsewhere on the board
/D_{1}: U3H1.16 (D1), U3L1.16 (D1), U4H1.16 (D1), U4L1.16 (D1); also elsewhere on the board
/D_{2}: U3H1.17 (D2), U3L1.17 (D2), U4H1.18 (D2), U4L1.18 (D2); also elsewhere on the board
/D_{3}: U3H1.19 (D3), U3L1.19 (D3), U4H1.20 (D3), U4L1.20 (D3); also elsewhere on the board
/D_{4}: U3H1.20 (D4), U3L1.20 (D4), U4H1.23 (D4), U4L1.23 (D4); also elsewhere on the board
/D_{5}: U3H1.21 (D5), U3L1.21 (D5), U4H1.25 (D5), U4L1.25 (D5); also elsewhere on the board
/D_{6}: U3H1.22 (D6), U3L1.22 (D6), U4H1.27 (D6), U4L1.27 (D6); also elsewhere on the board
/D_{7}: U3H1.23 (D7), U3L1.23 (D7), U4H1.29 (D7), U4L1.29 (D7); also elsewhere on the board
/ROM/ROM.~OE: SJ4.3 (B), SJ5.1 (A), U4H1.13 (~GVPP), U4L1.13 (~GVPP); also elsewhere on the board
/~RD: U3H1.24 (~CE), U3L1.24 (~CE), U4H1.11 (~CE), U4L1.11 (~CE); also elsewhere on the board
/~WR: SJ19.2 (C), TP1.1; also elsewhere on the board
GND: C3.2, C4.2, SJ17.1 (A), SJ18.1 (A), U3H1.18 (GND), U3L1.18 (GND), U4H1.12 (GND), U4H1.31 (GND), U4L1.12 (GND), U4L1.31 (GND); also elsewhere on the board
unnamed: SJ4.1 (A), SJ5.3 (B), SJ6.2 (C)
unnamed: SJ4.2 (C), U3H1.26 (A16), U3L1.26 (A16)
unnamed: SJ5.2 (C), U3H1.33 (~OE), U3L1.33 (~OE)
unnamed: SJ17.2 (C), U4L1.32 (A20)
unnamed: SJ18.2 (C), U4H1.32 (A20)
unnamed: SJ19.1 (A), TP2.1
unnamed: SJ19.3 (B), TP3.1

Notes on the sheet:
LOROM
SNES MASK
/~{BYTE}
HIROM
EPROM
LOROM HIROM

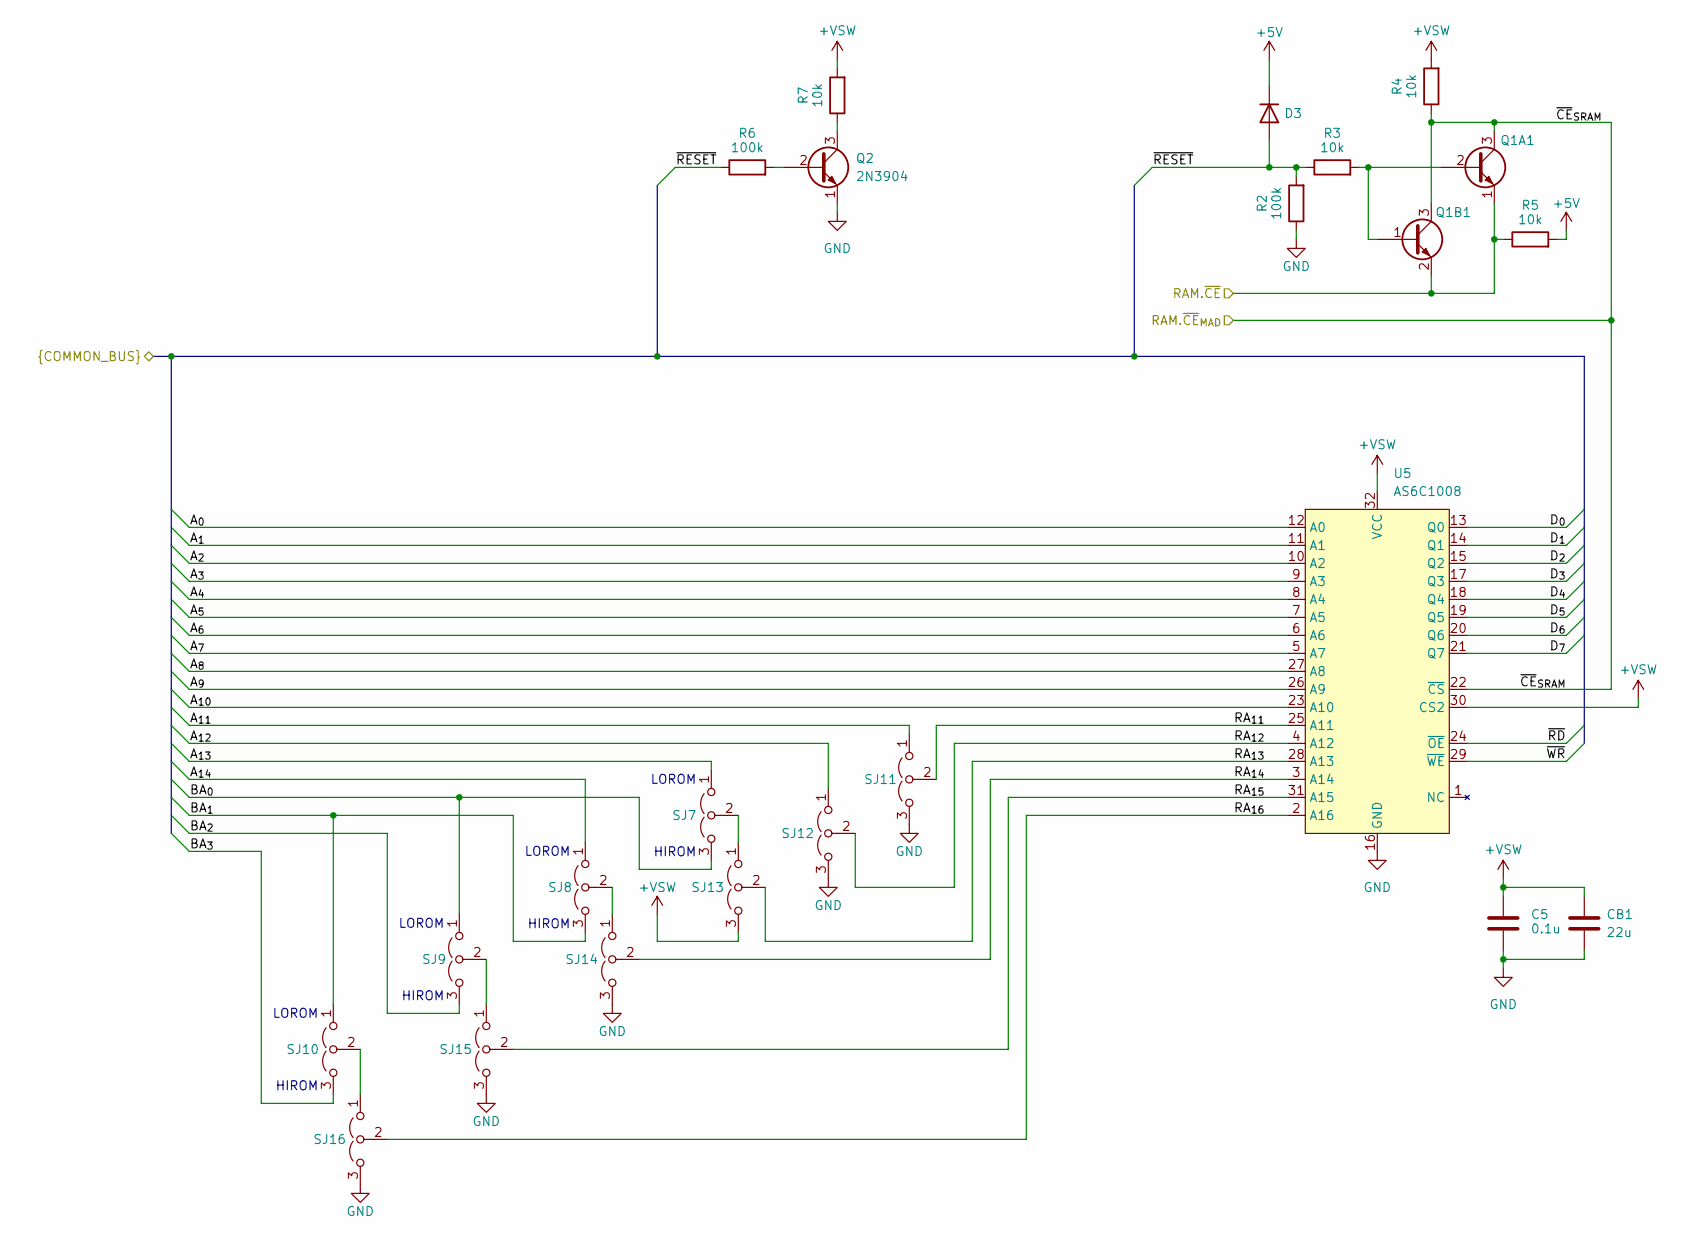
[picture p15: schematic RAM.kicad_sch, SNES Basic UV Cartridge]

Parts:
C5: 0.1u; C_THT
CB1: 22u; CP_Radial_D5.0mm_P2.50mm
D3: D; DIODE_THT_SMT
Q1A1, Q2: 2N3904; TO-92L_Inline_Wide
Q1B1: MMBT3904; SOT-23
R2, R6: 100k; THT_SMT_0803
R3, R4, R5, R7: 10k; THT_SMT_0803
SJ7, SJ8, SJ9, SJ10, SJ11, SJ12, SJ13, SJ14, SJ15, SJ16: Jumper_3_Open; SJ_2
U5: AS6C1008; DIP-32_W15.24mm

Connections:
+5V: D3.1 (K), R5.2; also elsewhere on the board
+VSW: C5.1, CB1.1, R4.2, R7.2, SJ13.3 (B), U5.30 (CS2), U5.32 (VCC); also elsewhere on the board
/A_{0}: U5.12 (A0); also elsewhere on the board
/A_{1}: U5.11 (A1); also elsewhere on the board
/A_{2}: U5.10 (A2); also elsewhere on the board
/A_{3}: U5.9 (A3); also elsewhere on the board
/A_{4}: U5.8 (A4); also elsewhere on the board
/A_{5}: U5.7 (A5); also elsewhere on the board
/A_{6}: U5.6 (A6); also elsewhere on the board
/A_{7}: U5.5 (A7); also elsewhere on the board
/A_{8}: U5.27 (A8); also elsewhere on the board
/A_{9}: U5.26 (A9); also elsewhere on the board
/A_{10}: U5.23 (A10); also elsewhere on the board
/A_{11}: SJ11.1 (A); also elsewhere on the board
/A_{12}: SJ12.1 (A); also elsewhere on the board
/A_{13}: SJ7.1 (A); also elsewhere on the board
/A_{14}: SJ8.1 (A); also elsewhere on the board
/BA_{0}: SJ7.3 (B), SJ9.1 (A); also elsewhere on the board
/BA_{1}: SJ8.3 (B), SJ10.1 (A); also elsewhere on the board
/BA_{2}: SJ9.3 (B); also elsewhere on the board
/BA_{3}: SJ10.3 (B); also elsewhere on the board
/D_{0}: U5.13 (Q0); also elsewhere on the board
/D_{1}: U5.14 (Q1); also elsewhere on the board
/D_{2}: U5.15 (Q2); also elsewhere on the board
/D_{3}: U5.17 (Q3); also elsewhere on the board
/D_{4}: U5.18 (Q4); also elsewhere on the board
/D_{5}: U5.19 (Q5); also elsewhere on the board
/D_{6}: U5.20 (Q6); also elsewhere on the board
/D_{7}: U5.21 (Q7); also elsewhere on the board
/RAM/RAM.~CE: Q1A1.1 (E), Q1B1.2 (E), R5.1; also elsewhere on the board
/RAM/RA_{11}: SJ11.2 (C), U5.25 (A11)
/RAM/RA_{12}: SJ12.2 (C), U5.4 (A12)
/RAM/RA_{13}: SJ13.2 (C), U5.28 (A13)
/RAM/RA_{14}: SJ14.2 (C), U5.3 (A14)
/RAM/RA_{15}: SJ15.2 (C), U5.31 (A15)
/RAM/RA_{16}: SJ16.2 (C), U5.2 (A16)
/RAM/~CE_{SRAM}: Q1A1.3 (C), Q1B1.3 (C), R4.1, U5.22 (~CS); also elsewhere on the board
/~RD: U5.24 (~OE); also elsewhere on the board
/~RESET: D3.2 (A), R2.2, R3.1, R6.1; also elsewhere on the board
/~WR: U5.29 (~WE); also elsewhere on the board
GND: C5.2, CB1.2, Q2.1 (E), R2.1, SJ11.3 (B), SJ12.3 (B), SJ14.3 (B), SJ15.3 (B), SJ16.3 (B), U5.16 (GND); also elsewhere on the board
unnamed: Q1A1.2 (B), Q1B1.1 (B), R3.2
unnamed: Q2.2 (B), R6.2
unnamed: Q2.3 (C), R7.1
unnamed: SJ10.2 (C), SJ16.1 (A)
unnamed: SJ7.2 (C), SJ13.1 (A)
unnamed: SJ8.2 (C), SJ14.1 (A)
unnamed: SJ9.2 (C), SJ15.1 (A)

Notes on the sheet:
LOROM HIROM

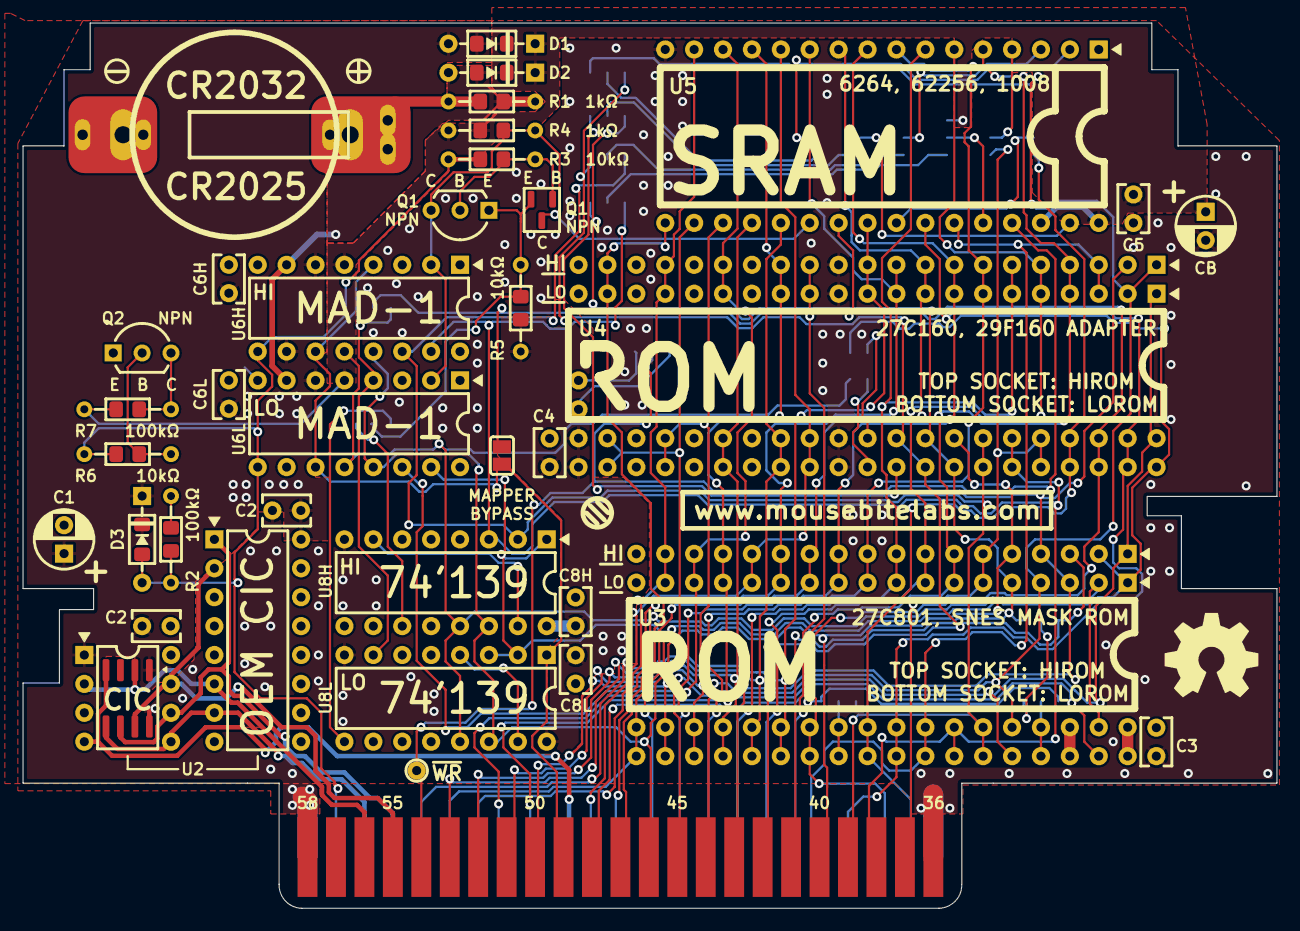
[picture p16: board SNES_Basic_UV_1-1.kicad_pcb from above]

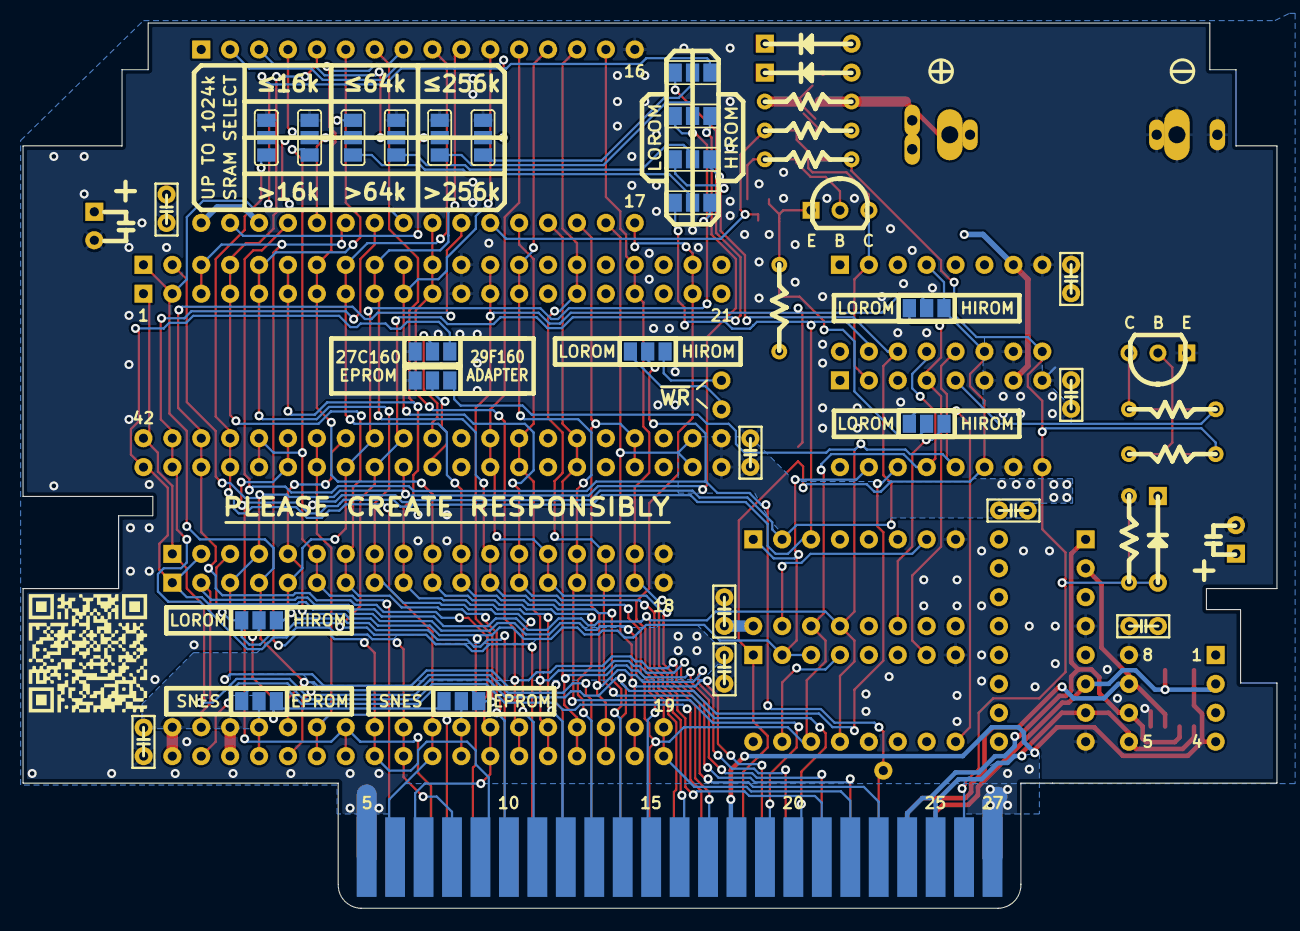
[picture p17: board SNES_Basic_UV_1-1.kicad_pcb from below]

Board: 2 copper layers, 110.2 x 77.8 mm, 60 parts (18 on the bottom side), 74 nets.

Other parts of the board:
C2#2, C6H, C6L, C8H, C8L: 0.1u; C_THT
CB: 22u; CP_Radial_D5.0mm_P2.50mm

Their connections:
+5V: C2#2.1, C6H.1, C6L.1, C8H.1, C8L.1; also elsewhere on the board
+VSW: CB.1; also elsewhere on the board
GND: C2#2.2, C6H.2, C6L.2, C8H.2, C8L.2, CB.2; also elsewhere on the board

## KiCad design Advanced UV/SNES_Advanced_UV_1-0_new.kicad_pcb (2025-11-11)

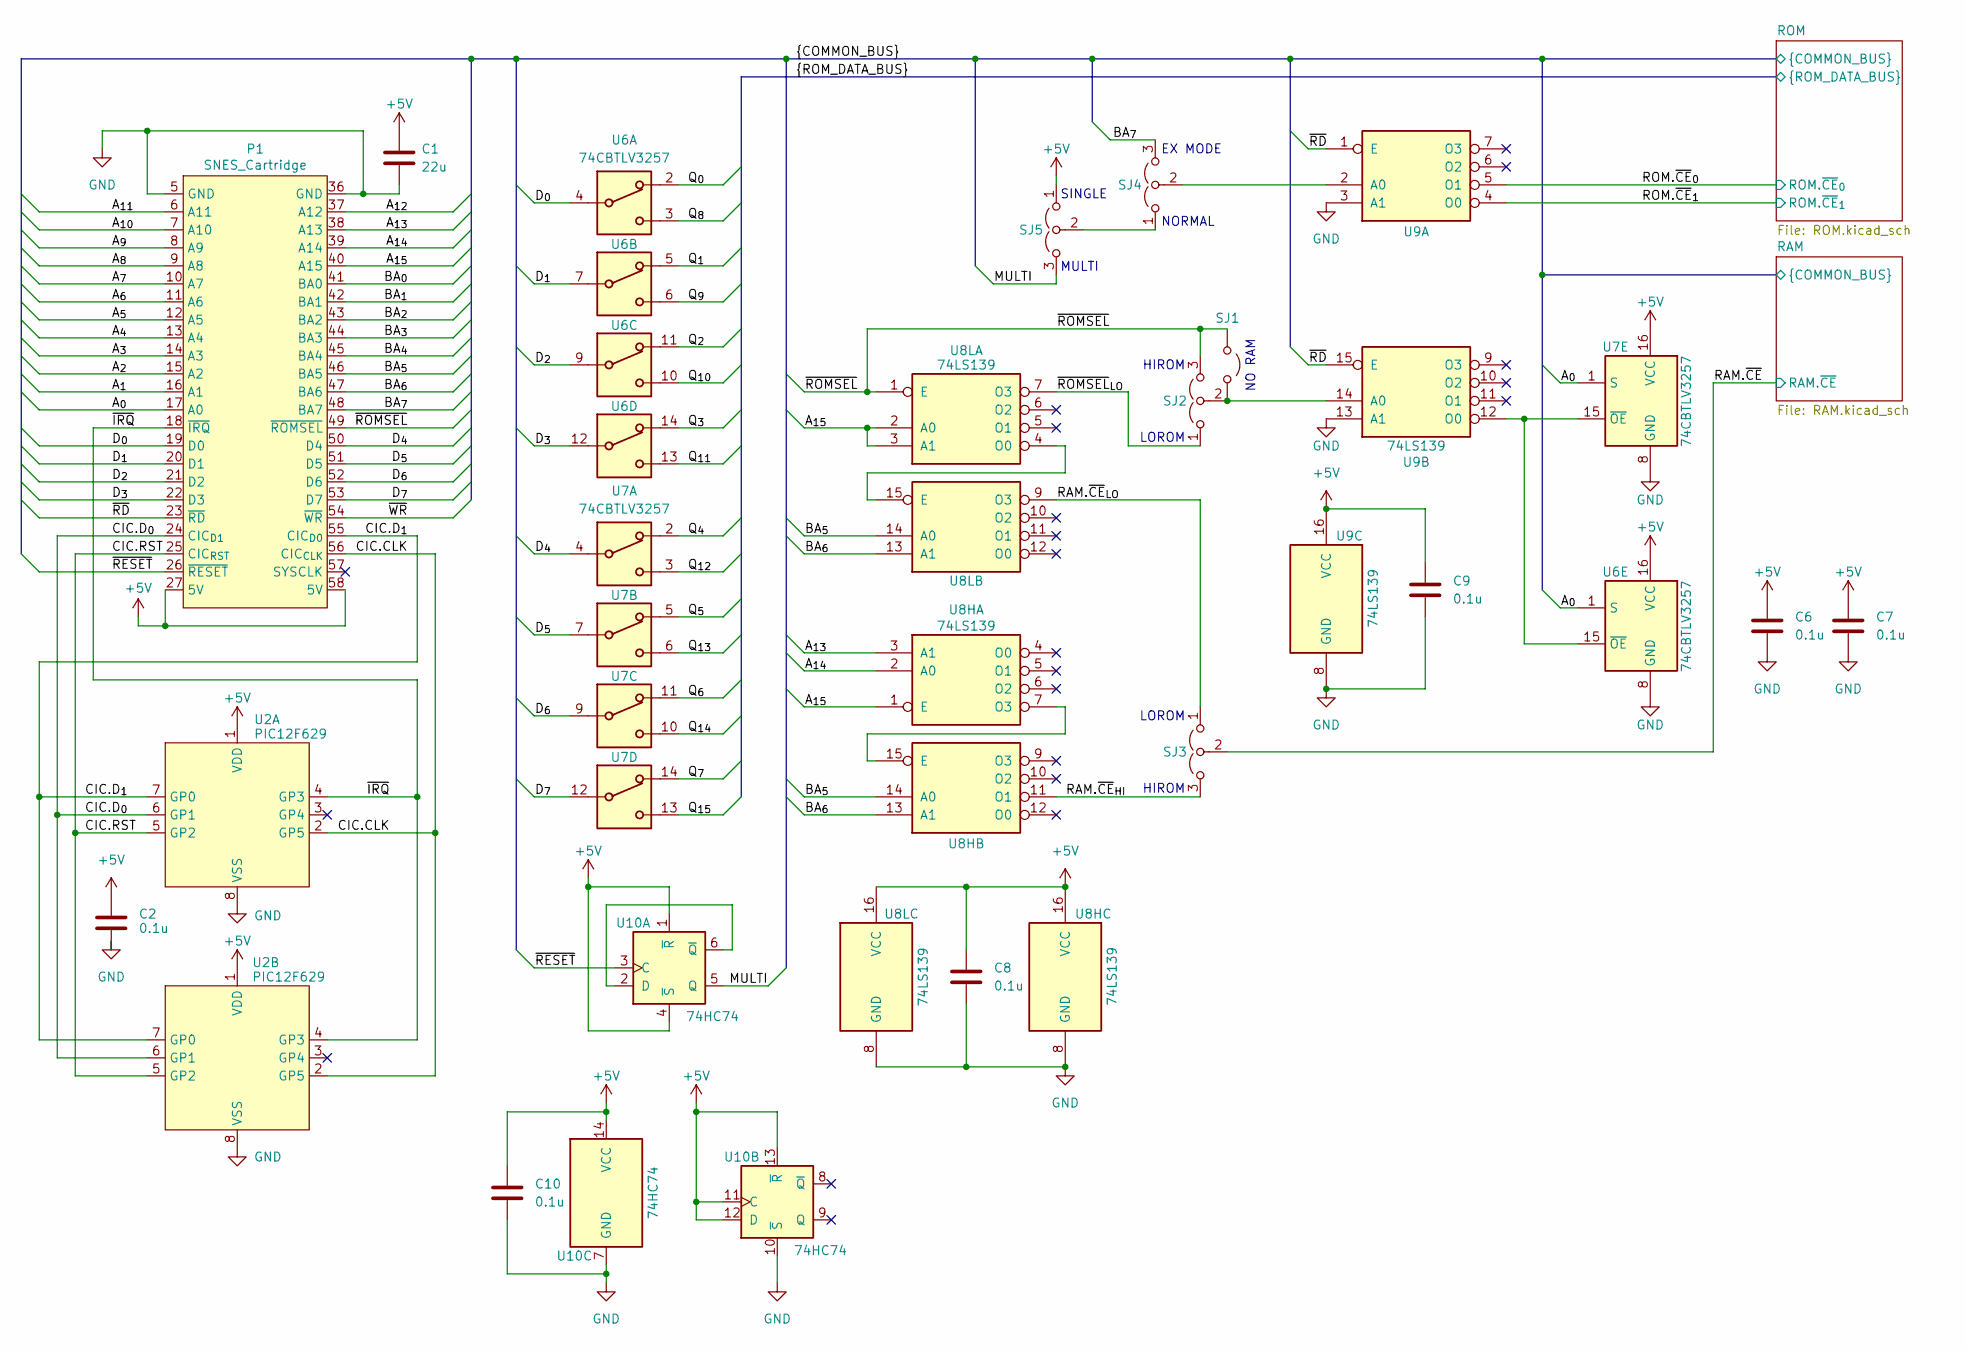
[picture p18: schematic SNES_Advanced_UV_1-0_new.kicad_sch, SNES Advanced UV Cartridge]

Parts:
C1: 22u; CP_Radial_D5.0mm_P2.50mm
C2, C6, C7, C8, C9, C10: 0.1u; C_THT
P1: SNES_Cartridge; Cart_Edge_SNES_Standard
SJ1: Jumper_2_Open; SJ
SJ2, SJ3, SJ4, SJ5: Jumper_3_Open; SJ_2
U2A: PIC12F629; SOIC-8_3.9x4.9mm_P1.27mm
U2B: PIC12F629; DIP-8_W7.62mm
U6, U7: 74CBTLV3257; DIP-16_W7.62mm
U8H, U8L, U9: 74LS139; DIP-16_W7.62mm
U10: 74HC74; DIP-14_W7.62mm

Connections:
+5V: C1.1, C2.1, C6.1, C7.1, C8.1, C9.1, C10.1, P1.27 (5V), P1.58 (5V), SJ5.1 (A), U2A.1 (VDD), U2B.1 (VDD), U6.16 (VCC), U7.16 (VCC), U8H.16 (VCC), U8L.16 (VCC), U9.16 (VCC), U10.1 (~R), U10.4 (~S), U10.11 (C), U10.12 (D), U10.13 (~R), U10.14 (VCC); also elsewhere on the board
/A_{0}: P1.17 (A0), U6.1 (S), U7.1 (S); also elsewhere on the board
/A_{1}: P1.16 (A1); also elsewhere on the board
/A_{2}: P1.15 (A2); also elsewhere on the board
/A_{3}: P1.14 (A3); also elsewhere on the board
/A_{4}: P1.13 (A4); also elsewhere on the board
/A_{5}: P1.12 (A5); also elsewhere on the board
/A_{6}: P1.11 (A6); also elsewhere on the board
/A_{7}: P1.10 (A7); also elsewhere on the board
/A_{8}: P1.9 (A8); also elsewhere on the board
/A_{9}: P1.8 (A9); also elsewhere on the board
/A_{10}: P1.7 (A10); also elsewhere on the board
/A_{11}: P1.6 (A11); also elsewhere on the board
/A_{12}: P1.37 (A12); also elsewhere on the board
/A_{13}: P1.38 (A13), U8H.3 (A1); also elsewhere on the board
/A_{14}: P1.39 (A14), U8H.2 (A0); also elsewhere on the board
/A_{15}: P1.40 (A15), U8H.1 (E), U8L.2 (A0), U8L.3 (A1); also elsewhere on the board
/BA_{0}: P1.41 (BA0); also elsewhere on the board
/BA_{1}: P1.42 (BA1); also elsewhere on the board
/BA_{2}: P1.43 (BA2); also elsewhere on the board
/BA_{3}: P1.44 (BA3); also elsewhere on the board
/BA_{4}: P1.45 (BA4); also elsewhere on the board
/BA_{5}: P1.46 (BA5), U8H.14 (A0), U8L.14 (A0); also elsewhere on the board
/BA_{6}: P1.47 (BA6), U8H.13 (A1), U8L.13 (A1); also elsewhere on the board
/BA_{7}: P1.48 (BA7), SJ4.3 (B)
/CIC.CLK: P1.56 (CIC_{CLK}), U2A.2 (GP5), U2B.2 (GP5)
/CIC.D_{0}: P1.55 (CIC_{D0}), U2A.7 (GP0), U2B.7 (GP0)
/CIC.D_{1}: P1.24 (CIC_{D1}), U2A.6 (GP1), U2B.6 (GP1)
/CIC.RST: P1.25 (CIC_{RST}), U2A.5 (GP2), U2B.5 (GP2)
/D_{0}: P1.19 (D0), U6.4; also elsewhere on the board
/D_{1}: P1.20 (D1), U6.7; also elsewhere on the board
/D_{2}: P1.21 (D2), U6.9; also elsewhere on the board
/D_{3}: P1.22 (D3), U6.12; also elsewhere on the board
/D_{4}: P1.50 (D4), U7.4; also elsewhere on the board
/D_{5}: P1.51 (D5), U7.7; also elsewhere on the board
/D_{6}: P1.52 (D6), U7.9; also elsewhere on the board
/D_{7}: P1.53 (D7), U7.12; also elsewhere on the board
/MULTI: SJ5.3 (B), U10.5 (Q); also elsewhere on the board
/Q_{0}: U6.2; also elsewhere on the board
/Q_{1}: U6.5; also elsewhere on the board
/Q_{2}: U6.11; also elsewhere on the board
/Q_{3}: U6.14; also elsewhere on the board
/Q_{4}: U7.2; also elsewhere on the board
/Q_{5}: U7.5; also elsewhere on the board
/Q_{6}: U7.11; also elsewhere on the board
/Q_{7}: U7.14; also elsewhere on the board
/Q_{8}: U6.3; also elsewhere on the board
/Q_{9}: U6.6; also elsewhere on the board
/Q_{10}: U6.10; also elsewhere on the board
/Q_{11}: U6.13; also elsewhere on the board
/Q_{12}: U7.3; also elsewhere on the board
/Q_{13}: U7.6; also elsewhere on the board
/Q_{14}: U7.10; also elsewhere on the board
/Q_{15}: U7.13; also elsewhere on the board
/RAM.~CE: SJ3.2 (C); also elsewhere on the board
/RAM.~CE_{HI}: SJ3.3 (B), U8H.11 (O1)
/RAM.~CE_{LO}: SJ3.1 (A), U8L.9 (O3)
/ROM.~CE_{0}: U9.5 (O1); also elsewhere on the board
/ROM.~CE_{1}: U9.4 (O0); also elsewhere on the board
/~IRQ: P1.18 (~IRQ), U2A.4 (GP3), U2B.4 (GP3)
/~RD: P1.23 (~RD), U9.1 (E), U9.15 (E); also elsewhere on the board
/~RESET: P1.26 (~RESET), U10.3 (C); also elsewhere on the board
/~ROMSEL: P1.49 (~ROMSEL), SJ1.2 (B), SJ2.3 (B), U8L.1 (E)
/~ROMSEL_{LO}: SJ2.1 (A), U8L.7 (O3)
/~WR: P1.54 (~WR); also elsewhere on the board
GND: C1.2, C2.2, C6.2, C7.2, C8.2, C9.2, C10.2, P1.5 (GND), P1.36 (GND), U2A.8 (VSS), U2B.8 (VSS), U6.8 (GND), U7.8 (GND), U8H.8 (GND), U8L.8 (GND), U9.3 (A1), U9.8 (GND), U9.13 (A1), U10.7 (GND), U10.10 (~S); also elsewhere on the board
unnamed: SJ1.1 (A), SJ2.2 (C), U9.14 (A0)
unnamed: SJ4.1 (A), SJ5.2 (C)
unnamed: SJ4.2 (C), U9.2 (A0)
unnamed: U6.15 (~OE), U7.15 (~OE), U9.12 (O0)
unnamed: U8H.7 (O3), U8H.15 (E)
unnamed: U8L.4 (O0), U8L.15 (E)
unnamed: U10.2 (D), U10.6 (~Q)

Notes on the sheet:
SINGLE MULTI
HIROM LOROM
NO RAM
EX MODE NORMAL
LOROM HIROM

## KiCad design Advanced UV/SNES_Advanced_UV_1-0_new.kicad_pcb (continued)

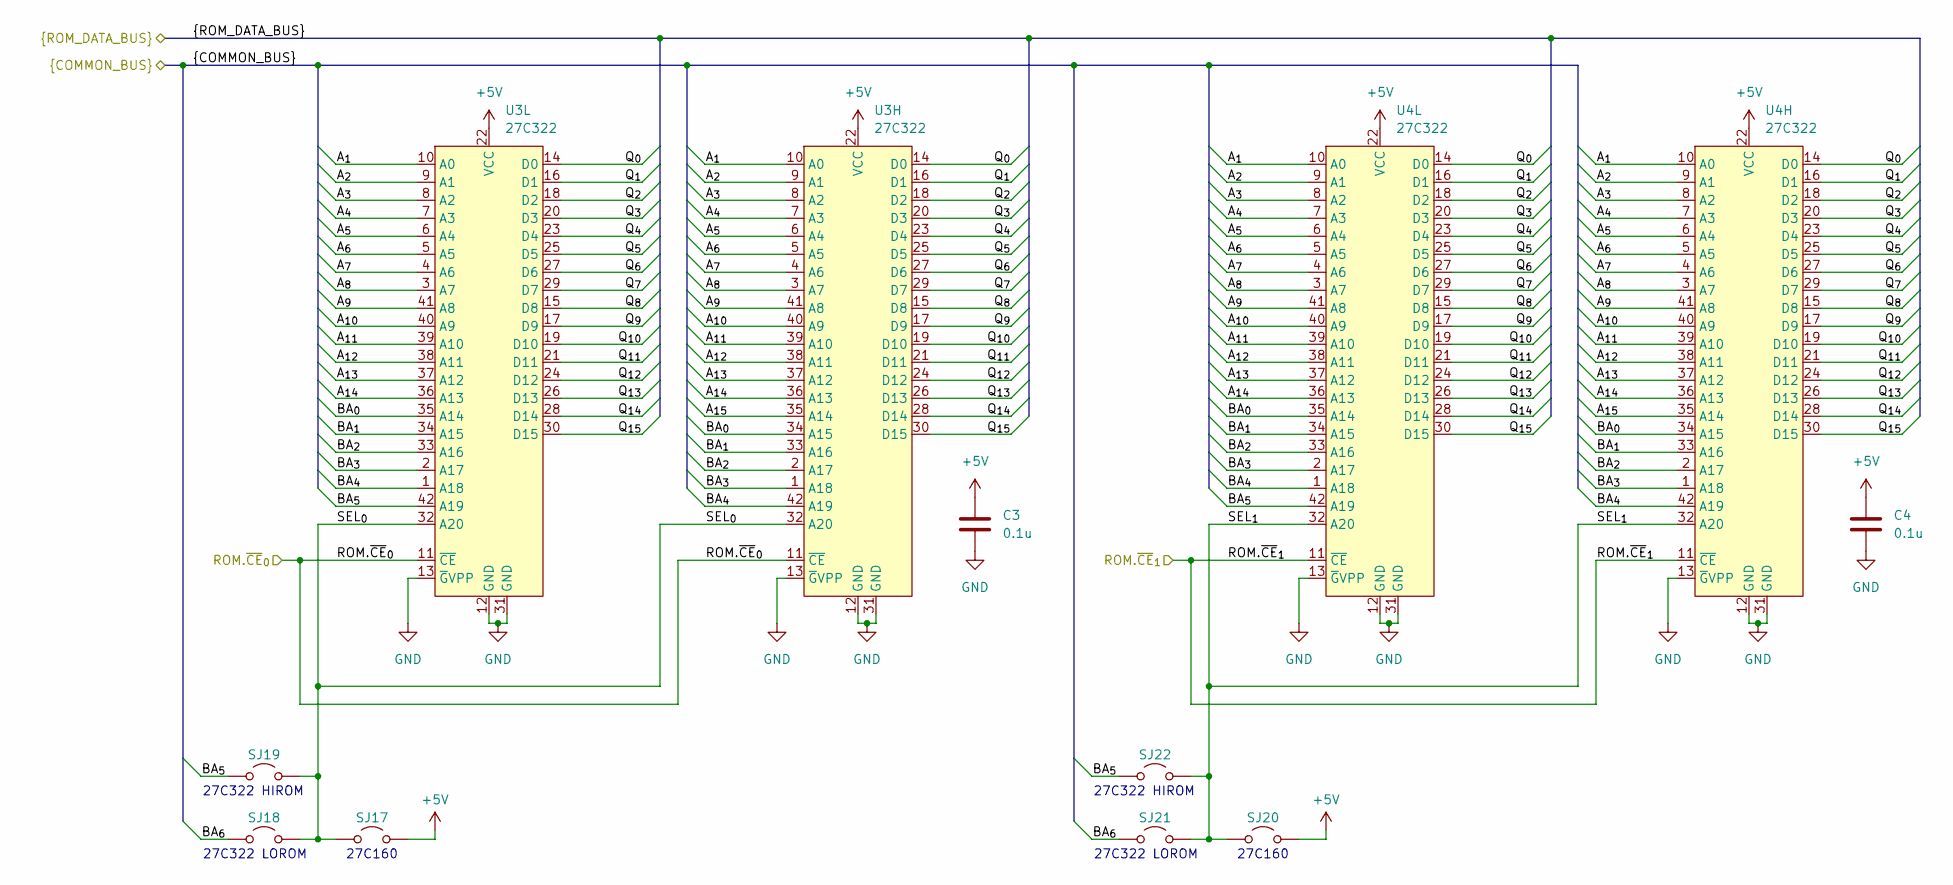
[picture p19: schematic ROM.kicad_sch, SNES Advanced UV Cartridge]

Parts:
C3, C4: 0.1u; C_THT
SJ17, SJ18, SJ19, SJ20, SJ21, SJ22: Jumper_2_Open; SJ
U3H, U3L, U4H, U4L: 27C322; DIP-42_W15.24mm

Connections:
+5V: C3.1, C4.1, SJ17.1 (A), SJ20.1 (A), U3H.22 (VCC), U3L.22 (VCC), U4H.22 (VCC), U4L.22 (VCC); also elsewhere on the board
/A_{1}: U3H.10 (A0), U3L.10 (A0), U4H.10 (A0), U4L.10 (A0); also elsewhere on the board
/A_{2}: U3H.9 (A1), U3L.9 (A1), U4H.9 (A1), U4L.9 (A1); also elsewhere on the board
/A_{3}: U3H.8 (A2), U3L.8 (A2), U4H.8 (A2), U4L.8 (A2); also elsewhere on the board
/A_{4}: U3H.7 (A3), U3L.7 (A3), U4H.7 (A3), U4L.7 (A3); also elsewhere on the board
/A_{5}: U3H.6 (A4), U3L.6 (A4), U4H.6 (A4), U4L.6 (A4); also elsewhere on the board
/A_{6}: U3H.5 (A5), U3L.5 (A5), U4H.5 (A5), U4L.5 (A5); also elsewhere on the board
/A_{7}: U3H.4 (A6), U3L.4 (A6), U4H.4 (A6), U4L.4 (A6); also elsewhere on the board
/A_{8}: U3H.3 (A7), U3L.3 (A7), U4H.3 (A7), U4L.3 (A7); also elsewhere on the board
/A_{9}: U3H.41 (A8), U3L.41 (A8), U4H.41 (A8), U4L.41 (A8); also elsewhere on the board
/A_{10}: U3H.40 (A9), U3L.40 (A9), U4H.40 (A9), U4L.40 (A9); also elsewhere on the board
/A_{11}: U3H.39 (A10), U3L.39 (A10), U4H.39 (A10), U4L.39 (A10); also elsewhere on the board
/A_{12}: U3H.38 (A11), U3L.38 (A11), U4H.38 (A11), U4L.38 (A11); also elsewhere on the board
/A_{13}: U3H.37 (A12), U3L.37 (A12), U4H.37 (A12), U4L.37 (A12); also elsewhere on the board
/A_{14}: U3H.36 (A13), U3L.36 (A13), U4H.36 (A13), U4L.36 (A13); also elsewhere on the board
/A_{15}: U3H.35 (A14), U4H.35 (A14); also elsewhere on the board
/BA_{0}: U3H.34 (A15), U3L.35 (A14), U4H.34 (A15), U4L.35 (A14); also elsewhere on the board
/BA_{1}: U3H.33 (A16), U3L.34 (A15), U4H.33 (A16), U4L.34 (A15); also elsewhere on the board
/BA_{2}: U3H.2 (A17), U3L.33 (A16), U4H.2 (A17), U4L.33 (A16); also elsewhere on the board
/BA_{3}: U3H.1 (A18), U3L.2 (A17), U4H.1 (A18), U4L.2 (A17); also elsewhere on the board
/BA_{4}: U3H.42 (A19), U3L.1 (A18), U4H.42 (A19), U4L.1 (A18); also elsewhere on the board
/BA_{5}: SJ19.2 (B), SJ22.2 (B), U3L.42 (A19), U4L.42 (A19); also elsewhere on the board
/BA_{6}: SJ18.1 (A), SJ21.1 (A); also elsewhere on the board
/Q_{0}: U3H.14 (D0), U3L.14 (D0), U4H.14 (D0), U4L.14 (D0); also elsewhere on the board
/Q_{1}: U3H.16 (D1), U3L.16 (D1), U4H.16 (D1), U4L.16 (D1); also elsewhere on the board
/Q_{2}: U3H.18 (D2), U3L.18 (D2), U4H.18 (D2), U4L.18 (D2); also elsewhere on the board
/Q_{3}: U3H.20 (D3), U3L.20 (D3), U4H.20 (D3), U4L.20 (D3); also elsewhere on the board
/Q_{4}: U3H.23 (D4), U3L.23 (D4), U4H.23 (D4), U4L.23 (D4); also elsewhere on the board
/Q_{5}: U3H.25 (D5), U3L.25 (D5), U4H.25 (D5), U4L.25 (D5); also elsewhere on the board
/Q_{6}: U3H.27 (D6), U3L.27 (D6), U4H.27 (D6), U4L.27 (D6); also elsewhere on the board
/Q_{7}: U3H.29 (D7), U3L.29 (D7), U4H.29 (D7), U4L.29 (D7); also elsewhere on the board
/Q_{8}: U3H.15 (D8), U3L.15 (D8), U4H.15 (D8), U4L.15 (D8); also elsewhere on the board
/Q_{9}: U3H.17 (D9), U3L.17 (D9), U4H.17 (D9), U4L.17 (D9); also elsewhere on the board
/Q_{10}: U3H.19 (D10), U3L.19 (D10), U4H.19 (D10), U4L.19 (D10); also elsewhere on the board
/Q_{11}: U3H.21 (D11), U3L.21 (D11), U4H.21 (D11), U4L.21 (D11); also elsewhere on the board
/Q_{12}: U3H.24 (D12), U3L.24 (D12), U4H.24 (D12), U4L.24 (D12); also elsewhere on the board
/Q_{13}: U3H.26 (D13), U3L.26 (D13), U4H.26 (D13), U4L.26 (D13); also elsewhere on the board
/Q_{14}: U3H.28 (D14), U3L.28 (D14), U4H.28 (D14), U4L.28 (D14); also elsewhere on the board
/Q_{15}: U3H.30 (D15), U3L.30 (D15), U4H.30 (D15), U4L.30 (D15); also elsewhere on the board
/ROM.~CE_{0}: U3H.11 (~CE), U3L.11 (~CE); also elsewhere on the board
/ROM.~CE_{1}: U4H.11 (~CE), U4L.11 (~CE); also elsewhere on the board
/ROM/SEL_{0}: SJ17.2 (B), SJ18.2 (B), SJ19.1 (A), U3H.32 (A20), U3L.32 (A20)
/ROM/SEL_{1}: SJ20.2 (B), SJ21.2 (B), SJ22.1 (A), U4H.32 (A20), U4L.32 (A20)
GND: C3.2, C4.2, U3H.12 (GND), U3H.13 (~GVPP), U3H.31 (GND), U3L.12 (GND), U3L.13 (~GVPP), U3L.31 (GND), U4H.12 (GND), U4H.13 (~GVPP), U4H.31 (GND), U4L.12 (GND), U4L.13 (~GVPP), U4L.31 (GND); also elsewhere on the board

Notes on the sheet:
27C160
27C322 LOROM
27C322 HIROM

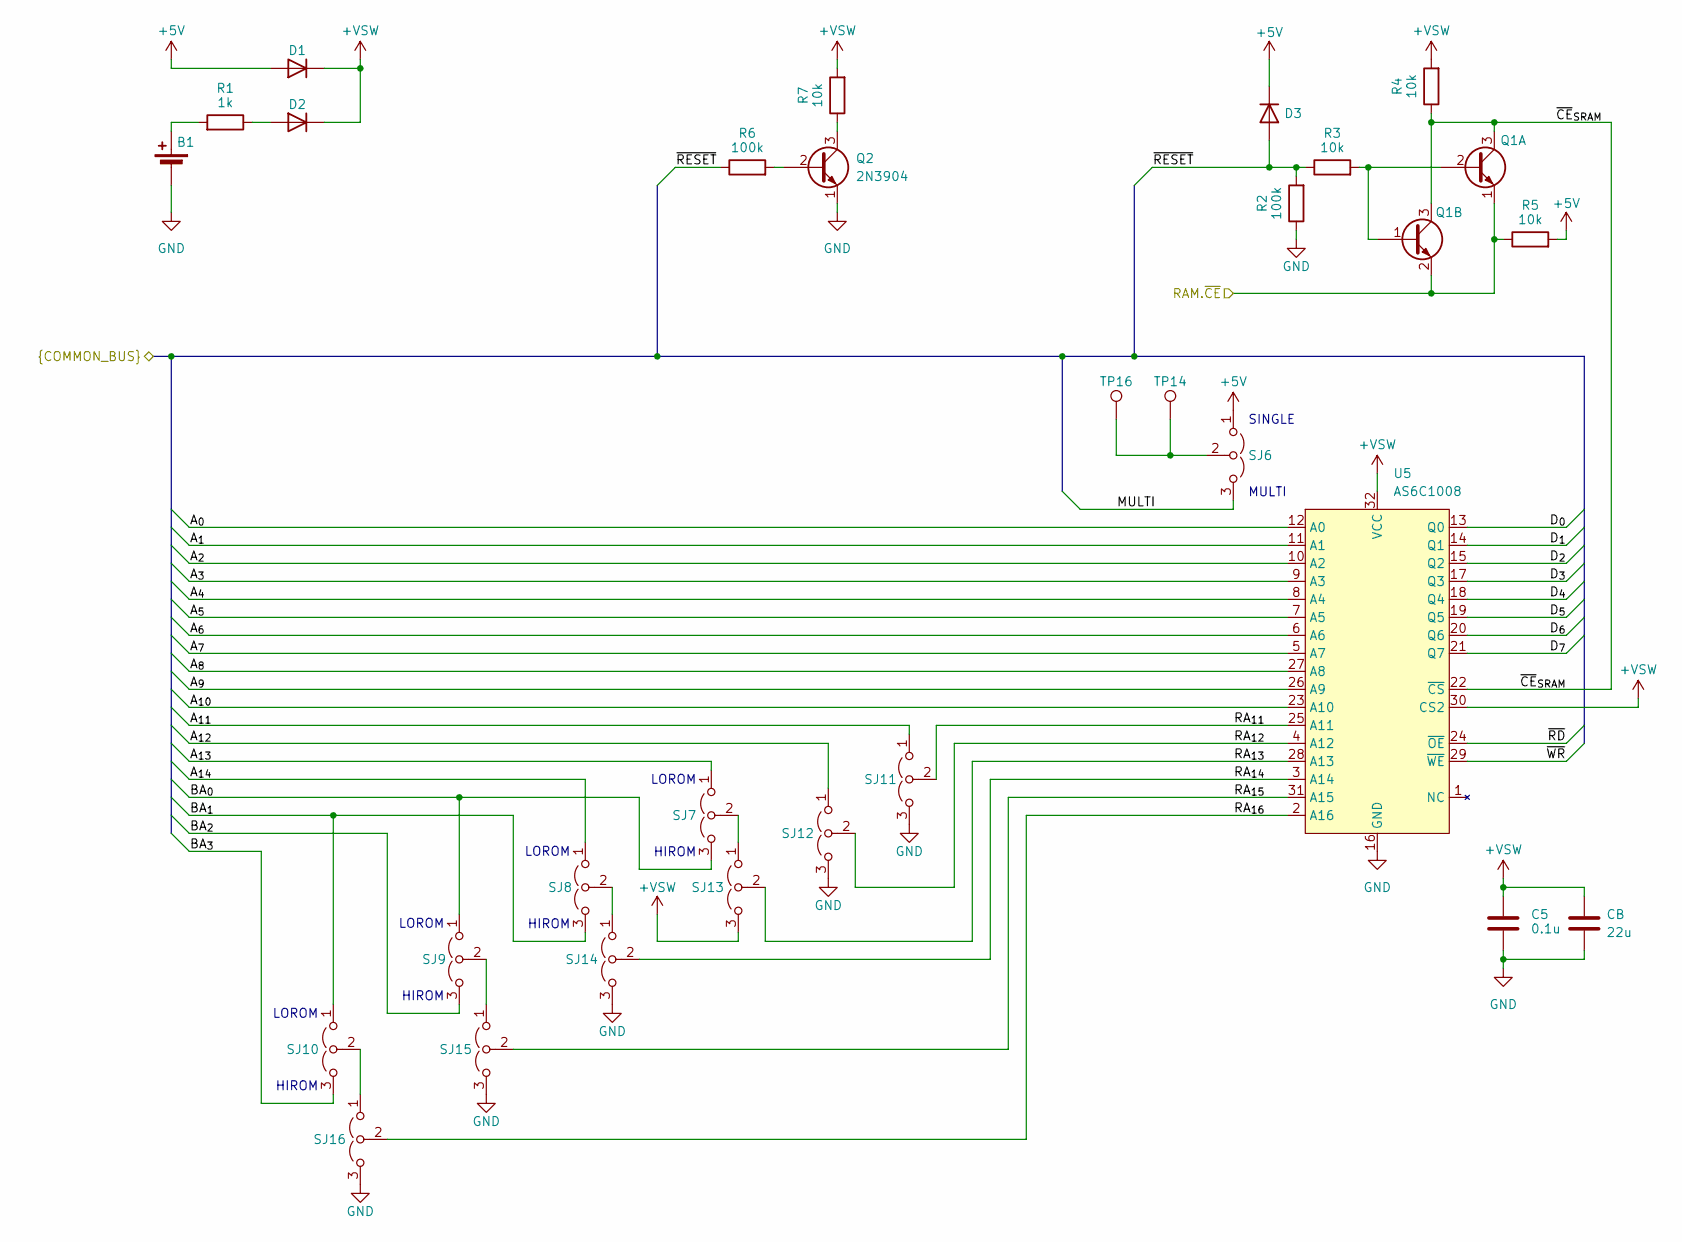
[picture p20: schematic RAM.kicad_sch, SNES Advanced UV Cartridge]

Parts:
B1: CR2025; COIN_CELL
C5: 0.1u; C_THT
CB: 22u; CP_Radial_D5.0mm_P2.50mm
D1, D2, D3: D; DIODE_THT_SMT
Q1A, Q2: 2N3904; TO-92L_Inline_Wide
Q1B: MMBT3904; SOT-23
R1: 1k; THT_SMT_0803
R2, R6: 100k; THT_SMT_0803
R3, R4, R5, R7: 10k; THT_SMT_0803
SJ6, SJ7, SJ8, SJ9, SJ10, SJ11, SJ12, SJ13, SJ14, SJ15, SJ16: Jumper_3_Open; SJ_2
TP14, TP16: TPB1,27; TestPoint_THTPad_D1.5mm_Drill0.7mm
U5: AS6C1008; DIP-32_W15.24mm

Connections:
+5V: D1.2 (A), D3.1 (K), R5.2, SJ6.1 (A); also elsewhere on the board
+VSW: C5.1, CB.1, D1.1 (K), D2.1 (K), R4.2, R7.2, SJ13.3 (B), U5.30 (CS2), U5.32 (VCC)
/A_{0}: U5.12 (A0); also elsewhere on the board
/A_{1}: U5.11 (A1); also elsewhere on the board
/A_{2}: U5.10 (A2); also elsewhere on the board
/A_{3}: U5.9 (A3); also elsewhere on the board
/A_{4}: U5.8 (A4); also elsewhere on the board
/A_{5}: U5.7 (A5); also elsewhere on the board
/A_{6}: U5.6 (A6); also elsewhere on the board
/A_{7}: U5.5 (A7); also elsewhere on the board
/A_{8}: U5.27 (A8); also elsewhere on the board
/A_{9}: U5.26 (A9); also elsewhere on the board
/A_{10}: U5.23 (A10); also elsewhere on the board
/A_{11}: SJ11.1 (A); also elsewhere on the board
/A_{12}: SJ12.1 (A); also elsewhere on the board
/A_{13}: SJ7.1 (A); also elsewhere on the board
/A_{14}: SJ8.1 (A); also elsewhere on the board
/BA_{0}: SJ7.3 (B), SJ9.1 (A); also elsewhere on the board
/BA_{1}: SJ8.3 (B), SJ10.1 (A); also elsewhere on the board
/BA_{2}: SJ9.3 (B); also elsewhere on the board
/BA_{3}: SJ10.3 (B); also elsewhere on the board
/D_{0}: U5.13 (Q0); also elsewhere on the board
/D_{1}: U5.14 (Q1); also elsewhere on the board
/D_{2}: U5.15 (Q2); also elsewhere on the board
/D_{3}: U5.17 (Q3); also elsewhere on the board
/D_{4}: U5.18 (Q4); also elsewhere on the board
/D_{5}: U5.19 (Q5); also elsewhere on the board
/D_{6}: U5.20 (Q6); also elsewhere on the board
/D_{7}: U5.21 (Q7); also elsewhere on the board
/MULTI: SJ6.3 (B); also elsewhere on the board
/RAM.~CE: Q1A.1 (E), Q1B.2 (E), R5.1; also elsewhere on the board
/RAM/RA_{11}: SJ11.2 (C), U5.25 (A11)
/RAM/RA_{12}: SJ12.2 (C), U5.4 (A12)
/RAM/RA_{13}: SJ13.2 (C), U5.28 (A13)
/RAM/RA_{14}: SJ14.2 (C), U5.3 (A14)
/RAM/RA_{15}: SJ15.2 (C), U5.31 (A15)
/RAM/RA_{16}: SJ16.2 (C), U5.2 (A16)
/RAM/~CE_{SRAM}: Q1A.3 (C), Q1B.3 (C), R4.1, U5.22 (~CS)
/~RD: U5.24 (~OE); also elsewhere on the board
/~RESET: D3.2 (A), R2.2, R3.1, R6.1; also elsewhere on the board
/~WR: U5.29 (~WE); also elsewhere on the board
GND: B1.2 (-), C5.2, CB.2, Q2.1 (E), R2.1, SJ11.3 (B), SJ12.3 (B), SJ14.3 (B), SJ15.3 (B), SJ16.3 (B), U5.16 (GND); also elsewhere on the board
unnamed: B1.1 (+), R1.2
unnamed: D2.2 (A), R1.1
unnamed: Q1A.2 (B), Q1B.1 (B), R3.2
unnamed: Q2.2 (B), R6.2
unnamed: Q2.3 (C), R7.1
unnamed: SJ6.2 (C), TP14.1, TP16.1
unnamed: SJ10.2 (C), SJ16.1 (A)
unnamed: SJ7.2 (C), SJ13.1 (A)
unnamed: SJ8.2 (C), SJ14.1 (A)
unnamed: SJ9.2 (C), SJ15.1 (A)

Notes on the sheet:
SINGLE MULTI
LOROM HIROM

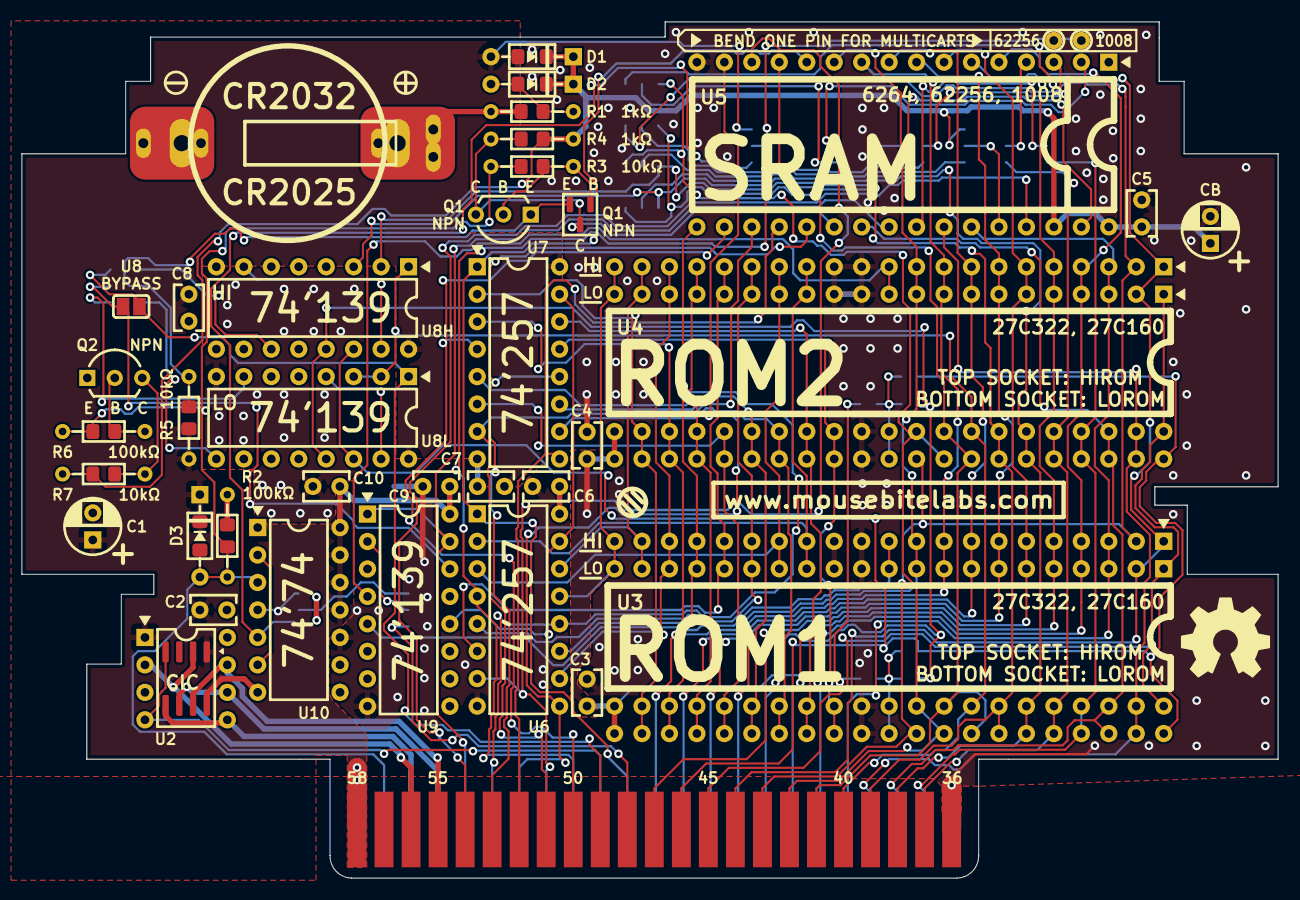
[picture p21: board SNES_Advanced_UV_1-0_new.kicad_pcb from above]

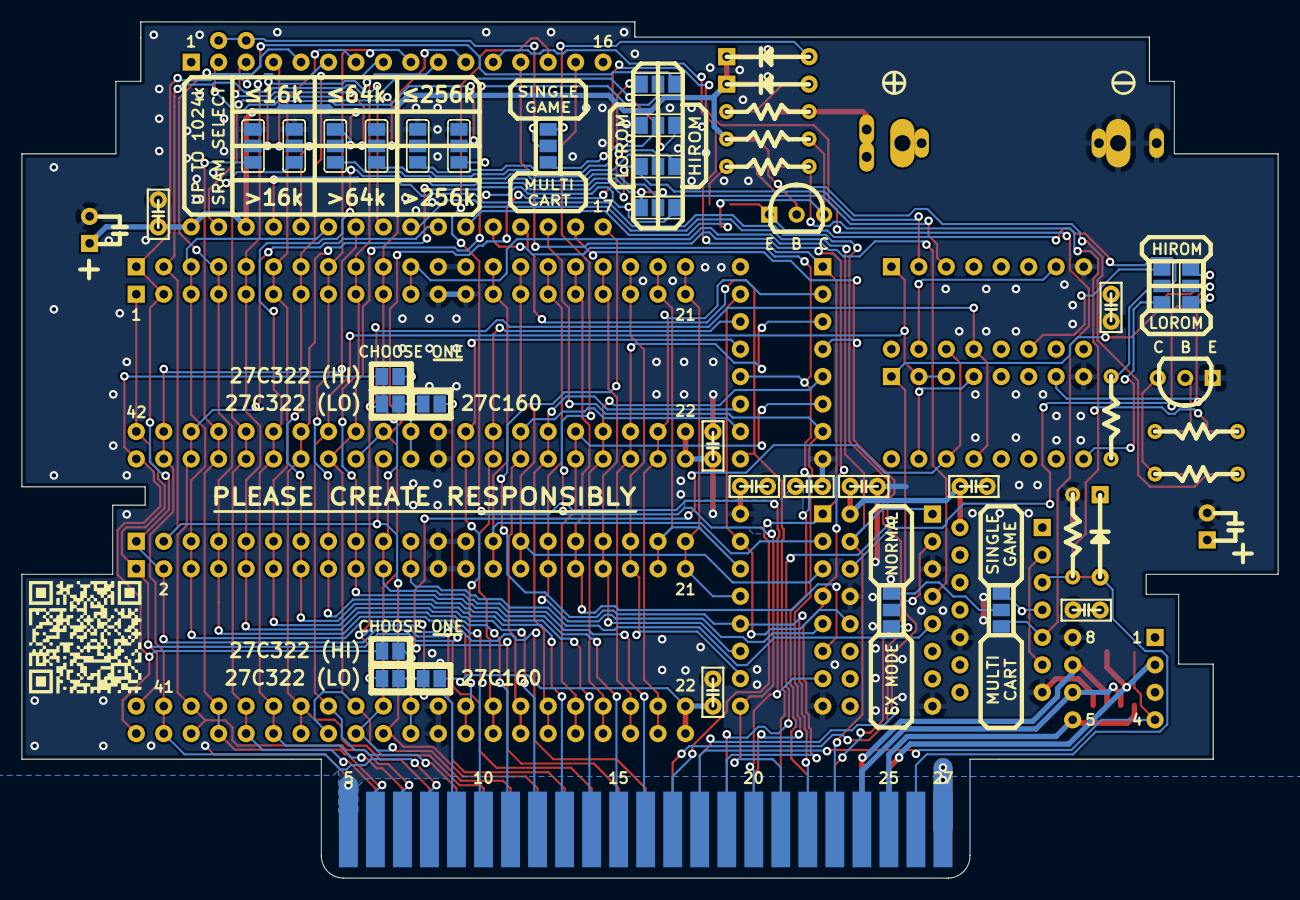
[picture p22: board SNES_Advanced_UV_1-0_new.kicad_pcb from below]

Board: 2 copper layers, 116.2 x 79.2 mm, 63 parts (21 on the bottom side), 93 nets.

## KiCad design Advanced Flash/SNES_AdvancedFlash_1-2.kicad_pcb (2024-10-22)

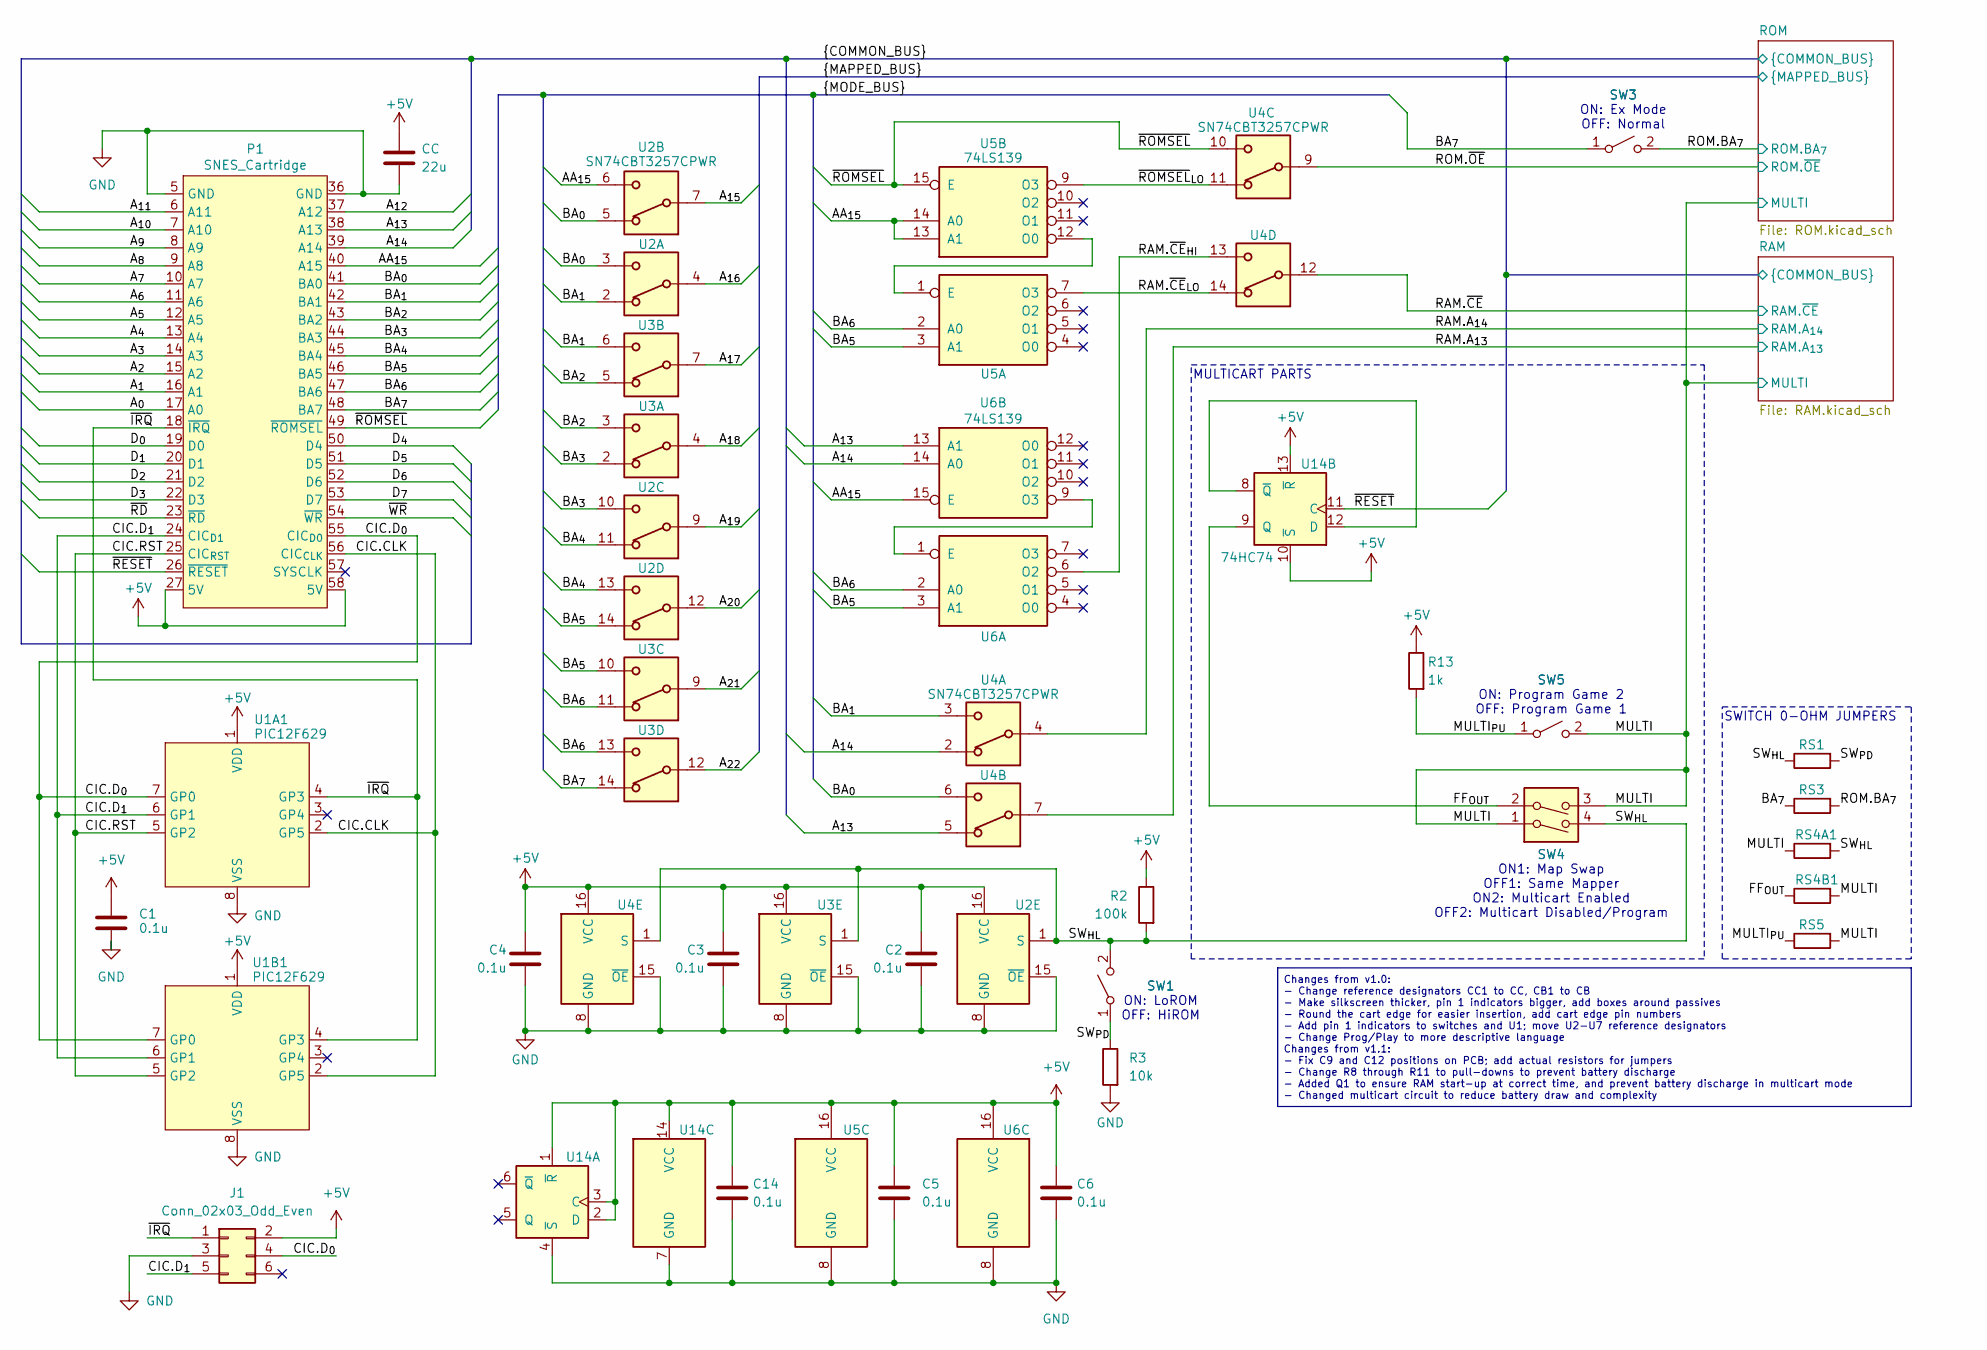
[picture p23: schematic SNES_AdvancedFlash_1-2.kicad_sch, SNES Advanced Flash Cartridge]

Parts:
C1, C2, C3, C4, C5, C6, C14: 0.1u; C_0603_1608Metric_Boxed
CC: 22u; C_1206_3216Metric_Boxed
J1: Conn_02x03_Odd_Even; PinHeader_2x03_P2.54mm_Vertical
P1: SNES_Cartridge; Cart_Edge_SNES_Standard
R2: 100k; R_0603_1608Metric_Boxed
R3: 10k; R_0603_1608Metric_Boxed
R13: 1k; R_0603_1608Metric_Boxed
RS1, RS3, RS4A1, RS4B1, RS5: 0; R_0603_1608Metric_NoSilk
SW1, SW3, SW5: SW_SPST; SPST_SMT
SW4: SW_DIP_x02; SPSTx2_SMT
U1A1: PIC12F629; SOIC-8W_5.3x5.3mm_P1.27mm
U1B1: PIC12F629; DIP-8_W7.62mm
U2, U3, U4: SN74CBT3257CPWR; TSSOP-16_4.4x5mm_P0.65mm
U5, U6: 74LS139; TSSOP-16_4.4x5mm_P0.65mm
U14: 74HC74; TSSOP-14_4.4x5mm_P0.65mm

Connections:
+5V: C1.1, C2.1, C3.1, C4.1, C5.1, C6.1, C14.1, CC.1, J1.2, P1.27 (5V), P1.58 (5V), R2.1, R13.1, U1A1.1 (VDD), U1B1.1 (VDD), U2.16 (VCC), U3.16 (VCC), U4.16 (VCC), U5.16 (VCC), U6.16 (VCC), U14.1 (~R), U14.2 (D), U14.3 (C), U14.10 (~S), U14.13 (~R), U14.14 (VCC); also elsewhere on the board
/AA_{15}: P1.40 (A15), U2.6, U5.13 (A1), U5.14 (A0), U6.15 (E)
/A_{0}: P1.17 (A0); also elsewhere on the board
/A_{1}: P1.16 (A1); also elsewhere on the board
/A_{2}: P1.15 (A2); also elsewhere on the board
/A_{3}: P1.14 (A3); also elsewhere on the board
/A_{4}: P1.13 (A4); also elsewhere on the board
/A_{5}: P1.12 (A5); also elsewhere on the board
/A_{6}: P1.11 (A6); also elsewhere on the board
/A_{7}: P1.10 (A7); also elsewhere on the board
/A_{8}: P1.9 (A8); also elsewhere on the board
/A_{9}: P1.8 (A9); also elsewhere on the board
/A_{10}: P1.7 (A10); also elsewhere on the board
/A_{11}: P1.6 (A11); also elsewhere on the board
/A_{12}: P1.37 (A12); also elsewhere on the board
/A_{13}: P1.38 (A13), U4.5, U6.13 (A1); also elsewhere on the board
/A_{14}: P1.39 (A14), U4.2, U6.14 (A0); also elsewhere on the board
/A_{15}: U2.7; also elsewhere on the board
/A_{16}: U2.4; also elsewhere on the board
/A_{17}: U3.7; also elsewhere on the board
/A_{18}: U3.4; also elsewhere on the board
/A_{19}: U2.9; also elsewhere on the board
/A_{20}: U2.12; also elsewhere on the board
/A_{21}: U3.9; also elsewhere on the board
/A_{22}: U3.12
/BA_{0}: P1.41 (BA0), U2.3, U2.5, U4.6
/BA_{1}: P1.42 (BA1), U2.2, U3.6, U4.3
/BA_{2}: P1.43 (BA2), U3.3, U3.5
/BA_{3}: P1.44 (BA3), U2.10, U3.2
/BA_{4}: P1.45 (BA4), U2.11, U2.13
/BA_{5}: P1.46 (BA5), U2.14, U3.10, U5.3 (A1), U6.3 (A1)
/BA_{6}: P1.47 (BA6), U3.11, U3.13, U5.2 (A0), U6.2 (A0)
/BA_{7}: P1.48 (BA7), RS3.1, SW3.1 (A), U3.14
/CIC.CLK: P1.56 (CIC_{CLK}), U1A1.2 (GP5), U1B1.2 (GP5)
/CIC.D_{0}: J1.4, P1.55 (CIC_{D0}), U1A1.7 (GP0), U1B1.7 (GP0)
/CIC.D_{1}: J1.5, P1.24 (CIC_{D1}), U1A1.6 (GP1), U1B1.6 (GP1)
/CIC.RST: P1.25 (CIC_{RST}), U1A1.5 (GP2), U1B1.5 (GP2)
/D_{0}: P1.19 (D0); also elsewhere on the board
/D_{1}: P1.20 (D1); also elsewhere on the board
/D_{2}: P1.21 (D2); also elsewhere on the board
/D_{3}: P1.22 (D3); also elsewhere on the board
/D_{4}: P1.50 (D4); also elsewhere on the board
/D_{5}: P1.51 (D5); also elsewhere on the board
/D_{6}: P1.52 (D6); also elsewhere on the board
/D_{7}: P1.53 (D7); also elsewhere on the board
/FF_{OUT}: RS4B1.1, SW4.2, U14.9 (Q)
/MULTI: RS4A1.1, RS4B1.2, RS5.2, SW4.1, SW4.3, SW5.2 (B); also elsewhere on the board
/MULTI_{PU}: R13.2, RS5.1, SW5.1 (A)
/RAM.A_{13}: U4.7; also elsewhere on the board
/RAM.A_{14}: U4.4; also elsewhere on the board
/RAM.~CE: U4.12; also elsewhere on the board
/RAM.~CE_{HI}: U4.13, U6.6 (O2)
/RAM.~CE_{LO}: U4.14, U5.7 (O3)
/ROM.BA_{7}: RS3.2, SW3.2 (B); also elsewhere on the board
/ROM.~OE: U4.9; also elsewhere on the board
/SW_{HL}: R2.2, RS1.1, RS4A1.2, SW1.2 (B), SW4.4, U2.1 (S), U3.1 (S), U4.1 (S)
/SW_{PD}: R3.1, RS1.2, SW1.1 (A)
/~IRQ: J1.1, P1.18 (~IRQ), U1A1.4 (GP3), U1B1.4 (GP3)
/~RD: P1.23 (~RD); also elsewhere on the board
/~RESET: P1.26 (~RESET), U14.11 (C); also elsewhere on the board
/~ROMSEL: P1.49 (~ROMSEL), U4.10, U5.15 (E)
/~ROMSEL_{LO}: U4.11, U5.9 (O3)
/~WR: P1.54 (~WR); also elsewhere on the board
GND: C1.2, C2.2, C3.2, C4.2, C5.2, C6.2, C14.2, CC.2, J1.3, P1.5 (GND), P1.36 (GND), R3.2, U1A1.8 (VSS), U1B1.8 (VSS), U2.8 (GND), U2.15 (~OE), U3.8 (GND), U3.15 (~OE), U4.8 (GND), U4.15 (~OE), U5.8 (GND), U6.8 (GND), U14.4 (~S), U14.7 (GND); also elsewhere on the board
unnamed: U5.1 (E), U5.12 (O0)
unnamed: U6.1 (E), U6.9 (O3)
unnamed: U14.8 (~Q), U14.12 (D)

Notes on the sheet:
SW1 ON: LoROM OFF: HiROM
SWITCH 0-OHM JUMPERS
Changes from v1.0: - Change reference designators CC1 to CC, CB1 to CB - Make silkscreen thicker, pin 1 indicators bigger, add boxes around passives - Round the cart edge for easier insertion, add cart edge pin numbers - Add pin 1 indicators to switches and U1; move U2-U7 reference designators - Ch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
SW3 ON: Ex Mode OFF: Normal
SW5 ON: Program Game 2 OFF: Program Game 1
MULTICART PARTS
SW4 ON1: Map Swap OFF1: Same Mapper ON2: Multicart Enabled OFF2: Multicart Disabled/Program

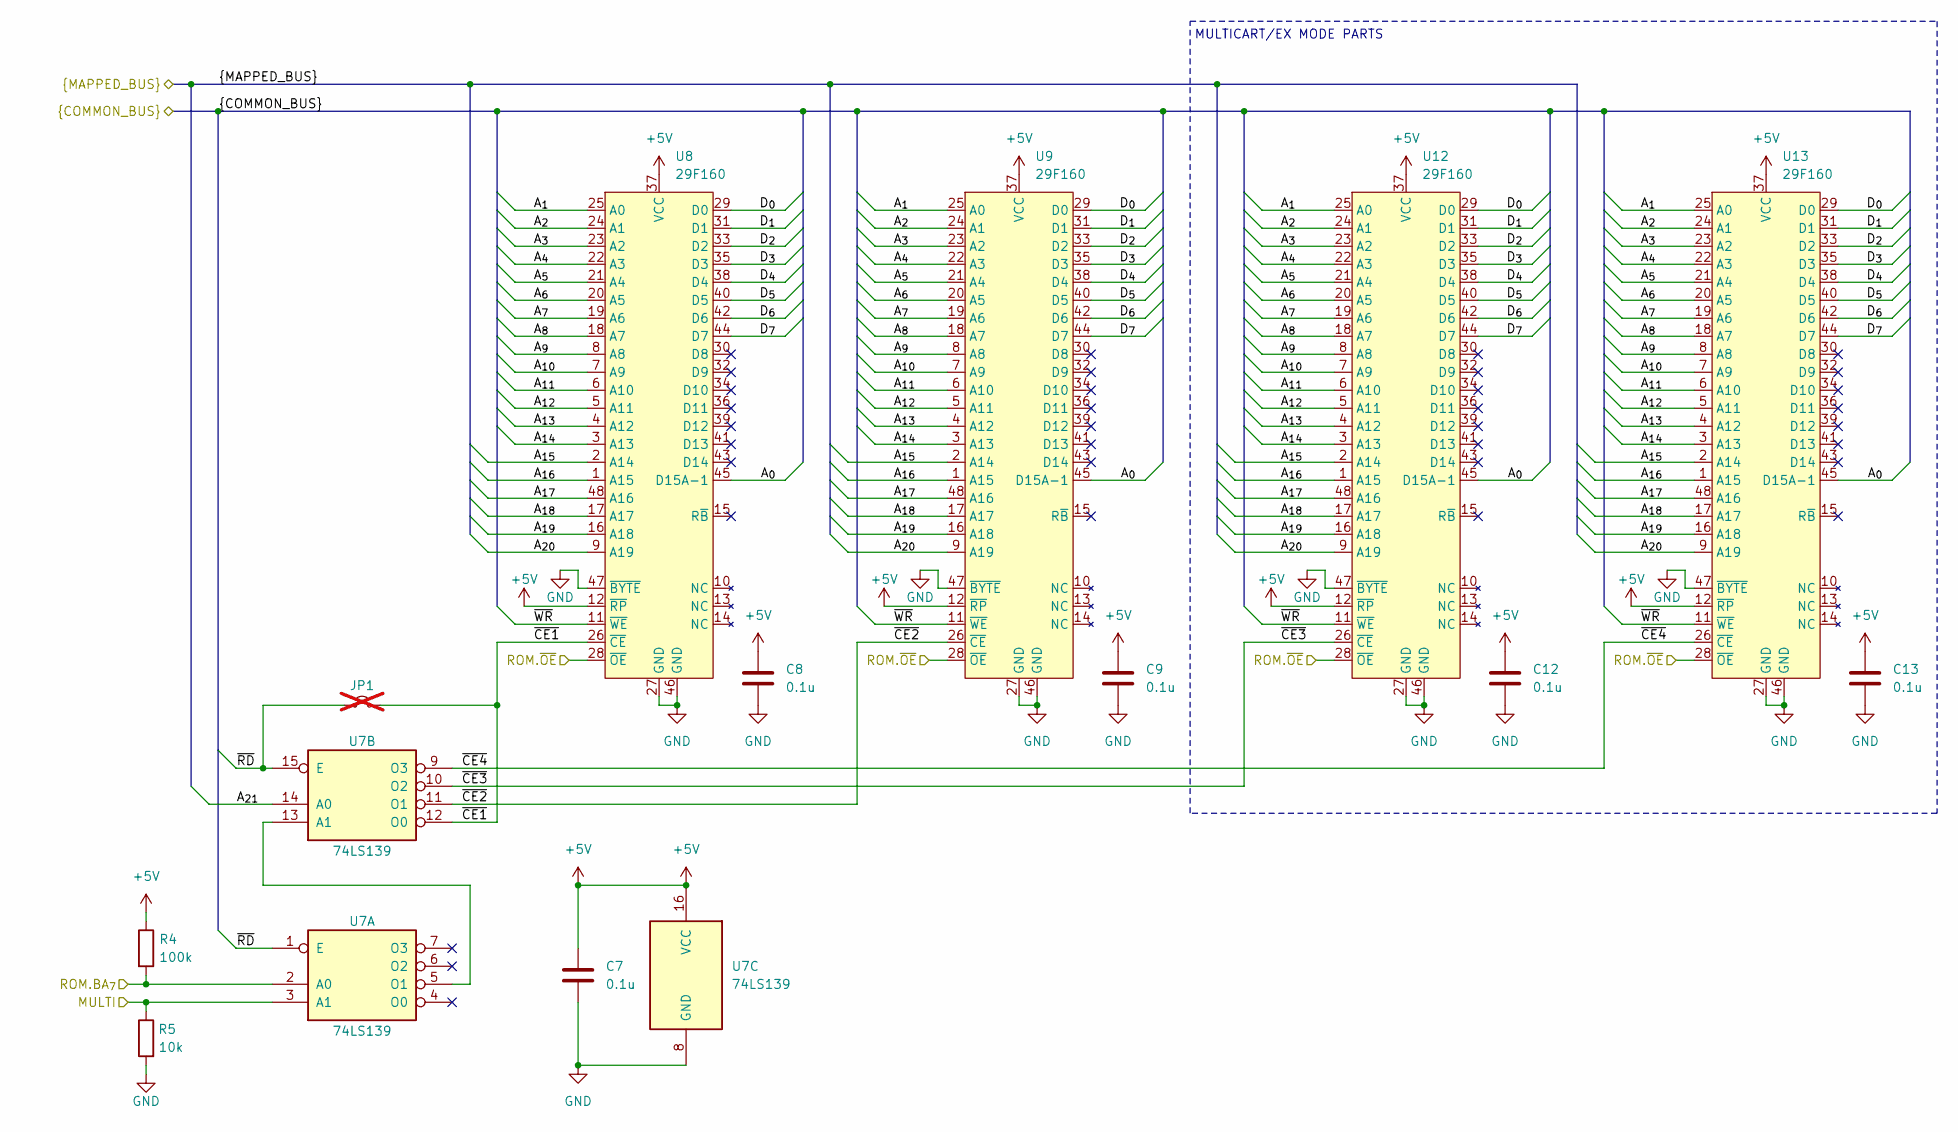
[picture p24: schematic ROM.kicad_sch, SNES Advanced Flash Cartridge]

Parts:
C7, C8, C9, C12, C13: 0.1u; C_0603_1608Metric_Boxed
JP1: Jumper_2_Small_Open; SolderJumper-2_P1.3mm_Open_Pad1.0x1.5mm; not fitted
R4: 100k; R_0603_1608Metric_Boxed
R5: 10k; R_0603_1608Metric_Boxed
U7: 74LS139; TSSOP-16_4.4x5mm_P0.65mm
U8, U9, U12, U13: 29F160; TSOP-I-48_18.4x12mm_P0.5mm

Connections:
+5V: C7.1, C8.1, C9.1, C12.1, C13.1, R4.1, U7.16 (VCC), U8.12 (~RP), U8.37 (VCC), U9.12 (~RP), U9.37 (VCC), U12.12 (~RP), U12.37 (VCC), U13.12 (~RP), U13.37 (VCC); also elsewhere on the board
/A_{0}: U8.45 (D15A-1), U9.45 (D15A-1), U12.45 (D15A-1), U13.45 (D15A-1); also elsewhere on the board
/A_{1}: U8.25 (A0), U9.25 (A0), U12.25 (A0), U13.25 (A0); also elsewhere on the board
/A_{2}: U8.24 (A1), U9.24 (A1), U12.24 (A1), U13.24 (A1); also elsewhere on the board
/A_{3}: U8.23 (A2), U9.23 (A2), U12.23 (A2), U13.23 (A2); also elsewhere on the board
/A_{4}: U8.22 (A3), U9.22 (A3), U12.22 (A3), U13.22 (A3); also elsewhere on the board
/A_{5}: U8.21 (A4), U9.21 (A4), U12.21 (A4), U13.21 (A4); also elsewhere on the board
/A_{6}: U8.20 (A5), U9.20 (A5), U12.20 (A5), U13.20 (A5); also elsewhere on the board
/A_{7}: U8.19 (A6), U9.19 (A6), U12.19 (A6), U13.19 (A6); also elsewhere on the board
/A_{8}: U8.18 (A7), U9.18 (A7), U12.18 (A7), U13.18 (A7); also elsewhere on the board
/A_{9}: U8.8 (A8), U9.8 (A8), U12.8 (A8), U13.8 (A8); also elsewhere on the board
/A_{10}: U8.7 (A9), U9.7 (A9), U12.7 (A9), U13.7 (A9); also elsewhere on the board
/A_{11}: U8.6 (A10), U9.6 (A10), U12.6 (A10), U13.6 (A10); also elsewhere on the board
/A_{12}: U8.5 (A11), U9.5 (A11), U12.5 (A11), U13.5 (A11); also elsewhere on the board
/A_{13}: U8.4 (A12), U9.4 (A12), U12.4 (A12), U13.4 (A12); also elsewhere on the board
/A_{14}: U8.3 (A13), U9.3 (A13), U12.3 (A13), U13.3 (A13); also elsewhere on the board
/A_{15}: U8.2 (A14), U9.2 (A14), U12.2 (A14), U13.2 (A14); also elsewhere on the board
/A_{16}: U8.1 (A15), U9.1 (A15), U12.1 (A15), U13.1 (A15); also elsewhere on the board
/A_{17}: U8.48 (A16), U9.48 (A16), U12.48 (A16), U13.48 (A16); also elsewhere on the board
/A_{18}: U8.17 (A17), U9.17 (A17), U12.17 (A17), U13.17 (A17); also elsewhere on the board
/A_{19}: U8.16 (A18), U9.16 (A18), U12.16 (A18), U13.16 (A18); also elsewhere on the board
/A_{20}: U8.9 (A19), U9.9 (A19), U12.9 (A19), U13.9 (A19); also elsewhere on the board
/A_{21}: U7.14 (A0); also elsewhere on the board
/D_{0}: U8.29 (D0), U9.29 (D0), U12.29 (D0), U13.29 (D0); also elsewhere on the board
/D_{1}: U8.31 (D1), U9.31 (D1), U12.31 (D1), U13.31 (D1); also elsewhere on the board
/D_{2}: U8.33 (D2), U9.33 (D2), U12.33 (D2), U13.33 (D2); also elsewhere on the board
/D_{3}: U8.35 (D3), U9.35 (D3), U12.35 (D3), U13.35 (D3); also elsewhere on the board
/D_{4}: U8.38 (D4), U9.38 (D4), U12.38 (D4), U13.38 (D4); also elsewhere on the board
/D_{5}: U8.40 (D5), U9.40 (D5), U12.40 (D5), U13.40 (D5); also elsewhere on the board
/D_{6}: U8.42 (D6), U9.42 (D6), U12.42 (D6), U13.42 (D6); also elsewhere on the board
/D_{7}: U8.44 (D7), U9.44 (D7), U12.44 (D7), U13.44 (D7); also elsewhere on the board
/MULTI: R5.1, U7.3 (A1); also elsewhere on the board
/ROM.BA_{7}: R4.2, U7.2 (A0); also elsewhere on the board
/ROM.~OE: U8.28 (~OE), U9.28 (~OE), U12.28 (~OE), U13.28 (~OE); also elsewhere on the board
/ROM/~CE1: JP1.2 (B), U7.12 (O0), U8.26 (~CE)
/ROM/~CE2: U7.11 (O1), U9.26 (~CE)
/ROM/~CE3: U7.10 (O2), U12.26 (~CE)
/ROM/~CE4: U7.9 (O3), U13.26 (~CE)
/~RD: JP1.1 (A), U7.1 (E), U7.15 (E); also elsewhere on the board
/~WR: U8.11 (~WE), U9.11 (~WE), U12.11 (~WE), U13.11 (~WE); also elsewhere on the board
GND: C7.2, C8.2, C9.2, C12.2, C13.2, R5.2, U7.8 (GND), U8.27 (GND), U8.46 (GND), U8.47 (~BYTE), U9.27 (GND), U9.46 (GND), U9.47 (~BYTE), U12.27 (GND), U12.46 (GND), U12.47 (~BYTE), U13.27 (GND), U13.46 (GND), U13.47 (~BYTE); also elsewhere on the board
unnamed: U7.5 (O1), U7.13 (A1)

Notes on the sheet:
MULTICART/EX MODE PARTS

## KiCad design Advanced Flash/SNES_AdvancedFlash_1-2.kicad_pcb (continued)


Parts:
B1: Battery_Cell; CR_battery
C10, C11: 0.1u; C_0603_1608Metric_Boxed
CB: 22u; C_1206_3216Metric_Boxed
Q1: 2N7002; SOT-23
R1: 10k; R_0603_1608Metric_Boxed
R6: 130k; R_0603_1608Metric_Boxed
R7: 49.9k; R_0603_1608Metric_Boxed
R8, R9, R10, R11: 100k; R_0603_1608Metric_Boxed
RS2A1, RS2B1, RS2C1, RS2D1: 0; R_0603_1608Metric_NoSilk
SW2: SW_DIP_x04; SPSTx4_SMT
TP1, TP2, TP3, TP4, TP5, TP6: TestPoint; TestPoint_Pad_D1.0mm
U10: AS6C1008; SO32L_L
U11: TPS3613; MSOP-10_3x3mm_P0.5mm

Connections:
+5V: C11.1, R6.1, U11.2 (VDD); also elsewhere on the board
+BATT: R1.2, TP2.1, TP4.1, U11.10 (VBAT)
+VSW: C10.1, CB.1, U10.30 (CS2), U10.32 (VCC), U11.1 (VOUT)
/A_{0}: U10.12 (A0); also elsewhere on the board
/A_{1}: U10.11 (A1); also elsewhere on the board
/A_{2}: U10.10 (A2); also elsewhere on the board
/A_{3}: U10.9 (A3); also elsewhere on the board
/A_{4}: U10.8 (A4); also elsewhere on the board
/A_{5}: U10.7 (A5); also elsewhere on the board
/A_{6}: U10.6 (A6); also elsewhere on the board
/A_{7}: U10.5 (A7); also elsewhere on the board
/A_{8}: U10.27 (A8); also elsewhere on the board
/A_{9}: U10.26 (A9); also elsewhere on the board
/A_{10}: U10.23 (A10); also elsewhere on the board
/A_{11}: RS2A1.1, SW2.1; also elsewhere on the board
/A_{12}: RS2B1.1, SW2.2; also elsewhere on the board
/D_{0}: U10.13 (Q0); also elsewhere on the board
/D_{1}: U10.14 (Q1); also elsewhere on the board
/D_{2}: U10.15 (Q2); also elsewhere on the board
/D_{3}: U10.17 (Q3); also elsewhere on the board
/D_{4}: U10.18 (Q4); also elsewhere on the board
/D_{5}: U10.19 (Q5); also elsewhere on the board
/D_{6}: U10.20 (Q6); also elsewhere on the board
/D_{7}: U10.21 (Q7); also elsewhere on the board
/MULTI: U10.2 (A16), U10.31 (A15); also elsewhere on the board
/RAM.A_{13}: RS2C1.1, SW2.3; also elsewhere on the board
/RAM.A_{14}: RS2D1.1, SW2.4; also elsewhere on the board
/RAM.~CE: U11.5 (~CEIN); also elsewhere on the board
/RAM/A_{11SW}: R8.2, RS2A1.2, SW2.8, U10.25 (A11)
/RAM/A_{12SW}: R9.2, RS2B1.2, SW2.7, U10.4 (A12)
/RAM/A_{13SW}: R10.2, RS2C1.2, SW2.6, U10.28 (A13)
/RAM/A_{14SW}: R11.2, RS2D1.2, SW2.5, U10.3 (A14)
/RAM/RAM.~CE_{G}: U10.22 (~CS), U11.6 (~CEOUT)
/~RD: U10.24 (~OE); also elsewhere on the board
/~RESET: Q1.3 (D); also elsewhere on the board
/~WR: U10.29 (~WE); also elsewhere on the board
GND: B1.2 (-), C10.2, C11.2, CB.2, Q1.2 (S), R7.2, R8.1, R9.1, R10.1, R11.1, U10.16 (GND), U11.3 (GND); also elsewhere on the board
unnamed: B1.1 (+), R1.1, TP1.1, TP3.1
unnamed: Q1.1 (G), U11.7 (RESET)
unnamed: R6.2, R7.1, U11.8 (SENSE)
unnamed: TP5.1, U11.4 (~MR)
unnamed: TP6.1, U11.9 (~RESET)

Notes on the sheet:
SWITCH 0-OHM JUMPERS



Board: 2 copper layers, 116.2 x 77.7 mm, 67 parts (2 on the bottom side), 83 nets.
